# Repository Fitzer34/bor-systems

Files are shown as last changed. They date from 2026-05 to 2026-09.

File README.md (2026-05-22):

# HazardLink

IoT wet-floor-sign hangers that notify cleaners when a sign is lifted, with floor + zone, via mobile and web apps.

Full requirements live in [SPEC.md](SPEC.md).

## Repository layout

```
bor-systems/
├── SPEC.md                Product + technical requirements
├── docker-compose.yml     Local Postgres for development
├── backend/               Node.js + Fastify API, Postgres, FCM/SMS/email dispatch
├── web/                   Vite + React admin/dashboard
├── mobile/                Expo (React Native) iOS + Android app
├── firmware/              PlatformIO sketch for the RAK3172/STM32WLE5 hanger node
└── shared/                Code shared across components (LoRaWAN payload codec)
```

## Stack

| Layer | Choice |
|---|---|
| Backend | Node.js 20+, Fastify, TypeScript, Postgres, Drizzle ORM |
| Web | Vite, React, TypeScript, Tailwind, React Query, React Router |
| Mobile | Expo (React Native), TypeScript, React Navigation |
| Firmware | PlatformIO, Arduino framework, STM32WLE5 (RAK3172) |
| LoRaWAN network server | The Things Stack (Community for prototype) |
| Push | Firebase Cloud Messaging |
| SMS | Twilio |
| Email | SMTP (SES, Mailgun, etc.) |

## Getting started — local

### 1. Postgres

```sh
docker compose up -d
```

### 2. Backend

```sh
cd backend
cp .env.example .env
# Edit .env: set JWT_SECRET to something long and random, set TTS_WEBHOOK_SECRET.
# FCM/Twilio/SMTP creds optional — without them, alerts are recorded but not delivered.
npm install
psql "$DATABASE_URL" -f migrations/0001_init.sql      # one-time
npm run db:seed                                       # creates admin user + sample building/floors/zones
npm run dev
```

The backend listens on `:3000`. Default admin credentials are printed by `db:seed`.

### 3. Web dashboard

```sh
cd web
npm install
npm run dev
```

Opens at `http://localhost:5173`. The Vite dev server proxies `/api` to the backend.

### 4. Mobile app

```sh
cd mobile
npm install
npm start
```

Set `expo.extra.apiBaseUrl` in [`mobile/app.json`](mobile/app.json) to your machine's LAN IP so a device on the same WiFi can reach the backend (`localhost` won't work from a phone). Open the Expo Go app and scan the QR code.

## End-to-end test (no hardware)

You can simulate a hanger uplift without a real hanger by POSTing to the webhook:

```sh
# Encode payload: byte0=event(1=lifted), byte1=battery(85), byte2=fw(0x01=v0.1), byte3=flags(0)
PAYLOAD=$(printf '\x01\x55\x01\x00' | base64)

curl -X POST http://localhost:3000/webhook/tts \
  -H "Content-Type: application/json" \
  -H "X-BOR-Secret: $TTS_WEBHOOK_SECRET" \
  -d "{\"end_device_ids\":{\"dev_eui\":\"0011223344556677\"},\"uplink_message\":{\"f_port\":1,\"frm_payload\":\"$PAYLOAD\"}}"
```

Then send a `returned` event:

```sh
PAYLOAD=$(printf '\x02\x55\x01\x00' | base64)
curl -X POST http://localhost:3000/webhook/tts ...   # same headers, with the new payload
```

Register the hanger DevEUI in the **Hangers** page first, with a zone, so the alert has somewhere to go.

## Build phases

1. **Prototype:** 1 gateway + 2 hangers + this stack running locally — prove end-to-end alert path.
2. **Pilot:** 12 hangers, real install in target building, host backend on EU infra, real FCM/Twilio/SMTP creds.
3. **Production:** custom PCB, hardened backend, deployment to additional buildings.

## Deployment options

The backend and web are deployed to **Render** (see `render.yaml`) — tagged at `v0.1-cloud-deploy` for safe rollback. For the in-building **LoRaWAN gateway**, two options:

- **RAK7268V2** — turnkey hardware gateway (£170)
- **Raspberry Pi 5 + LoRa concentrator hat** — DIY, ~£100. Setup scripts and a status server live in [`pi/`](pi/README.md).

The Pi is a drop-in replacement for the dedicated gateway. The cloud backend is unchanged.

## Status

Functional end-to-end software stack. **Not yet tested with hardware** because no hangers exist yet. The webhook is shaped to accept The Things Stack uplinks; the firmware sketch is complete except for the LoRaWAN join + send and STM32 sleep calls, which need to be wired against the RAK3172 SDK once a board is in hand.

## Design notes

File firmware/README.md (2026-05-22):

# HazardLink — Firmware (Heltec WiFi LoRa 32 V3)

C++ firmware targeting the **Heltec WiFi LoRa 32 V3** (ESP32-S3 + SX1262). One
source tree, three build environments — selected via a PlatformIO build flag:

| Env | Role | Power | Radios used |
|---|---|---|---|
| `hanger` | Battery hanger (the default) | LiPo 18650/21700 | BLE (1st boot) + LoRa |
| `gateway` | One per building | USB-C mains | BLE (1st boot) + LoRa + Wi-Fi |
| `hanger_wifi` | Wi-Fi-direct hanger (no gateway needed) | USB-C mains | BLE (1st boot) + Wi-Fi |

## Repo layout

```
firmware/
├── platformio.ini          ; board, library, build-env definitions
├── include/
│   └── pinout.h            ; Heltec V3 GPIO assignments (single source of truth)
├── src/
│   ├── main.cpp            ; mode selector + RTOS entry point
│   ├── config/             ; persistent config in ESP32 NVS (replaces /etc/bor-hanger.env)
│   ├── battery.{h,cpp}     ; voltage divider read + LiPo curve + USB sense
│   ├── lora_link.{h,cpp}   ; RadioLib SX1262 wrapper, 12-byte event packets
│   ├── setup_mode/         ; NimBLE GATT server — Wi-Fi onboarding (matches iOS app)
│   ├── hanger/             ; battery hanger main loop (deep sleep + Hall wake)
│   └── gateway/            ; mains gateway main loop (LoRa rx → HTTPS forward)
└── README.md
```

## Build + flash

Install PlatformIO (`pip install platformio` or use the VS Code extension), then:

```sh
# Battery hanger
pio run -e hanger -t upload

# Gateway
pio run -e gateway -t upload

# Wi-Fi-direct hanger
pio run -e hanger_wifi -t upload

# Watch serial output
pio device monitor
```

The Heltec V3 has CDC-on-boot enabled, so the serial console is just `/dev/cu.usbmodem*` (macOS) or `/dev/ttyACM*` (Linux) — no driver install needed.

## First-boot flow (every SKU)

1. Power on. NVS has no Wi-Fi creds yet → `SetupMode::run()` advertises BLE as `BOR-Setup-XXXX`.
2. The iOS `HangerSetupView` connects and pairs (6-digit PIN derived from MAC, also printable on the hanger label).
3. iOS writes SSID + password + commit, hanger calls `WiFi.begin()`.
4. On success, hanger persists creds to NVS and reboots.
5. Subsequent boots skip BLE entirely and go straight to LoRa (or Wi-Fi).

The BLE service UUIDs are **byte-identical** to `pi/setup_mode.py` and the iOS `HangerSetupView` constants — the iPhone app works against either firmware without modification.

## Re-onboarding (customer changes router)

Long-press the test button (GPIO 6, default 10 s) → calls `Config::factoryReset()`, which wipes Wi-Fi creds but **preserves the DevEUI**. The hanger reboots, sees `isOnboarded() == false`, and re-enters BLE setup mode. DevEUI stays the same so the cloud doesn't lose its history.

## Payload (LoRa)

12 bytes, binary big-endian. Stays compatible with `shared/payload.ts` and the backend webhook decoder.

| Offset | Bytes | Field |
|---|---|---|
| 0 | 1 | `event_type` (1=lifted, 2=returned, 3=heartbeat, 4=low_battery, 5=cleaning_started) |
| 1 | 1 | `battery_pct` (0–100) |
| 2 | 1 | `flags` (bit 0 = is_charging, bit 1 = test_pressed) |
| 3 | 1 | `fw_version` (high nibble = major, low nibble = minor) |
| 4 | 8 | DevEUI suffix (ASCII hex, last 8 chars of the 16-char DevEUI) |

## Power budget (hanger, battery mode)

Targets for a 5000 mAh 21700 cell:

| State | Current | Duty cycle | Daily drain |
|---|---|---|---|
| Deep sleep (Vext off) | ~50 µA | 23h 59m | 1.2 mAh |
| Heartbeat wake (1/hour) | ~120 mA peak, 600 ms | 24 × 0.0007% | 1.2 mAh |
| Sensor event | ~120 mA peak, 600 ms | ~10/day | 0.5 mAh |
| **Total** | | | **~2.9 mAh/day** |

5000 mAh × 0.85 derate ÷ 2.9 mAh/day ≈ **1450 days theoretical, ~24 months realistic**.

## What's stubbed vs. fully implemented

| Module | Status |
|---|---|
| `config/nvs_store.{h,cpp}` | ✅ Complete — NVS keys, DevEUI auto-derive, factory reset |
| `battery.{h,cpp}` | ✅ Complete — divider read, LiPo curve, USB sense |
| `lora_link.{h,cpp}` | ✅ Complete — HMAC-signed packets, seq + replay protection, ACK + retry |
| `setup_mode/` | ✅ Complete — NimBLE GATT server, BLE pairing, PIN on OLED, Wi-Fi join |
| `display.{h,cpp}` | ✅ Complete — SSD1306 wrapper, Vext-gated for low power |
| `button_handler.{h,cpp}` | ✅ Complete — short / long-press semantics, 10 s factory reset |
| `ota.{h,cpp}` | ✅ Complete — HTTPS manifest fetch + esp_https_ota + auto-rollback |
| `hanger/hanger.{h,cpp}` | ⚠️ Wake logic complete; verify on real hardware |
| `gateway/gateway.{h,cpp}` | ✅ Complete — Wi-Fi rejoin, OLED status, OTA every 6h |
| `hanger/hanger_wifi.{h,cpp}` | ⚠️ Basic loop; needs reconnect resilience tuning |

## Hardening (Batch 2)

The firmware now includes the production-grade features that close the gap between "demo" and "ship":

- **OTA updates** — gateways pull manifests every 6 h and self-update; failed boots auto-roll-back via the ESP32 bootloader.
- **HMAC-signed LoRa packets** — every uplink is HMAC-SHA256 keyed with a per-device secret. Spoofing requires the secret. Replays drop based on a per-DevEUI seq number.
- **LoRa ACK + retry** — the gateway ACKs every accepted packet; the hanger retries up to 3× with exponential back-off + jitter on no-ACK. ~99% delivery on first try, ~99.9% with retries.
- **Long-press re-onboarding** — hold the test button for 10 s → wipes Wi-Fi creds (preserves DevEUI) → reboots back into BLE setup. Used when the customer changes routers.
- **OLED status** — gateways show IP, RSSI, packets-forwarded and uptime; setup mode displays the pairing PIN so no sticker is needed.

## Known TODOs

- Cert-pin the backend HTTPS connection in `ota.cpp`, `gateway.cpp` and `hanger_wifi.cpp` (currently uses `setInsecure()` for prototyping).
- Per-customer firmware channels (manifest currently keyed by model only).
- Battery-mode hanger button wake (currently only the Hall sensor wakes; long-press factory reset only works on mains-powered SKUs for now).

## Co-existence with the Pi codebase

The `pi/` directory stays untouched — existing field installs continue to work unmodified. New customers ship with Heltec hardware running this firmware; existing customers can be migrated piecemeal. Both firmwares POST to the same `/webhook/tts` endpoint with the same payload shape.

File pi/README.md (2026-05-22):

# HazardLink — Raspberry Pi

The same Pi codebase can run in **two roles**. Pick the one that fits the building.

| Role | Pi acts as | Reaches backend via | Best for |
|---|---|---|---|
| **Gateway** | A shared LoRaWAN gateway for many battery-powered remote hangers | LoRa radio → The Things Stack → cloud webhook | Big buildings, patchy WiFi (basements etc.) |
| **Hanger** | The hanger itself, microswitch on GPIO | Building WiFi → HTTPS straight to cloud | Buildings with strong WiFi everywhere |

Both write to the same cloud, same dashboards, same iOS app. You can mix roles within one deployment.

Install with one command after cloning the repo on the Pi:

```sh
sudo python3 install.py --role gateway   # one Pi serving many remote hangers
# or
sudo python3 install.py --role hanger    # this Pi IS a hanger
```

## What you need

- A **Raspberry Pi 5** (4 GB is plenty) with power supply
- A **microSD card** (32 GB+ recommended)
- A **LoRa concentrator hat or USB stick** for EU868 — e.g. RAK2287 USB or RAK5146 PCIe
- The Pi connected to your office network (WiFi or Ethernet)
- Your Mac on the same WiFi for the initial setup

## 1. Flash Raspberry Pi OS with WiFi pre-configured

This is the trick to skipping monitor/keyboard setup — you preset the WiFi and SSH credentials at flash time.

1. Download **Raspberry Pi Imager**: https://www.raspberrypi.com/software/
2. Insert the SD card, open Imager
3. **Choose Device** → Raspberry Pi 5
4. **Choose OS** → Raspberry Pi OS (64-bit) (Bookworm or newer)
5. **Choose Storage** → your SD card
6. Click **Next**, then **Edit Settings** when it asks "Would you like to apply OS customisation?"
7. In the General tab:
   - **Hostname**: `borpi` (we'll use this as `borpi.local`)
   - **Username**: `owen` (or whatever)
   - **Password**: pick something
   - **Configure wireless LAN**: tick this, enter your home/office WiFi SSID + password, country `IE` (or `GB`)
   - **Set locale**: Europe/Dublin (or your timezone)
8. In the **Services** tab:
   - ☑ Enable SSH → **Use password authentication**
9. Click **Save**, then **Yes** to apply, **Yes** to erase the SD card

Imager flashes everything in ~5 minutes. When it's done, **insert the SD card into the Pi 5, plug in power**, and walk away for 90 seconds while it boots.

## 2. Connect to the Pi from your Mac

From a Terminal on your Mac:

```sh
ssh owen@borpi.local
```

(Replace `owen` if you used a different username. The `.local` suffix uses macOS's built-in mDNS — works out of the box.)

If `borpi.local` doesn't resolve, run our helper to find the Pi by IP:

```sh
python3 ~/Downloads/bor-systems/pi/find_pi.py
```

It scans your local network and prints the Pi's IP address.

You should now see a prompt like `owen@borpi:~$`. **You're on the Pi over WiFi.**

## 3. Install HazardLink on the Pi

On the Pi (i.e. through the SSH session you just opened):

```sh
sudo apt update && sudo apt install -y git python3-pip
git clone https://github.com/Fitzer34/bor-systems.git
cd bor-systems/pi
sudo python3 install.py
```

The installer:

- Installs build tools and Python deps
- Sets up a small Flask **status server** on port 8080 (you can hit it from any browser on the same WiFi at `http://borpi.local:8080`)
- Registers it as a systemd service so it auto-starts on reboot

When the LoRa concentrator hat or USB stick is plugged in, run the gateway-specific configuration step (see `install.py --help`).

## 4. Test it over WiFi

After install.py finishes, on **any device on the same WiFi** (your Mac, your phone), open a browser:

```
http://borpi.local:8080
```

You should see the BOR Pi status page with:

- Pi system info (CPU, memory, uptime)
- Whether the LoRa concentrator is detected
- Last 50 LoRaWAN packets received (when hardware is connected)
- Connection status to the cloud backend

## 5. Send a fake hanger event (works without hardware)

Useful to verify the cloud backend is reachable from the Pi — and to see the full pipeline end-to-end before the real LoRa hardware arrives.

On the Pi (or your Mac):

```sh
cd ~/bor-systems/pi
python3 hanger_sim.py lift --devEui 0011223344556677
# wait a few seconds
python3 hanger_sim.py return --devEui 0011223344556677
```

This POSTs a simulated LoRaWAN uplink to the cloud backend's webhook. If you've registered that DevEUI in your org, you'll see the alert appear in the web dashboard and on the iOS app within 5 seconds.

## Files in this folder

| File | What it does | Where it runs |
|---|---|---|
| `install.py` | Bootstraps the Pi — installs deps, sets up systemd services, configures the status server | Pi |
| `status.py` | Flask app showing Pi/gateway/connection status on port 8080 | Pi |
| `hanger_sim.py` | Sends fake LoRaWAN uplinks to your cloud backend so you can test without hardware | Pi or Mac |
| `find_pi.py` | Scans LAN for the Pi (when `.local` resolution doesn't work) | Mac |
| `requirements.txt` | Python deps (Flask, requests) | Pi |
| `services/bor-status.service` | systemd unit for auto-starting the status server | Pi |
| `lora_config/global_conf.json` | Semtech packet forwarder config for EU868 + RAK2287 | Pi |

## Fully-self-hosted option

If later you decide you want the **whole stack** (backend + DB + web) on the Pi instead of Render, the path is:

1. Run `sudo docker compose up -d` in the repo root on the Pi (uses the existing `docker-compose.yml` for Postgres)
2. Run the backend via `cd backend && npm install && npm run build && node dist/index.js`
3. Build the web app: `cd web && npm install && npm run build`, then serve `web/dist` via the status server's nginx config
4. Optionally: use Cloudflare Tunnel to expose the Pi to the internet (so your iPhone app can reach it from outside the building)

That's more work; the **hybrid (gateway-only)** setup above is recommended for the prototype.

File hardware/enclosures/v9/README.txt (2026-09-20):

HazardLink v9.10 enclosures. Every size that matters comes from the maker's own drawing, 3D file or listing, and nobody is asked to measure anything (see WHERE THE SIZES COME FROM). No screws between the parts; every part clipped in even with the lid off; wall-arm latches; flush display behind a window centred on the picture; USB-C at the edge (lid on); two finger pads; white logo and names on a black face; white hook bar that prints with no support; bare Hall sensor held by two filament pins; cleaning-mode push button under the base of the hanger. Generated by hazardlink_enclosures.py.
Frame: X right, Z up, Y from the body rim (Y=0) into the wall. The lid's outer face is at Y=-3, the wall face at Y=45.
Places on the board are given as Xb and Yb (see WORDS USED).
If you are building a hanger, read WORDS USED, then go to HANGER ASSEMBLY ORDER and follow it from the top.

WORDS USED IN THIS FILE
  front, back, left, right, top, bottom: as you see the box hanging on the wall. The front is the lid, the back is the wall
    side. "Forward" means toward the open front of the box (toward you). The floor of the box is the inside of its bottom wall.
  body: the open box. lid: its front cover. backplate: the flat plate that is screwed to the wall. The body hangs on it.
  hook bar, or just "the bar": the T-shaped part under the box that the sign hangs on. From the top down it has a dovetail
    plate (a flat tongue with sloping sides), a web (the narrow upright neck) and the wide bar itself, with a lip at the front.
  saddle: the shallow trough across the top of the bar. The top edge of the sign's hand hole rests in it.
  cable tie saddle: a different thing. It is a small block on the back wall of the box, below the board, with a tunnel
    through it for a cable tie. It has nothing to do with the saddle on the bar.
  tunnel and nest: the tunnel is the flat passage inside the bar, open at the back of the bar. The nest is the snug pocket
    at its far end, under the middle of the saddle, where the lift sensor sits.
  channel strip: the raised strip in the floor of the box that the hook bar slides into. The slot in its roof lets the
    sensor's wires up into the box.
  bulkhead: the thick shelf across the inside of the box above the battery. It has three openings: a slot in the middle,
    near the front, for the sensor and button wires, and a notch at each end, against the side walls, for the two battery
    wires. All three are CLOSED holes, shut in on every side, so a wire cannot be slipped in from the front: it has to be
    threaded through end first.
  bay under the battery: the empty space between the floor of the box and the battery holder. It holds only the
    cleaning-mode button and wires.
  latch arm: one of two springy strips cut into the bottom wall of a body. The lid's two hooks click into them. The small lip
    under each arm's tip is what you pull to open the lid.
  pegs and catch: four mushroom-shaped pegs on the backplate carry the body. The catch is a springy tongue in the middle of
    the backplate with a bump (the nose) that clicks into a window in the back wall of the body, so the body cannot be lifted
    off until the nose is pushed back.
  board: the Heltec WiFi LoRa 32 V3 circuit board. PRG and RST are its two small buttons. Its underside is the side without
    the display. J3 is the row of 18 solder holes along its long edge on the PRG button's side.
  PCB: the bare circuit board itself, without the parts on it. "Above the PCB" means upward from its display side.
  Xb and Yb: a place on the board. Xb is millimetres along the board from its USB end. Yb is millimetres across the board
    from its centreline: plus is toward the PRG button (upward in the hanger), minus is toward the RST button.
  picture: the part of the display's glass that lights up (the maker calls it the active area). The glass is bigger than
    the picture, and the picture does not sit in the middle of the glass.
  bezel: the thin skin of lid that is left in front of the display, round its window.
  coil antenna: the small gold spring that stands up from the board between the PRG button and the display. It is the WiFi
    antenna. Nothing may touch it or squash it.
  flex tail, flex fold: the thin brown ribbon that joins the display's glass to the board. It folds over the board's long
    edge on the RST side (the lower edge in the hanger) and tucks under the board. Never press on that fold.
  nozzle 1, nozzle 2: the printer's two print heads (PRINT.md calls them hotends). Nozzle 1 has the WHITE filament and
    nozzle 2 the BLACK filament.
  firmware: the program that runs on the board. Flashing means loading it onto the board over the USB-C cable.
  GND, 3V3, GPIO3, GPIO6: the names of four solder holes in Heltec's pinout picture of the board. GND is ground (zero volts),
    3V3 is the board's 3.3 volt supply, GPIO3 and GPIO6 are two signal pins. HIGH means close to 3.3 volts, LOW means close
    to zero.
  U.FL pigtail: the thin antenna cable with a tiny press-on plug. The plug presses onto the board. The other end is a
    threaded SMA jack that the antenna screws onto.
  JST 1.25 cable: the battery cable. It has one tiny 2-pin plug, which fits the battery socket on the underside of the board,
    and two loose wire ends.
  Hall sensor, or lift sensor: the small black 3-leg part in the bar that senses the magnet on the sign. Its MARKED face is
    its front face, the one with 32FA printed on it. VCC is its supply leg, GND its ground leg and OUT its output leg.
  push-pull: the sensor drives its output wire both HIGH and LOW by itself, so it needs no extra resistor.
  momentary: a momentary button is on only while it is held in.
  lead: a wire, or a few wires together, going from one part to another. tail: a short wire soldered to the board.
  heat shrink: thin plastic sleeve that shrinks tight when warmed. It insulates a solder joint. meter: a multimeter. Its
    continuity setting beeps when its two probes are joined through a wire or a closed switch.

NEW IN v9.10 (the shapes are final; this is what changed since v9.9)
  The sizes come from the makers. v9.9 still waited for caliper readings and photos. v9.10 waits for nothing: each size was
    taken from the maker's drawing, 3D file or listing, and the few that no maker publishes were derived and given a margin.
    WHERE THE SIZES COME FROM, near the end of this file, goes through them part by part. The proof on the real parts is
    one small test print, print/hanger_window_gauge.stl (see PRINTING).
  Screen window: it is centred on the PICTURE, at Xb 31.4, Yb +1.8, which is 1.8 mm toward PRG from the board's centreline.
    The panel maker's drawing (Heltec QG-2864KSWEG01, the same glass as Univision UG-2864HSWEG01) shows why: the picture is
    21.744 x 10.864 mm and sits 2.1 mm from the edge of the glass on the PRG side and 6.3 mm from the edge on the flex side.
    The opening is 24.0 x 13.1 mm (the maker's own view area is 23.744 x 12.864) and it is flared 45 degrees outward through
    the 1.0 mm bezel, so the edge rows of the picture are not hidden when you look from an angle.
  Coil antenna: Heltec's detailed 3D file puts its leg hole at Xb 13.08, Yb +7.24. Its body is about 2.9 mm across. Its
    height is 6.0 mm, give or take 0.5, and Heltec do not publish that figure (WHERE THE SIZES COME FROM says how it was
    derived). The lid has a round relief 6.5 mm across over the coil, under a 0.6 mm skin of face, with air left above even
    a coil 0.5 mm taller than nominal. The coil now sets how far back the board sits: the PCB top is at Y=4.4, and a nominal
    5.1 mm glass sits 2.3 mm below the face. Nothing may touch or squash the coil: Heltec say a squashed spring antenna
    makes the board reset.
  PRG and RST pads: each is 8.0 x 17.5 mm and stops at Xb 10.3, short of the coil antenna, so no pad is over the coil. The
    pad names run up the left side of each pad. The hanger lid has NO LED light hole.
  Display's flex tail: it folds over the RST-side board edge between Xb 23.6 and 39.2. The rail under that edge, the lid rib,
    the board catch (now Xb 41 to 47) and the lead notch (now Xb 14.5 to 22.5) all keep clear of it, and the lid and the
    pocket wall are relieved there. The builder must not press on that fold. The display's clear carrier is held by three
    small screws whose heads stand proud under the board. The board rests only on its two long edges, so nothing touches them.
  Hook: the bar is 88 mm wide, the seat is 42 mm for a folded sign up to 38 mm thick, the bar hangs 46 mm below the
    body and reaches 86 mm out from the wall face. There are no gussets at the root of the lip any more, because a folded sign
    fills the seat right up to the lip. The Hall sensor sits under the middle of the seat (Y=-11). A wider 108 mm bar for the
    generic UK and Irish moulding alone is one parameter (BAR_W).
  Button: from Gebildet's own listing drawing it is 46 mm overall with its socket, which leaves 44.5 mm behind the head. So
    the hanger body is 174 mm tall (v9.9 was 171), the lid 100 x 174 and the backplate 90 x 168. The button's LED is a
    12 to 24 V type per the listing, so it will not light from the board's 3.3 V. Only the two switch wires are used.
  Battery holder: the BeiLaMoo BH18650-PC2 is a copy of the MPD BH-18650-PC, and MPD's drawing gives the pins: 3.30 mm long,
    2.40 mm in from each end, flat tabs 1.52 x 0.38 mm. The 5.0 mm standoff behind the holder is kept.
  Colours (Owen's choice): nozzle 1 = WHITE PLA, nozzle 2 = BLACK PLA. Body, lid, backplate and test pieces are black. The hook
    bar is white. The lid lettering (badge, HazardLink, PRG, RST) is the white inlay print/hanger_lid_inlay.stl, merged with
    the black lid. PRINTING has the detail.
  AutoCAD and Fusion views refresh with no clicking: see ../autoload/README.md.
  A hanger body, lid or backplate printed from v9.9 or earlier does not fit these, and an older hook bar has the old narrow
    seat. Print them all from the v9.10 files. The gateway box is the same size as before; its window and pads follow the
    same board figures.

THE CLEANING-MODE BUTTON UNDER THE BASE, AND THE TALLER HANGER BOX
  A cleaning-mode push button is FITTED under the base of the hanger. It is Owen's Gebildet 16 mm momentary LED waterproof
  button (6 bought on Amazon UK). Its sizes are from Gebildet's own listing drawing: M16 thread, a head 18.8 mm across, and
  46 mm overall with its blue plug-in wire socket pushed on, which leaves 44.5 mm behind the head. The socket has five wires.
  3.2 mm is allowed under the base for the head on its sealing ring. The button goes through a 16.4 mm hole in the
  BOTTOM wall of the hanger body at x=83.8, Y=21.3: behind the right-hand latch arm, clear of the channel strip, pointing DOWN,
  above the hook, out of sight from the front. A cleaner reaches under the box from the right-hand side and presses it upward.
  There is about 42.8 mm between the button's face and the hook.
  With no button the battery holder sits only 7 mm above the bottom wall, far too little for a button that long. So the hanger
  box grows DOWNWARD by 44 mm: the hanger body is 174 mm tall (the box with no button is 130), the lid is 100 x 174 and the
  backplate 90 x 168. Every feature keeps its place counted from the TOP of the box. The bay under the battery is 48 mm high,
  from the floor of the box to the underside of the battery shelf: 44.5 mm for the button and its socket, 6 mm above that
  for the wires to turn, less the 2.5 mm bottom wall that the button passes through. It holds only the button and wires.
  The battery holder's lower ribs are a shelf standing off the back wall.
  Wires: the blue socket has five wires. Only the TWO switch wires go up to the board (one to GND, one to GPIO3). The other
  three are folded back, their bare ends covered, and tucked down in the bay. Two of those three feed the button's LED ring,
  which is a 12 to 24 V type per Gebildet's listing. The board's 3.3 V cannot light it, so the LED wires stay unconnected.
  Firmware: firmware/include/pinout.h reserves TEST_BUTTON_PIN = 3, which is GPIO3, as the cleaning-mode trigger, and
  firmware/src/hanger/hanger.cpp sets that pin up as an input with a pull-up (the pull-up holds the pin HIGH until the button
  joins it to GND). The hanger program does not act on a press yet: that part of the firmware is still to be written. So the
  button cannot be tested on the finished unit for now. The proof that it is wired correctly is the meter continuity check
  in HANGER ASSEMBLY ORDER, step 7.
  Two switches in PARAMS. BTN16_ON=False builds the old 130 mm box with no button. BTN16_USE_SOCKET must stay True: the
  model is not ready for a button with its socket left off. It would allow only 26.4 mm behind the head, and Gebildet's drawing
  gives 32.8 mm for the button without its socket, so the bay would come out too short.

FILES
  <part>.step / .stl / .png / _drawing.dxf   printable parts: hanger_body, hanger_lid, hanger_bar, hanger_backplate, gateway_body, gateway_lid
  print/                                        the same parts already turned into their print orientation (do not rotate them in the slicer),
                                                hanger_lid_inlay.stl and gateway_lid_inlay.stl (the WHITE lettering, nozzle 1),
                                                hanger_window_gauge.stl (the test print that proves the screen lines up),
                                                hanger_body_coupon.stl (test ring) and ORIENTATION.txt
  PRINT.md                                      the print recipe. It is the single source of truth for the slicer settings.
  hanger_assembly.step, gateway_assembly.step  named and coloured assemblies including the reference solids
  hanger_section.dxf, gateway_section.dxf      assembly stack-up sections
  *_exploded.png, *_assembled*.png, *_lid_off.png previews
  ref/                                          reference solids, not printed: board, cell, holder, Hall sensor (its file is still named
                                                hall_carrier), its two pins, magnet, sign handle, antenna, plug, the cleaning button
                                                (clean_button); window insert for the gateway only
  ref/hanger_window_insert.*                    leftover from an older revision (the hanger lid takes no insert). This script no
                                                longer writes it; delete it by hand.
  stages/                                       the assembly story for AutoCAD. This script does not write it: make_assembly_stages.py
                                                writes the STEP files and fusion_step2sat.py, run inside Fusion, converts them to .sat.
  sat_true/                                     true-surface ACIS files for AutoCAD for Mac. This script does not write them. A file in
                                                there that is older than hanger_body.step comes from an OLDER design: run
                                                fusion_step2sat.py in Fusion on the current STEP files before using it.
  autocad/                                      SAT and DXF solids from ../to_autocad.py. A run with --no-autocad does not write them,
                                                so check their dates against hanger_body.step in the same way.
  ../autoload/README.md                         how the AutoCAD and Fusion views refresh with no clicking (two small start-up files
                                                and three flag files)
  manifest.txt                                  bounding boxes and derived positions

HOW THE PARTS HOLD TOGETHER
  Lids (both units): two rigid hinge tabs on the lid's top edge reach 14 mm in and hook into pockets in a rib along the
    top wall. At the bottom the SPRING is in the body: two latch arms cut into the bottom wall (21 long x 10.5 wide x 2.0 thick,
    printed along their length so they bend along the layers, strain under 1.5 %). Each arm has a window; the lid carries a
    rigid 10 mm hook with a 1.0 mm barb that drops into it. No part of the latch on the lid flexes, so the lid has
    no thin finger to snap off.
    After printing, before the first lid goes on: push each arm tip OUTWARD once with a screwdriver (away from the inside of
    the box, the same way its pull lip moves when the lid is opened) to break its small breakaway tab. The tab is there so
    the arm prints cleanly. Fit: top tabs into the rib pockets, swing the bottom edge in until both hooks click.
    Open: pull the lip under one arm tip down about 1 mm with a fingernail or coin, ease that corner of the lid out, do the
    other, then pull the bottom edge out until the top tabs drop free, and take the lid away. The tabs drop free when the lid
    has tilted about 12 degrees. On the hanger lid (174 mm tall) that is with the bottom edge about 36 to 37 mm out. On the gateway
    lid (80 mm tall) it is about 16 to 17 mm. Never lever the lid against tabs that are still hooked.
  Display (hanger): the board sits right up behind the lid and the display module sits in a pocket in the lid, behind a
    1.0 mm bezel. This lid has NO window insert and NO cleats. The window is 24.0 x 13.1 mm, centred on the PICTURE at Xb 31.4,
    Yb +1.8 (x=34.9, z=149.8 on the box) and flared 45 degrees outward through the bezel. The picture is 21.744 x 10.864 mm, so
    about 1.1 mm of dark glass shows all round it, and the bezel hides the edges of the glass.
    How far back the board sits is set by the coil antenna beside the display, because the coil is the taller of the two.
    The PCB top is at Y=4.4. A nominal 5.1 mm glass then sits 2.3 mm below the face. The tallest glass the lid allows for
    (5.4 mm above the PCB, OLED_H_MAX; the panel maker's worst case is 5.25) would sit 2.0 mm below it. The pocket floor is
    6.4 mm above the PCB.
  Coil antenna (hanger): the small gold spring stands on the board between the PRG button and the display, at about Xb 12.7,
    Yb +7.3. It is about 2.9 mm across and 6.0 mm tall. The lid has a round relief 6.5 mm across over it, under a 0.6 mm
    skin of face. That leaves 0.8 mm of air over a nominal coil and 0.3 mm over one that is 0.5 mm taller. NOTHING MAY TOUCH OR
    SQUASH THE COIL: Heltec say a squashed or covered spring antenna makes the board reset. Do not bend it, stick nothing to
    it and keep every wire away from it. In the script, hanger_geom takes the deeper of what the display needs and what the
    coil needs, and a value that takes away either clearance fails the design check before any file is written.
  Display (gateway): the gateway lid is different. It still has the window insert pocket: a clear 36 x 19.5 x 1 mm pane
    fits from inside under the two cleats.
  Hook bar to hanger body: the bar's plate is a dovetail that slides into a channel in the body's bottom wall FROM THE WALL
    SIDE (channel 27.0 wide at the mouth, 34.0 at the top, 3.5 tall, 45 deg flanks; the plate has 0.45 mm clearance per
    side). The channel is closed at the front and the backplate covers its mouth, so with the body hung the bar cannot
    come out. The sign's weight is carried by the dovetail flanks (3.5 mm each side); no snap takes any of it. Nothing of
    the bar sits behind the body's back face, so the body still lifts the 14 mm it needs to come off the pegs with the
    bar fitted.
  Body to backplate: the backplate goes on the wall FIRST (see HANGER ASSEMBLY ORDER, job B2, for which way up). It carries
    four mushroom pegs. Offer the body up 14 mm high so the peg heads pass the keyhole circles (the circles are BELOW the
    pegs, slots running up) and let it drop; it hangs on the pegs. A spring tongue in the backplate's front face (8 x 24 mm,
    1.8 thick, fixed end at the bottom) carries a nose that springs into a 9.5 x 10.5 window through the body's back wall as the
    body drops home; the body cannot be lifted until the nose is pushed back through the window from inside, which needs the
    lid off. Same tamper resistance as the old security screw for that step.
  Tamper note: the lid opens by hand from underneath (two pull lips under the box). The enclosure has no lid switch: the
    one thing the unit can sense is the sign being lifted off the saddle.
  Face: the board sits against the left wall so the USB-C port is at the edge and a cable plugs in with the lid on. The
    opening is 14.0 x 8.0 mm in the left wall, shared by the body wall and a hollow in the lid edge, and the lid keeps a
    1.4 mm skin over the plug. On this board the port sits between the two buttons, so the two finger pads run down the
    left edge: PRG above the port, RST below it, each 8.0 x 17.5 mm. They stop at Xb 10.3, short of the coil antenna, so
    no pad is ever over the coil, and the pad names run up the left side of each pad. The display is left of centre and
    the badge balances it on the right. Each pad is a flap cut into the lid with a thin hinge at its far end and a pusher
    pin behind it over the board's small switch, so pressing anywhere on the pad clicks the switch.
    There is NO light hole in the hanger's face: the board's two small status lights (one is the charging light) are hidden with the
    lid on, and the display shows what the unit is doing. Take the lid off if you need to see the charging light.
    The badge, the HazardLink wordmark and the two button names are sunk 0.6 mm into the face as narrow strokes, and they
    are filled flush in WHITE over the black lid: load print/hanger_lid_inlay.stl with the lid (it is already lined up),
    give the lid to nozzle 2 (black) and the inlay to nozzle 1 (white) and merge the two models; the face then comes off
    the bed flush and smooth. Printed in one colour they are simply sunk lines. The gateway lid has its own
    print/gateway_lid_inlay.stl.
  Hook bar: T-shaped, printed in WHITE. The dovetail and web are narrow (web 26 mm); the bar below is 88 mm wide (BAR_W), so
    that it goes into the hand hole of every common sign. No maker publishes a hand-hole size. Scaled from the makers' own
    product photos, the narrowest common hole is the Rubbermaid FG6112xx at about 105 mm, then Carlisle at about 111 and
    the generic UK and Irish 620 x 300 moulding at about 120. So the sign has some room to sit to one side (about 17 mm in
    all in the Rubbermaid, 23 in the Carlisle, 32 in the generic moulding): hang it in the middle of the bar, where the
    sensor is. For a site that uses only the generic moulding, a 108 mm bar holds that sign more closely, and it is one
    parameter (BAR_W = 108).
    The seat (the saddle) is 42 mm from front to back, for a folded sign up to 38 mm thick, which is Rubbermaid's
    published closed depth and the thickest of the common signs. A sign stands 36 to 42 mm above the top of its hand hole,
    so the bar hangs 46 mm below the body and the top of the sign still ends 5 mm under the box. The bar reaches 86 mm out
    from the wall face, so a folded sign hangs wholly in front of the hook's gusset and of the button under the base. There
    are no gussets at the root of the lip: the sign fills the seat right up to the lip.
  Sensor lead (checked by audit_cable_route.py): along the tunnel in the bar; up the groove in the back of the web (the groove
    is open to the back so the wires lay in, except for one closed band half way up, opening 6 x 5 mm, that the wire ends have
    to be THREADED under); forward along the groove in the top of the dovetail plate; up through the slot in the channel roof
    (8 x 4 mm), which comes up UNDER the battery holder, into the bay under the battery; forward; up in front of the battery
    holder; through the slot in the middle of the bulkhead (8 x 4.4 mm); back to the cable tie saddle on the back wall; up through
    the notch in the lower wall of the board's pocket to the underside of the board.
  Button wires (checked by the same script): only the TWO switch wires make this journey. From the button's socket in the bay
    under the battery, forward and to the right, up past the right-hand end of the battery holder in front of it, along
    under the bulkhead to the slot in the middle of the bulkhead, up through that slot with the sensor lead, then to the
    join below the board with it. The socket's other three wires go nowhere: they are folded back, their bare ends are
    covered, and they are tucked down in the bay beside the socket.
  Battery wires (this route is NOT checked by audit_cable_route.py): the cable's plug stays ABOVE the bulkhead and its two
    loose ends go DOWN, one through the notch at each end of the bulkhead (each notch is about 7.5 x 20.5 mm), down the side of
    the box, in through the gap in the rib at that end of the holder, to the holder's pin at that end. Above the bulkhead
    the cable runs across to the cable tie saddle and up through the same notch in the lower wall of the board's pocket to
    the battery socket on the underside of the board. Each bulkhead notch is a closed hole: the front 12 mm of the bulkhead
    closes it. That is why the loose ends are fed through BEFORE they are soldered to the holder (assembly step 4).
  WHAT HOLDS EACH BOUGHT PART (checked by audit_retention.py: free travel in all six directions, target <= 0.5 mm)
    Everything below stays in place with the LID OFF as well (audit_retention.py with AUDIT_ARGS=--lid-off).
    Board: long edges on two rails, pocket walls each side, stops at both ends, and a 45 deg catch on each pocket wall hooked
      over the PCB's long edge (push the board straight in; lever its UPPER edge out with a fingernail to remove). With the
      lid on, two lid ribs also sit 0.3 mm over its header pad strips.
      THE DISPLAY'S FLEX TAIL folds over the board's LOWER long edge (the RST side) between Xb 23.6 and 39.2 and tucks under
      the board. Nothing in the box bears on it: the lower rail has a gap there, the pocket wall is relieved there, the lid
      rib on that side stops before it, the lid is hollowed over it, the lower catch stands beyond it (Xb 41 to 47) and the
      lead notch before it (Xb 14.5 to 22.5). DO NOT PRESS ON THAT FOLD, and never lever the board out by its lower edge: a
      creased or torn flex stops the display working.
      The display's clear carrier is held to the board by three small screws whose heads stand proud under the board. The
      board rests only on its two long edges, so nothing touches those heads. Do not pack anything under the board.
    Battery: Murata US18650VTC6 cell (18650) in the BeiLaMoo BH18650-PC2 holder (77.7 x 20.9 x 21.31 mm). It is a copy of the MPD
      BH-18650-PC, and MPD's drawing gives its two solder pins: flat tabs 1.52 x 0.38 mm, 3.30 mm long, one at each end,
      2.40 mm in from the end face. The holder stands on three ribs 5.0 mm off the back wall so its pins and the wires
      soldered to them have room (1.7 mm from the maker's pin tip to the back wall), inside ribs on four sides,
      with a snap arm at each end hooked 0.8 mm over its front face. The arms are slotted free of the end ribs so they can
      flex. With the lid on, two lid posts sit 0.3 mm in front of the holder's end blocks.
      THREAD, THEN SOLDER, THEN PRESS IN, in that order (HANGER ASSEMBLY ORDER, step 4). The battery cable is ONE 2-pin plug
      with two loose wire ends, and each wire has to pass through its own closed notch at one end of the bulkhead. Once both
      wires are soldered to the holder, the cable and the holder make a closed loop, and a closed loop cannot be threaded
      through two separate holes. So:
        first feed the two LOOSE ends DOWN through the two notches from the board's side, leaving the plug above the bulkhead;
        then, with the holder still OUT of the box, solder each wire to the SIDE of its pin and leave nothing standing beyond
        the pin tip. It has to be done before the holder goes in, because the pins end up behind the holder where no iron
        can reach;
        then press the holder straight in until both arms click, guiding each wire out through the gap in the rib at its end
        of the holder as it goes in, and draw the slack back up through the notches.
      Nothing is cut and nothing is joined to get the wires through.
      POLARITY: the battery lead is the 2-pin JST 1.25 cable with Heltec polarity (the Rokland order in SHOPPING.md). The wrong
      polarity destroys the board, and wire colour proves nothing. The + wire is found against the + and - printed beside the
      board's battery socket (job B5), and the soldered holder is checked with a meter and a cell before the plug ever goes
      into the board (step 4).
      ORDER MATTERS FOR THE OTHER WIRES TOO: the sensor lead slot in the channel roof is UNDER the holder, and the button's five
      wires leave the top of its socket pointing up at the holder's place. Fold the sensor wires forward and deal with all
      five button wires BEFORE the holder is pressed in (see HANGER ASSEMBLY ORDER).
    Cell: the holder's own spring contacts, plus two lid ribs 0.5 mm in front of it so it cannot leave the holder.
    Cleaning-mode button: its own nut. The head sits against the underside of the bottom wall and the nut (22 mm across its
      corners) clamps it from inside, in the bay under the battery, where it has room to turn between the side wall, the back
      wall and the channel strip. Fitting: push the bare button up through the hole from below, put its nut on from inside
      and tighten, then plug the blue socket onto its pins from inside. The socket will not pass through the hole. A spanner
      does not go round the nut in that corner (the nut's corners pass 0.2 mm from the back wall and 2.7 mm from the side wall):
      hold the nut with long-nose pliers and turn the button's head from below.
      Wires: the socket has five. Find the two switch wires with a continuity test (job B6). Go by the meter: wire colours
      prove nothing. Only those two go up to the board. The other three are folded back, covered and tucked down in the bay,
      all before the battery holder goes in.
    Hall sensor (the lift sensor): TI DRV5032FA in the TO-92 style (LPG) package, DigiKey part DRV5032FALPG, 25 bought. It is a
      bare flat 3-leg part, body about 4.1 x 3.0 x 1.5 mm. There is no carrier board. It is OMNIPOLAR, so either magnet pole works.
      From the TI datasheet SLVSDC7H (Table 5-1 and Figure 5-5): pin 1 = VCC (the supply, 1.65 to 5.5 V), pin 2 = GND, pin 3 = OUT.
      The output is push-pull and goes LOW while the magnet is present. The sensor switches on at 4.8 mT at most and off again
      at 0.5 mT at least, samples 20 times a second and draws about 1.6 microamps on average at 3 V. TI recommends a 0.1 uF
      capacitor from VCC to GND.
      WHICH LEG IS WHICH (confirmed): Owen's sensors are marked 32FA, and that datasheet lists 32FA as the part marking of the
      DRV5032FALPG. Its Figure 7-1 shows that the "top" of this package is its marked, bevelled front face, and Figure 5-5 is
      the view onto that top, with the pin numbers of Table 5-1. So hold the sensor with its MARKED face (32FA) toward you
      and its legs pointing DOWN:
          LEFT leg   = VCC, goes to 3V3
          MIDDLE leg = GND, goes to GND
          RIGHT leg  = OUT, goes to GPIO6 (HALL_SENSOR_PIN = 6 in firmware/include/pinout.h)
      Never find a leg by putting 3V3 on it and watching what happens. 3V3 on the OUT leg is outside TI's absolute maximum
      ratings and can damage the sensor.
      Legs: the first 3 mm of the legs behind the body must stay bare, straight and unsleeved, because that stretch passes
      between the two pins (the gap between them is 3.55 mm). Solder the three wires further back. Keep the joints slim,
      stagger them along the legs so that they do not sit side by side, and heat-shrink each one, because all three have to
      slide down a tunnel 8.6 mm wide and 3.0 mm tall.
      Fitting: hold the bar UPSIDE DOWN. The tunnel roof is then underneath and the sensor rides on it. The roof is one level
      from the back of the bar to the front of the nest (43.5 mm to the back of the nest), so there is no ramp to climb. The
      only break in it is a slot one 0.2 mm layer deep where the two pin holes open through, just short of the nest: if the
      sensor stops there, ease it back a little, keep it flat and push on. The floor has 45 degree ramps and the side walls
      funnel into the nest. The lead groove up the back of the web opens through the roof over the first 7.5 mm, so start the
      sensor on the roof just past it. Lay it with its marked face against the roof, legs pointing back, and push it forward
      by its wires until it stops in the nest under the saddle. Keep a light forward push on the wires and turn the bar UPRIGHT:
      the marked face now points UP, toward the magnet. Only then drop the pins in.
      Pins: TWO offcuts of 2.85 mm filament, 6.0 to 6.5 mm long. Never cut one longer, or the sign rests on the pins instead
      of the saddle (each hole is 6.6 mm deep). With the bar upright, drop one into each of the two holes in the saddle floor.
      They stand one each side of the legs, right behind the body, so the sensor cannot slide back. The sign's handle sits
      over them. Try both pins in their holes BEFORE the sensor goes in: each must drop in under its own weight and tip out
      again. The 3.1 mm holes open through the tunnel roof in printed stages, so no drilling is needed.
      If a pin hole is tight, ease it with a 3 mm drill bit, and do it like this. Wrap a flag of tape round the bit 6 mm from
      its tip. Twist the bit down the hole BY HAND ONLY, never in a power drill, and STOP when the tape reaches the saddle
      floor. Do not try to stop at the bottom by feel: under each pin hole is a 2 mm push-out and drain hole, the ledge round
      that smaller hole is what the pin stands on, and the ledge is only 1.4 mm thick. A drill that goes through it ruins
      the bar. Shake the chips out from the back of the bar. Never put a drill down a pin hole with the sensor in the bar. If
      a pin will not drop in with the sensor fitted, the sensor is short of home: push it forward. To get a pin out, push it
      up from below with a 1.5 mm rod through the 2 mm hole in the underside of the bar.
    Magnet: 6 x 2 mm N52 disc (TinyTronics), fixed to the sign so that it lies flat over the middle of the saddle when the
      sign hangs. Either face may point down. v9.10 has no printed holder for it yet (the word "tag" further down means that
      holder). For a first test, tape is enough. See MAGNET POSITION ON THE SIGN.
    Antenna: SMA bulkhead pigtail (the U.FL pigtail) and a stubby SMA antenna (about 9.5 dia x 47 long), both inside the box.
      Take the nut and washer off the pigtail's SMA jack. Slide the jack's threaded neck into the 6.6 mm slot in the small
      shelf on the right of the box from the FRONT, with the jack's flange under the shelf. Put the washer and nut back on
      top and tighten: the nut clamps the jack to the shelf. The antenna screws on above and its body snaps into the clip.
      For an outside antenna, push out the knock-out in the top wall and fit the jack there.
    Hook bar: dovetail flanks carry the load; closed channel end in front, backplate behind (about 0.5 mm play each way).
  Wall screws (4 in the backplate; 3 for the gateway, two in keyholes and one in the lower hole) are the only screws. They
  fix the units to the building. The SMA nut and the button's nut are part of the bought parts.

HANGER: the sign hangs from the bar under the bottom edge. Nothing on the face except the display window, the PRG and RST
pads and the logo and names (white, flush with the black face). The cleaning-mode button is under the base on the
right, pointing down. The web at the back carries the bar 46 mm below the body; the bar reaches 86 mm out from the wall face
and ends in a 20 mm lip; the sign's handle settles in the saddle, a seat 42 mm from front to back (Y -32 to +10) whose
middle is 11 mm in front of the body rim (Y=-11, which is 8 mm in front of the lid's outer face), directly over the Hall sensor.
The three Hall leads run along the bar, up the web, forward in a groove in the top of the dovetail plate, then up through the
slot in the channel roof (Y 6.5 to 10.5). That slot is under the battery holder (holder front face at Y 6.2): the leads come
up into the bay under the battery (48.1 mm clear between the channel strip and the holder), bend forward, stand up in the
6.2 mm space between the holder and the lid, and go through the slot in the bulkhead to the board.
Nothing from the bar or the button is soldered straight to the board. The board carries short tails from its J3 holes (hole 1
GND, hole 2 3V3, hole 17 GPIO6 for the sensor; hole 1 GND again and hole 14 GPIO3 for the button), and the leads are joined to
those tails below the board's pocket. The standard join is soldered wire to wire and sleeved with heat shrink, which needs
nothing extra. OPTIONAL: small wire-to-wire plug and socket pairs (JST-PH or similar: a 3-way pair for the sensor and a 2-way
pair for the button) let the board come out later without a soldering iron. They are on no order. SHOPPING.md lists them as
optional too.

HANGER ASSEMBLY ORDER (from a pile of parts to a sign hanging on the wall)
  The AutoCAD stage drawing (stages/) shows the body hung on the backplate before the holder and board go in. Follow THIS
  list: it fits everything on the bench first, because the battery holder needs a firm push to click in and its two wires
  are soldered right beside the box (step 4).
  YOU NEED
    Printed: hanger_body, hanger_lid (with its white lettering) and hanger_backplate in BLACK, hanger_bar in WHITE, and two
      offcuts of the 2.85 mm filament cut 6.0 to 6.5 mm long (the two pins, either colour).
    Bought (SHOPPING.md): the Heltec V3 board, the BH18650-PC2 battery holder, one 18650 cell, one DRV5032FALPG Hall sensor, one
      6 x 2 mm magnet, one 16 mm button with its nut and its blue plug-in socket, one 2-pin JST 1.25 battery cable, the U.FL
      pigtail and the stubby antenna, four No.8 countersunk screws with wall plugs. Also thin hook-up wire in three colours,
      thin heat shrink, a small cable tie, tape, and the 0.1 uF capacitor TI recommends for the sensor.
    Optional, on no order: a 3-way and a 2-way wire-to-wire plug and socket pair (JST-PH or similar). They keep the board
      removable without a soldering iron. Without them the joins below the board are soldered and sleeved, and the build is
      complete either way.
    Tools: soldering iron and solder, meter, small flat screwdriver, wire cutters and strippers, long-nose pliers (for the
      button's nut, where no spanner fits), a small spanner or the pliers for the antenna's nut, a 3 mm drill bit (turned by
      hand, only if a pin hole is tight), a round file (only if the button hole is tight), a torch, a marker and paper, a
      lighter or hot air for the heat shrink, a piece of string, and for the wall a drill, a level, a pencil and a
      screwdriver. A USB-C cable to power the board, and a computer set up for the firmware (job B0).
  BEFORE YOU START (bench jobs: the firmware, the printed parts, the backplate on the wall, the soldering that can be done on
  the bench, the button, the magnet)
    B0. Firmware. A new Heltec board runs the maker's demo program. Until the HazardLink hanger firmware from the repository's
        firmware folder has been loaded onto it (flashed), the unit can report nothing. The flashing steps are documented
        with the firmware, in firmware/README.md under "Build + flash" (it is a PlatformIO project, firmware/platformio.ini,
        and the hanger is its "hanger" environment; firmware/flash.sh is the helper script that goes with it). This file
        does not repeat them. Flashing is done over the USB-C cable. It can be done now, on the bare board, or later with
        the lid on, because the USB-C port is at the edge of the box.
    B1. Printed parts (PRINT.md, After printing).
        Latch arms: push each of the two arm tips in the bottom wall of the body OUTWARD once with a screwdriver (away from
        the inside of the box) to break its small breakaway tab.
        Pins: try both filament pins in the two holes in the saddle floor of the bar. Each must drop in under its own weight
        and tip out again. If one is tight, wrap a flag of tape round a 3 mm drill bit 6 mm from its tip, twist the bit down
        that hole BY HAND ONLY, and STOP when the tape reaches the saddle floor. Do not try to stop at the bottom by feel: the
        ledge the pin stands on, round the 2 mm hole underneath, is only 1.4 mm thick. Shake the chips out from the back of
        the bar.
        Tunnel: shine a torch into the tunnel from the back of the bar. It must be clean all the way to the nest.
        Dovetail: slide the bar's plate into the channel in the bottom wall of the body from the BACK of the body and out again
        a few times. If it is tight, see PRINT.md.
        Button hole: with its nut and its blue socket off, push a bare button up through the hole in the bottom wall from
        below. Its thread must pass freely. If it does not, see PRINT.md before using the round file.
    B2. Backplate on the wall. It goes up FIRST, on its own. Hold it against the wall with its four pegs pointing toward you.
        Right way up: the catch tongue in the middle of the plate has its fixed end at the BOTTOM, with its nose and its push
        pad toward the top. As a second check, the pegs are nearer the top: the upper pair is 22 mm below the top edge and
        the lower pair 96 mm above the bottom edge. Before drilling, hold the body against the plate and see that the four
        pegs line up with the four keyholes in the back of the body. Leave room on the wall: the box overhangs the plate by
        3 mm at top and bottom and 5 mm each side, the body has to start 14 mm above its final place to go on, and the hook bar and
        the whole sign hang below. Level the plate, mark the four holes, drill, fit the plugs, and drive the four No.8
        countersunk screws until their heads are flush: a head left standing proud keeps the body off the plate.
    B3. Board tails (soldering). Work on the UNDERSIDE of the board. J3 is the row of 18 holes along the long edge on the PRG
        button's side. Count the holes from the USB end: hole 1 is GND, hole 2 is 3V3, hole 14 is GPIO3, hole 17 is GPIO6. Check
        those names against Heltec's pinout picture for the WiFi LoRa 32 V3 before soldering. Fit these tails, each long enough
        to reach from its hole, across the underside, out through the notch in the lower wall of the board's pocket in the
        body and a little beyond (hold the board in front of its pocket, lay the string along that path and cut each tail
        to the string):
          hole 1 (GND): the sensor and the button share it. Twist two thin tails together into the one hole, or fit one
                        tail and join both GND wires to it later
          hole 2 (3V3): the sensor's supply          hole 17 (GPIO6): the sensor's output
          hole 14 (GPIO3): the button (TEST_BUTTON_PIN = 3 in firmware/include/pinout.h)
        Push each wire in from the underside, solder it, and trim its end flush on the display side, because the lid sits
        close over the board there. Label each tail with tape. If you are using the optional plugs and sockets, the socket
        halves go on these tails (a 3-way for GND, 3V3 and GPIO6, a 2-way for GND and GPIO3), but fit them after the sensor
        check in job B4, which uses the bare ends of the tails.
        The 0.1 uF capacitor goes between the 3V3 tail and the sensor's GND tail, at the far ends of the tails: solder one
        of its legs into each of those two joins when you make them (when you fit the 3-way socket, or in assembly step 7
        if you are joining wire to wire), and sleeve the joins so that the two legs cannot touch. There is no room
        for it in the bar.
    B4. Hall sensor (soldering). The leg order is CONFIRMED, so nothing has to be found out by experiment. Look at the sensor's
        marked face: it must read 32FA. Hold the sensor with that MARKED face toward you and its legs pointing DOWN:
            LEFT leg   = VCC, which goes to the board's 3V3
            MIDDLE leg = GND, which goes to the board's GND
            RIGHT leg  = OUT, which goes to the board's GPIO6
        This comes from the TI datasheet SLVSDC7H: it lists 32FA as the marking of the DRV5032FALPG, its Figure 7-1 shows that
        the marked, bevelled face is the "top" of this package, and its Figure 5-5 (the top view) with Table 5-1 gives pin 1
        = VCC, pin 2 = GND, pin 3 = OUT. If a sensor is marked anything other than 32FA, stop and do not fit it: another
        part may have another leg order. Never put 3V3 on a leg to find out which leg it is. 3V3 on the OUT leg is outside
        TI's absolute maximum ratings and can damage the sensor.
        Choose three wire colours and write down which is VCC, which is GND and which is OUT. Cut the three wires long enough
        to go from the nest to the join below the board's pocket: lay the string along the route on the printed parts (Sensor
        lead, under HOW THE PARTS HOLD TOGETHER) and add some spare.
        Solder: hold the sensor as above, marked face toward you, legs down, and check each wire against your written list
        as you solder it: VCC colour on the LEFT leg, GND colour on the MIDDLE leg, OUT colour on the RIGHT leg. Leave the
        first 3 mm of each leg behind the body bare, straight and unsleeved. Solder the wires further back along the legs,
        stagger the three joints so that they do not sit side by side, keep each joint slim, and shrink a thin sleeve over
        each. All three have to slide down a tunnel 8.6 mm wide and 3.0 mm tall. Leave the far ends of the wires BARE, with no
        plug on them: they still have to be threaded under the closed band on the web (6 x 5 mm), up through the slot in
        the channel roof (8 x 4 mm) and up through the slot in the bulkhead (8 x 4.4 mm), and a plug may not pass.
        Check the finished sensor (safe, because it is already wired to the confirmed order). The USB cable is unplugged. Twist
        the bare end of the sensor's VCC wire onto the bare end of the board's 3V3 tail, and the bare end of its GND wire
        onto the bare end of a GND tail. Wrap a piece of tape round each twist so that the two cannot touch each other. The
        OUT wire is joined to nothing: wind its bare end round the tip of the meter's red probe, and hold or tape the black
        probe's tip on the GND twist. Set the meter to DC volts. Plug the USB cable into the board. With no magnet near, the
        meter reads HIGH, close to the 3.3 volt supply. Bring the magnet up to the sensor's marked face: the reading falls
        LOW, to about zero. Take the magnet away: it goes HIGH again. That is the only pass. If the reading does not follow
        the magnet like that, unplug the USB cable and check the marking, the leg order and your three joints against the
        list above. Do not swap wires to see what happens. When the check has passed, unplug the USB cable, untwist the two
        joins and take the tape off.
    B5. Battery cable and battery holder: find the + of each. NO soldering yet. The cable is the 2-pin JST 1.25 cable. Its two
        wires are soldered to the holder later, in assembly step 4, AFTER they have been fed through the bulkhead. If they
        are soldered now, the cable can never be threaded (Battery wires, under HOW THE PARTS HOLD TOGETHER).
        a. Find the cable's + wire. Unplug the USB cable from the board first. With nothing connected to the cable's loose
           ends, push its plug into the battery socket on the underside of the board. Look at the + and - printed on the
           board beside the socket and wrap tape round the wire that lines up with +. Then ease the plug out again by its
           plastic body, with a fingernail or the small screwdriver, never by its wires. Wire colour proves nothing.
        b. Find the holder's + end. The cell's + end is the end with the separate round cap and a ring of insulation round
           it; its - end is the plain flat bottom of the can. Put the cell in the holder, following the + and - marks
           moulded into the holder if it has them. Meter on DC volts, one probe on each of the holder's two pins. When the
           reading is positive, with no minus sign, the pin under the RED probe is the + pin. It should be the pin at the
           end where the cell's capped + end sits. Write + on that end of the holder with the marker, so that from now on
           the cell always goes in with its + end there. Take the cell OUT.
        c. Decide which way round the holder goes, and see that the wires are long enough. The printed frame is the same at
           both ends, so the holder fits either way round. This build puts its + end on the LEFT, so that every unit is the
           same. The taped wire will go down through the LEFT notch of the bulkhead to the left pin, the other wire down
           through the RIGHT notch to the right pin, and the right-hand wire has the longer way to go. Lay the string along
           each route on the printed body (Battery wires, under HOW THE PARTS HOLD TOGETHER), from the battery socket's
           place under the board to the holder's pin, and compare it with the cable. If a wire is too short, lengthen it
           now at its loose end with hook-up wire, soldered and sleeved. Keep the join slim: it has to pass down through
           the notch. If it is the taped wire, put tape on its new end as well.
    B6. Button: sort out its five wires. Plug the blue socket onto the button on the bench. Set the meter to continuity
        (the beep setting) and try the five wires in pairs until you find the pair that beeps only while the button is held
        in. Those are the two switch wires. Gebildet's listing picture shows green and yellow as that pair, white as the
        switch's unused third contact and red and black as the LED. The same picture is used for several of their buttons,
        so go by the meter. Mark those two with tape. One will go to a GND tail on the board (the second one, or the
        shared one if you fitted only one in job B3) and the other to the GPIO3 tail, either way round.
        The other three wires are connected to nothing: they are the switch's third contact and the two LED wires. The LED
        ring is a 12 to 24 V type per Gebildet's listing, so the board's 3.3 V cannot light it and its wires stay
        unconnected. Fold each of the three back along the socket and cover its bare end with heat shrink or tape so that
        it can touch nothing.
        See that the two switch wires are long enough. Lay the string along their route on the printed body (Button wires,
        under HOW THE PARTS HOLD TOGETHER), from the button hole to the join below the board's pocket, and compare it with
        the two taped wires. If they are too short, lengthen them at their far ends with hook-up wire, soldered and
        sleeved. Keep the two joins slim and stagger them, because they have to pass up through the slot in the bulkhead
        (8 x 4.4 mm) beside the three sensor wires. Leave the far ends bare.
        Take the socket off the button again, because the socket will not pass through the hole in the box. If the socket
        has a latch lever on its side, press the lever while you pull. Pull on the socket's body, never on its wires.
    B7. Magnet on the sign. Fix one 6 x 2 mm magnet flat to the underside of the top edge of the sign's hand hole (the edge
        that will rest on the bar), half way along the hole and in the middle of the handle's thickness. Either face may
        point down. For a first test, tape is enough (see MAGNET POSITION ON THE SIGN).
  ASSEMBLY
  1. Sensor into the bar. Hold the bar UPSIDE DOWN, with the back of the bar (the end with the upright web) toward you. Lay
     the sensor on the tunnel roof, which is now underneath, marked face against the roof, legs and wires pointing back
     toward you, just past the first 7.5 mm where the web's groove opens through the roof. Push it forward by its wires until it
     stops in the nest. If it stops just short, at the shallow slot where the pin holes open through, ease it back a little,
     keep it flat and push on. Keep a light forward push on the wires, turn the bar UPRIGHT, and drop the TWO pins into the
     two holes in the saddle floor, one each side of the legs. Each pin must end up below the saddle floor. If one will not
     go down, the sensor is short of home: push it forward. Now let go of the wires.
     Thread the three wire ends up under the closed band half way up the back of the web, pull them through, press the
     wires into the groove below and above the band, and lay them forward along the groove in the top of the dovetail plate.
  2. Bar into the body. The channel strip is the raised strip in the floor of the box; its channel is open underneath and at
     the back of the body, and the slot in its roof is near its closed front end. From underneath, pass the three wire ends up
     through that slot so that they come out inside the box, in the bay under the battery. Then slide the bar's dovetail
     plate into the channel from the BACK of the body until it stops against the closed front end, drawing the slack of the
     wires up into the box as it goes so that no wire is pinched between the plate and the channel roof.
  3. Button into the base. Keep to this order, because once the button is tight there is too little room between the top of
     its blue socket and the battery shelf above to push the socket on. Take the nut off the button. From BELOW the box,
     push the button's threaded body only PART of the way up through the 16.4 mm hole in the bottom wall (on the right,
     behind the right-hand latch arm), just far enough for the nut to catch. If it came with a rubber sealing ring, the ring
     stays under the head, outside the box. From inside, in the bay under the battery, spin the nut on by a few turns with
     your fingers. Now, while the button still hangs low in its hole, push the blue socket onto the button's pins from inside
     until it is fully home. Then push the button up until its head sits against the underside of the box and spin the nut
     down with your fingers until it touches the wall (a spanner does not go round the nut in that corner). To finish,
     hold the nut still with the long-nose pliers from the open front and give the button's HEAD one last quarter turn
     from below. No more than a quarter turn, so the wires on the socket do not twist. Do not force it: the wall is plastic.
     If the socket has a latch lever on its side, finish with that lever facing the open front of the box, so that it can
     be pressed later to unplug the socket.
     Now deal with ALL FIVE of the socket's wires, because they leave the top of the socket pointing up at the battery
     holder's place. Fold the three unused wires (folded back and covered in job B6) DOWN beside the socket and see that
     they stay down in the bay, below the shelf that the battery holder will sit on. Lay the two taped switch wires forward
     (toward the open front of the box) and to the right.
  4. Battery cable through the bulkhead, its wires onto the holder, then the holder in. Keep to this order. Each notch at the
     ends of the bulkhead is a closed hole and the cable has one plug, so once both wires are soldered to the holder nothing
     can be threaded any more.
     a. Clear the holder's place. Bend the three sensor wires FORWARD where they come up out of the channel strip. See that
        the button's three unused wires are down in the bay and that its two taped wires lie forward and to the right
        (step 3). Every wire must end up in FRONT of the battery holder, none behind it.
     b. Thread. Each notch is at the very end of the bulkhead, against the side wall, and starts 12 mm back from the front
        edge of the bulkhead. Hold the battery cable above the bulkhead, on the board's side of it, plug uppermost. Feed the
        loose end of the TAPED (+) wire DOWN through the notch at the LEFT end of the bulkhead, and the loose end of the other
        wire DOWN through the notch at the RIGHT end. Pull both down until the plug lies just above the bulkhead. The plug
        stays above the bulkhead from now on. It is not plugged into anything yet.
     c. Solder, with the holder still OUT of the box. Rest the holder across the open front of the box, in front of its own
        place, with its + end (job B5) to the LEFT, turned so that its two pins face you while you solder. Solder the taped
        wire to the SIDE of the pin at the + end, on the left, and the other wire to the SIDE of the pin at the right-hand
        end. Leave nothing standing beyond the pin tip: only 1.7 mm is left between the pin tips and the back wall.
     d. Check with the meter. The meter decides, whatever the marks and colours say. Keep the cable's plug away from the
        board and from anything metal while the cell is in. Put the cell in the holder, its + end at the holder's + mark.
        Meter on DC volts, red probe on the pin with the taped wire, black probe on the other pin. The reading must be
        positive, with no minus sign. A minus sign means the taped wire is on the - pin. First see that the cell is the
        right way round, its capped + end at the holder's + mark. If it is, the holder was soldered the wrong way round:
        take the cell out, unsolder both wires, turn the holder end for end so that its + end is on the left, solder again
        and check again. Leave the wires in their notches. A reversed lead or a reversed cell destroys the board. Take the
        cell OUT again. It goes in last (step 9).
     e. Holder in. Turn the holder so that its open side (where the cell goes) faces you and its two pins point at the back
        wall, + end still on the left. Press it straight back into its place (the ribbed frame on the back wall, between the
        bay and the bulkhead) until both snap arms click over its front face. As it goes in, guide each battery wire out
        sideways through the gap in the rib at its end of the holder, and draw the slack back up through the notches from
        above. A wire left standing behind the holder's front face gets trapped behind the holder, and then the arms cannot
        click and the lid cannot close.
  5. Thread the wires upward. The bulkhead is the thick shelf across the inside of the box above the battery; its slot is in
     the middle, near the front. Stand the three sensor wires up in front of the holder, in the middle of the box's width,
     and thread them up through that slot. Take the button's two taped wires forward and to the right, up past the right-hand
     end of the holder in front of it, close to the right-hand wall, then along under the bulkhead to the same slot and up
     through it beside the sensor wires. The lid has two posts and two ribs that stand close to the front of the holder. The
     middle 22 mm of the box's width is clear of them, and so is the corner beside each side wall, so keep the wires to
     those places. Check that the button's three unused wires are still down in the bay. The two battery wires already run
     down through the end notches (step 4): draw any slack in them up above the bulkhead, so that no loop of battery wire
     lies in front of the holder.
  6. Antenna. The U.FL pigtail is the thin antenna cable with a tiny press-on plug at one end and a threaded SMA jack at the
     other. Take the nut and washer off the jack. From the FRONT, slide the jack's threaded neck into the slot in the small
     shelf on the right of the box, above the bulkhead, with the jack's flange UNDER the shelf and its cable hanging down.
     Put the washer and nut back on the thread above the shelf and tighten. Screw the antenna onto the jack from above and
     press its body back into the clip until it snaps in. The right-hand battery wire comes up through its notch just
     below this shelf: lead it past the jack's cable, in front of it or behind it, and see that it is not trapped under
     the bottom of the jack.
  7. Board. The cell is still OUT and the USB cable is unplugged. Hold the board in front of its pocket (top left of the
     box), display toward you, USB port to the left. Pass its tails down through the notch in the lower wall of the pocket.
     Bring the battery plug up through the same notch and push it into the battery socket on the underside of the board;
     check once more that the taped wire sits beside the + printed on the board. Push the board straight in until both
     catches hook over its long edges. Push with two fingers on the bare long edges of the board, near the USB end and near
     the far end. NEVER push on the display, on the coil antenna (the small gold spring beside the display) or on the brown
     flex tail that folds over the middle of the board's lower long edge, below the display. See that no wire lies against
     the coil antenna.
     Check the button before its wires are joined. Set the meter to continuity and put its probes on the bare ends of the
     button's two taped switch wires, where they come up through the bulkhead. It must beep only while the cleaning button
     (on the underside of the box's bottom wall) is pressed in, and stop when the button is let go. If it does not, the
     wrong pair was marked or the socket is not fully home on the button: go back to job B6. For now this is the proof
     that the button is wired correctly, because the firmware support for the button is still to be written.
     Join the wires below the pocket. Sensor: VCC wire to the 3V3 tail, GND wire to a GND tail, OUT wire to the GPIO6 tail,
     using the colours you wrote down in job B4 (the confirmed leg order, marked face toward you and legs down, is LEFT =
     VCC, MIDDLE = GND, RIGHT = OUT: TI datasheet SLVSDC7H, Figures 7-1 and 5-5 with Table 5-1). The 0.1 uF capacitor's two
     legs go in the 3V3 join and that GND join (job B3). Button: one taped wire to the GPIO3 tail, the other to a GND tail
     (the second one, or the shared one if you fitted only one in job B3). The standard way: slide a piece of heat shrink
     onto each wire first, solder wire to wire, then slide the sleeve over the joint and shrink it; leave enough spare to
     pull the ends out of the front of the box while you solder. Shrink every sleeve with the joint pulled well out in
     front of the box and the heat pointed away from the box, and keep the soldering iron off the printed parts. Printed
     plastic goes soft long before heat shrink tightens, and a warped rim or latch arm means printing a new body. A
     piece of card held between the joint and the box is enough protection. With the optional plugs and sockets, fit the
     plug halves to the threaded wires now instead. Gather the bundle and tie it to the cable tie saddle on the back wall below the
     pocket. Keep the bundle and the joins away from the small window in the middle of the back wall: the catch is released
     through it.
     Press the pigtail's small round plug (the U.FL plug) straight down onto its socket on the top of the board, at the end
     away from the USB port, until it clicks.
  8. Body onto the backplate, lid still off. Offer the body up to the backplate 14 mm higher than its final place, so that the
     four peg heads enter the round parts of the four keyholes in the back of the body. Press it flat to the plate and let it
     slide down 14 mm until the catch clicks. Try to lift it: it must stay down.
  9. Cell in, its + end at the holder's + mark. It is the last part to go in. The board starts up. With the hanger firmware
     loaded (job B0) its display lights for about a minute after every fresh start. With the maker's demo still on the
     board the display shows the demo instead, and the unit reports nothing until it has been flashed.
  10. Lid. Top tabs into the pockets under the top wall, then swing the bottom edge in until both hooks click. See that no
     wire is caught under the lid's edge and that the PRG and RST pads still click.
  11. Hang the sign on the bar through its hand hole, so that the top edge of the hole rests in the saddle with the magnet over
     the middle. The bar is narrower than the hand hole, so set the sign in the middle of the bar.
     Then check the lift sensor on the display. This needs the hanger firmware (job B0). Press the RST pad: the
     unit restarts and the display lights for about a minute (on a board's very first start it shows its registration
     number on a "Register hanger" screen for a few seconds first). The third line of the status screen ends in "Sign ON"
     while the sign hangs on the bar. Lift the sign off: within a second or two it reads "Sign LIFTED". Hang it back:
     "Sign ON" again. (These words come from showHangerStatus in firmware/src/hanger/hanger.cpp.)
     The cleaning button cannot be tested on the unit yet, because the firmware support for it is still to be written. The
     continuity check in step 7 is the proof that it is wired correctly.

HANGER SERVICE SEQUENCE (unit stays on the wall)
  0. Lift the sign off the bar. The unit senses this as a sign lift.
  1. Pull the lip under one latch arm down 1 mm, ease that corner of the lid out, then the other; pull the bottom edge out until
     the top tabs drop free (about 36 to 37 mm at the bottom edge) and take the lid away.
  2. The 18650 cell sits in its holder facing you: push it against the spring end and lift it out. Fit the new cell the same
     way round, its + end at the holder's + mark. A reversed cell destroys the board.
  3. To swap the board: take the cell out first. Pull the U.FL plug off the top of the board, lever the UPPER long edge of the
     board (the PRG side) out from under its catch with a fingernail, keeping off the coil antenna and never touching the
     flex tail on the lower edge, lift the antenna end, and ease the JST 1.25 battery plug out of the exposed
     underside by its plastic body, with a fingernail or the small screwdriver, never by its wires. Undo the joins between
     the board's tails and the sensor and button wires below the pocket (cut them if they were soldered, unplug them if the
     optional plugs were fitted). Lift the board out, drawing its tails up through the notch. No screws hold the board: it
     rests on the rails under the two catches. The new board needs the same tails (job B3) and the hanger firmware (job B0).
  4. To swap the cleaning button: hold the head still from below and undo the nut with the long-nose pliers, then spin it up
     the thread with your fingers as far as it will go and let the button drop down in its hole. Now there is room above the
     socket: reach into the bay under the battery and pull the blue socket off the button (press its latch lever if it has
     one, and pull on the socket's body, never on its wires). Take the nut right off and let the button drop out. Fit the
     new one as in assembly step 3. The socket and its wires stay in the box, so nothing has to be threaded again. The
     body stays on the wall.
  5. To swap the Hall sensor: take the cell out. Put a flat screwdriver on the catch's push pad (visible through the window in
     the back wall, above the nose), push it back about 3 mm, lift the body 6 mm, withdraw the tool, lift the remaining 8 mm and
     pull the body forward off the pegs. Undo the join between the sensor's three wires and the board's tails below the
     pocket; the board can stay in. If a plug was fitted and will not pass a slot, cut it off: it goes onto the new sensor's
     wires after they have been threaded. Draw the three wires back down through the bulkhead slot into the bay under the
     battery. Slide the bar slowly out of the back of the body, feeding the wires down into the slot in the channel roof
     from inside the box as it goes. Turn the bar over and tip the two pins out; if one sticks, push it out from below with
     a 1.5 mm rod through the 2 mm hole in the bar's underside. Slide the sensor out of the back of the bar, drawing its
     wires out from under the band. Prepare the new sensor as in job B4 and fit it as in assembly steps 1 and 2. The battery
     holder can stay in: the bay under it is open at the front, so reach in and bend the wires forward so that they rise in
     FRONT of the holder, then thread them up through the bulkhead slot and join them to the tails.
  6. Refit in reverse: bar in from the back, body offered up 14 mm high onto the pegs and dropped until the catch clicks. The
     cell is the last part to go in. Then the lid: top tabs in first, then the latches. If the unit needs a restart
     afterwards, press the RST pad.
  Off the wall in one line: lid off, push the catch pad, lift 14 mm, pull forward.

GATEWAY OFF THE WALL: lid off, remove the No.8 pan head at (60, 16) from inside, lift 10 mm, pull forward.

WHAT OPENS WITH WHAT
  sign off the bar: hands.   lid: fingernail or coin on the two lips underneath.   body off the backplate: lid off + flat screwdriver.
  bar out of the body: body off the wall.   gateway lid: the two lips underneath.   gateway off the wall: lid off + screwdriver.
  cleaning button out: lid off, its socket taken off from inside, its nut held from inside while the button is unscrewed from
  below, then the button drops out below.

GATEWAY SERVICE SEQUENCE
  1. Pull each arm lip under the box down 1 mm in turn, ease the lid's bottom edge out, and tilt the lid until the top tabs
     drop free (about 16 to 17 mm at the bottom edge of this shorter lid).
  2. Unplug the USB-C plug (cable stays tied to the saddle), pull the U.FL plug off the board, lever the UPPER long edge of the
     board (the PRG side) out from under its catch and lift the board off its rails. Keep off the coil antenna, and never
     lever or press on the lower edge, where the display's flex tail folds over it.

MAGNET POSITION ON THE SIGN (the figures a magnet holder on the sign has to be made to)
  Magnet: 6 x 2 mm N52 disc. On the bar centreline (x=50), centred on the saddle (Y=-11: 11 mm in front of the body rim,
  8 mm in front of the lid's outer face), flat face parallel to the saddle floor, facing down. EITHER pole: the DRV5032FA is
  omnipolar. The figures assume a holder (the "tag") that keeps 1.0 mm running clearance over the saddle floor and has a
  1.2 mm wall under the magnet (both are design choices). Air gap from the magnet's face to the top of the Hall sensor =
  4.15 mm. A magnet taped straight under the handle sits closer than that, which only makes the signal stronger.
  Before fixing the magnet for good, hold it over the saddle with the unit powered and the hanger firmware loaded, press the
  RST pad so that the display lights, and check that the third line of the status screen ends in "Sign ON" with the magnet
  there and "Sign LIFTED" with it taken away (assembly step 11). Last step of the build: hang the sign by its hand hole with
  the handle resting in the saddle, and check again.

PRINTING
  The recipe lives in PRINT.md, which is the single source of truth for the slicer settings. Summary: PLA, 0.4 nozzle, 0.2 mm
  layers (the first layer 0.2 mm as well), 4 walls (1.6 mm), 1.6 mm top and bottom, 60 to 100 % infill, 215 C, fan 100 %.
  PET-G is the alternative (+10 C, fan 30 %).
  Use the STLs in print/: they are already turned the right way up. print/ORIENTATION.txt lists each one's footprint and height.
  COLOURS (Owen's choice). NOZZLE 1 has the WHITE PLA and NOZZLE 2 has the BLACK PLA.
    BLACK, nozzle 2: hanger_body, hanger_lid, hanger_backplate, gateway_body, gateway_lid, and the two test pieces
      (hanger_window_gauge and hanger_body_coupon).
    WHITE, nozzle 1: hanger_bar (the hook under the box that the wet floor sign hangs on), and the lettering on both lids.
    Lettering: the badge, the HazardLink name and the PRG and RST names are a separate model, print/hanger_lid_inlay.stl
      (print/gateway_lid_inlay.stl for the gateway lid). Load it together with print/hanger_lid.stl: the two are already lined
      up, so do not move either. Give the lid to nozzle 2 (black) and the inlay to nozzle 1 (white), select both and merge
      them (Merge models). The marks are 0.6 mm deep, three layers, so the white stays solid white over the black and the face
      comes off the bed flush and smooth.
    Every other model gets its nozzle the same way in the slicer: the bar to nozzle 1, everything else to nozzle 2. The two
      filament pins that hold the sensor may be offcuts of either colour. They are out of sight under the sign's handle.
  PRINT ORDER. Nothing waits for a measurement. The sizes come from the makers' documents (WHERE THE SIZES COME FROM), and the
    first small print proves them on the real board.
    1. print/hanger_window_gauge.stl. It is small, and it is the proof on the real parts. Its three checks are further down.
    2. print/hanger_body_coupon.stl and one hanger_lid with its white inlay. Together they prove the latches, the hinge tabs,
       the lip and the USB opening, and the lid shows the white lettering.
    3. hanger_bar in white, then hanger_backplate and hanger_body. The gateway parts can go at any time.
  hanger_body: BLACK (nozzle 2). Back face down, open front up. It is 175 mm long on the bed. The dovetail channel runs along
    the print direction so its flanks print clean; its closed front end is a 27 to 34 mm bridge (turn the bridge settings on, see
    PRINT.md). The latch arms in the bottom wall each carry a small breakaway tab at the tip so they print cleanly; the hinge
    ribs grow from the bed and their nose pockets are 13 mm bridges; peg pocket roofs bridge 11.5 mm. The holder's shelf and
    snap arms and the board pocket walls with their catches stand straight up from the back wall. The button hole is a round
    hole through the bottom wall, which stands upright on the bed, so the top of the hole prints as an unsupported arch only
    as deep as the wall is thick (2.5 mm). If it sags, ease the hole with a round file until the button's thread passes.
    No support.
  hanger_lid: BLACK (nozzle 2) with the WHITE inlay (nozzle 1), outer face down. Only the lip, the rigid hooks and tabs, ribs,
    posts and the two pusher pins stand up from it. The hook's catch face is a 1 mm overhang; print the lid with the part
    fan on. The two finger pads print flat on the bed with 0.8 mm slots round them: keep brim out of the slots.
    No window insert: the display glass itself sits behind the bezel. The 0.6 mm skin over the coil antenna's relief
    is three layers on the bed. No support.
  hanger_bar: WHITE (nozzle 1). UPRIGHT on the bar's bottom face (lip pointing up), with NO SUPPORT AT ALL. All bending loads
    are then in-plane, the dovetail flanks and the spreaders are 45 deg, and a 45 deg gusset off the web carries the front
    17.4 mm of the dovetail plate. Never let the slicer generate support on this part: support inside the sensor tunnel, the nest or the
    pin holes cannot be got out again.
  hanger_backplate: BLACK (nozzle 2). Back face down. The catch cavity is open to the back face on purpose: let the slicer
    drop support through it under the tongue (touching the buildplate only) and pull it out afterwards. Pegs print vertical
    with a 45 deg cone under the head.
  gateway_body: BLACK, back face down. gateway_lid: BLACK with its WHITE inlay, outer face down.
  print/hanger_body_coupon.stl is the front 14 mm ring of the hanger body: rim, both latch arms with their hook windows, the
    front of the hinge ribs, the USB opening. It exists to test the lid latches and the hinge fit, so print it WHOLE and
    leave its bottom edge alone: that edge carries the latch arms. The small scallop in its bottom wall on the bed side is
    the front edge of the button hole and is meant to be there. Print it with one lid before any full body.
  print/hanger_window_gauge.stl is THE PROOF ON THE REAL PARTS. It stands in for every reading that v9.9 used to ask for:
    nothing is measured, the piece either passes or fails. It is the part of the lid round the display window and the two
    button pads, with low fences on the inside that hold the board exactly where the body will hold it. Print it in black,
    outer face down like the lid, no support. Lay the board in it face down, USB end against the two short stops, and press
    it flat with a fingertip on the bare back of the board, away from the brown flex tail that wraps round the long edge on
    the RST side. Three checks:
    1. The board lies FLAT on the two ribs and does not rock. A board that rocks is resting on its display or on its coil
       antenna. That is a fail: do not print the lid, and do not press the board down. The depth is then changed in the
       design (OLED_H_MAX and COIL in PARAMS).
    2. Turn it over with the screen switched on. The WHOLE picture must show inside the window with a dark border all
       round, about the same left and right. A picture that is cut off, or that touches one edge of the window, is a fail:
       do not print the lid. Which edge it was is all the design needs to move the window (OLED_ACT_CX, OLED_ACT_CY).
    3. Press the PRG pad and the RST pad from the front. Each must click its switch.
  No heat-set inserts and no machine screws. Wall fixings: 4 No.8 countersunk screws with plugs for the backplate, 2 No.8 pan
  heads for the gateway keyholes plus 1 for its lower anti-lift hole.

WHERE THE SIZES COME FROM
  Owen's rule for v9.10: the sizes come from the makers' own documents, and nobody is asked to measure, photograph or caliper
  anything. Each part below names the document that gave its numbers. Where no maker publishes a number, it says so, says
  how the number was derived and says what margin was added. The proof on the real parts is a small test print,
  print/hanger_window_gauge.stl (its three checks are under PRINTING). It passes or it fails, and it takes no measuring.
  Board (Heltec WiFi LoRa 32 V3): Heltec's own 3D files (the detailed board STEP and the assembly STEP) and their mechanical
    drawing. The outline (51.7 x 25.4 mm), the USB-C socket, the PRG and RST switches, the header holes, the battery socket and
    the antenna socket all come from those files. Heltec's datasheet sketch shows a shorter board (50.2 mm). Both of their
    3D files say 51.69 mm, and the pocket is made to the 3D files.
  Display: the glass is Heltec's QG-2864KSWEG01 panel, the same geometry as Univision's UG-2864HSWEG01. That drawing gives
    the picture (active area) 21.744 x 10.864 mm, the view area 23.744 x 12.864 mm and the borders of the glass: 2.1 mm on the
    PRG side, 6.3 mm on the flex side. Heltec's assembly STEP gives where the glass sits on the board (Xb 18.03 to 44.73, Yb
    -9.96 to +9.30) and the clear carrier under it (33.0 x 18.6 mm, Xb 14.88 to 47.88). Put together, the middle of the
    picture is at Xb 31.4, Yb +1.8, and the window is centred there.
    Margin: the opening is 24.0 x 13.1 mm, which leaves 1.12 mm round the picture. The worst the makers' tolerances add
    up to is 0.84 mm, so no row of the picture is cut off. The opening is drawn a little over the view area because printed
    holes close up a little.
    Height: Heltec's drawing and STEP put the top of the display 5.0 mm above the PCB. The panel maker's figures give a
    glass top of 5.1 mm nominal and 5.25 mm at worst. The lid keeps all its material 5.6 mm clear of the PCB over the display
    (5.4 allowed plus 0.2).
  Display's flex tail: Heltec's STEP and photos show it folding over the RST-side board edge between Xb 23.6 and 39.2.
    Margin: 1 mm is added at each end (Xb 22.6 to 40.2), and no rail, rib, catch or notch stands inside that stretch.
  Coil antenna, where it stands: Heltec's detailed STEP puts its leg hole at Xb 13.08, Yb +7.24, and that figure is exact.
    Its body, about 2.9 mm across, was scaled from Heltec's own photo of the board.
  Coil antenna, how tall it is: NO MAKER PUBLISHES THIS. Heltec give no coil height anywhere. It was derived as Heltec's
    5.0 mm display top plus about 1 mm, because a case maker (muzi.works) reports that the coil on the V3.2 board stands
    about 1 mm above the display. That gives 6.0 mm, and an earlier look at Owen's own board agreed.
    Margin: 0.5 mm is allowed on the height, then 0.3 mm of air is left over that worst case (0.8 mm over a nominal coil)
    under a 0.6 mm skin of face, and the clear circle round the 2.9 mm coil is 6.5 mm across. The coil is taller than the
    display, so the coil sets how far back the board sits.
  Sign and hook, the hand hole: NO MAKER PUBLISHES THIS. No sign maker gives the size of the hand hole. The widths were scaled
    from the makers' own product photos against their published overall sizes, which is good to about 6 to 8 mm: Rubbermaid
    FG6112xx about 105 mm (it could be as little as 92), Carlisle about 111, the generic UK and Irish 620 x 300 moulding
    about 120.
    Margin: the bar is 88 mm, 4 mm under even that low figure of 92. A bar that is too wide cannot be used at all, while a
    narrow one only lets the sign sit a little to one side.
    The height the sign stands above the top of its hand hole (36 to 42 mm) was scaled from the same photos. The bar hangs
    46 mm below the body, so the top of a sign that stands 42 mm still ends 5 mm under the box.
  Sign and hook, the thickness: this IS a maker's figure. Rubbermaid publish a closed (packaging) depth of 1.50 in, which is
    38 mm, the thickest of the common signs (the others are 30 to 33 mm). The seat is 42 mm, 4 mm more.
  Cleaning button (Gebildet 16 mm): Gebildet's own listing drawing. M16 x 1 thread for a 16 mm hole (printed 16.4), head
    18.8 mm across, 46 mm overall with the blue socket pushed on. Less the head (1.5 to 1.6 mm in the drawings of this button
    family) that is 44.5 mm behind the head, which is what the box allows, with 6 mm more above it for the wires to turn.
    The APIELE AP16B datasheet, for the same button family, agrees.
    Margin: an earlier reading of Owen's own button gave 42.5 to 43.0 mm, so 44.5 already carries 1.5 to 2 mm. The LED ring is
    a 12 to 24 V type per the listing. No maker publishes the cross-section of the blue socket (about 15.5 mm, or about 19
    with its latch, scaled from photos): the bay is open in front of it, and assembly step 3 turns the latch to the front.
  Battery holder: the BeiLaMoo BH18650-PC2 is a copy of the MPD BH-18650-PC. BeiLaMoo's listing gives the body, 77.7 x 20.9 x
    21.31 mm, the same as MPD's drawing. MPD's drawing gives the pins: flat tabs 1.52 x 0.38 mm, 3.30 mm long, 2.40 mm in from
    each end.
    Margin: MPD's tolerance is 0.5 mm either way, so the printed frame keeps 0.5 mm clear on each side. BeiLaMoo publish no pin
    drawing of their own and an earlier reading of Owen's holder gave about 4.3 mm, so 4.8 mm is allowed for the pins, and
    the 5.0 mm standoff was kept because it clears that.
  Cell: Murata's US18650VTC6 datasheet, maximum size 18.5 x 65.2 mm.
  Hall sensor: TI's datasheet SLVSDC7H for the DRV5032FA gives the leg order, the leg pitch and the electrical figures. The
    leg order is confirmed from the 32FA marking on Owen's sensors (Figures 7-1 and 5-5, Table 5-1): marked face toward
    you, legs down, LEFT = VCC, MIDDLE = GND, RIGHT = OUT. The body size (4.1 x 3.0 x 1.5 mm) was taken from the delivered part
    earlier, and the nest has clearance all round it.
  USB-C opening: the USB-IF standard allows a plug body up to 12.35 x 6.5 mm. The opening is 14.0 x 8.0 mm.
  Magnet: 6 x 2 mm N52 disc, from the packing slip.
  Antenna: no maker's drawing of it is on file. Its size (about 9.5 dia x 47 long) was read off the delivered part earlier.
    The clip is a snap fit round its body, and the slot in the shelf takes the SMA jack's threaded neck.
  Everything else (walls, clearances, the latches, the hinge tabs, the catch) is a design choice, marked "assumed" in PARAMS
    in the script. Those are not sizes of bought parts. The design rule checks prove them every time the files are
    generated, and the test coupon and the window gauge prove them in plastic.

STILL TO BE WRITTEN (in the firmware, outside these files)
  Acting on a press of the cleaning button. pinout.h reserves TEST_BUTTON_PIN = 3 and hanger.cpp sets the pin up as an input,
  but the hanger program does nothing with a press yet. The enclosure is ready for it.

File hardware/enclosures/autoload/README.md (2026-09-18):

# Showing the assembly in AutoCAD without any clicking

Two small start-up files do the work. Copies are kept here; the live ones sit in the Autodesk folders below.

1. `step2sat_auto.py` and `step2sat_auto.manifest` live in
   `~/Library/Application Support/Autodesk/Autodesk Fusion 360/API/AddIns/step2sat_auto/`.
   While Fusion is running it looks every few seconds for a file called `CONVERT_ME` in `v9/stages/` and turns every `.step` there into a true
   ACIS `.sat` in `v9/stages/sat_true/`, writes `DONE.txt` and removes the flag. A file called `SHOW_ME` (one STEP path per line, in `v9/` or `v9/stages/`) makes it open those models in new local documents, view set, nothing uploaded or saved. With no flag it does nothing.
2. `acaddoc.lsp` lives in
   `~/Library/Application Support/Autodesk/AutoCAD 2027/R26.0/roaming/@en@/Support/`.
   When AutoCAD opens any drawing and finds `LOAD_ME` in `v9/stages/`, it runs `v9/stages/assemble.scr`.
   Remove the flag afterwards, or every drawing you open will load the stages.

The whole refresh, from the `v9` folder:

```bash
~/.hazardlink/cadenv/bin/python make_assembly_stages.py
touch stages/CONVERT_ME && open -a "Autodesk Fusion"      # wait for stages/DONE.txt
echo "$PWD/hanger_assembly.step" > SHOW_ME                # optional: Fusion opens the full assembly
touch stages/LOAD_ME && open -a "AutoCAD 2027" stages/viewer.dxf
rm stages/LOAD_ME                                         # once the stages are on screen
```

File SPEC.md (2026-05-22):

# HazardLink — Wet Floor Sign Hanger Notification System

**Status:** Draft requirements (v0.1)
**Last updated:** 2026-05-06

## 1. Problem and goal

Cleaning staff in large buildings frequently leave wet floor signs on the floor after a spill is cleaned, where the signs themselves become the next trip hazard. HazardLink is an IoT product that holds wet floor signs in dedicated wall-mounted hangers; when a sign is lifted, the system notifies cleaners (with floor and zone) via mobile and web apps, and only closes the alert when the sign is physically returned.

## 2. Scope

**In scope (v1):**
- Battery-powered, wall-mounted hangers, one per zone.
- Detection of sign lifted / sign returned.
- Push notifications to Android and iOS, plus a web dashboard.
- Floor-plan and named-zone display in the app.
- Acknowledgement, escalation, manual closure (damaged/missing), reporting.
- Admin / Supervisor / Cleaner roles.
- 24/7 operation with per-user on/off-duty toggle.
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

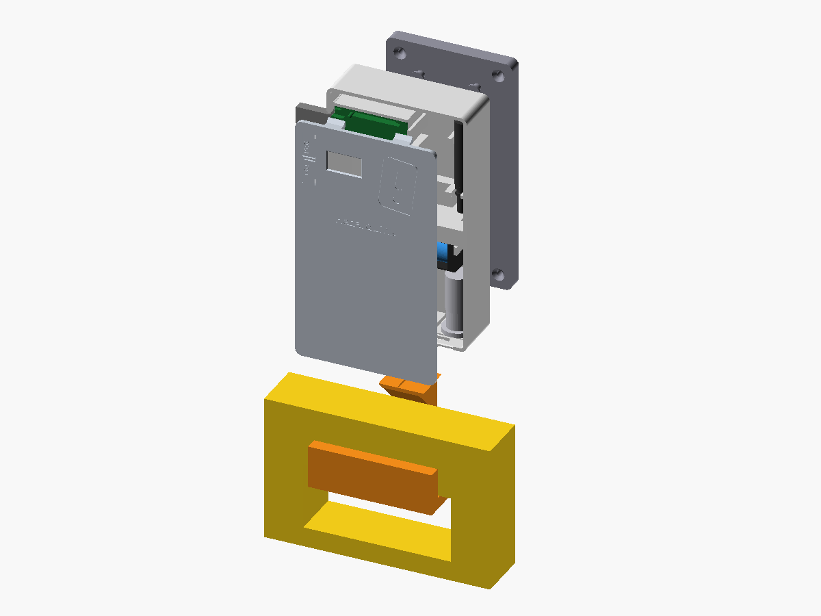
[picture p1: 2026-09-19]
hardware/enclosures/v9/hanger_exploded.png

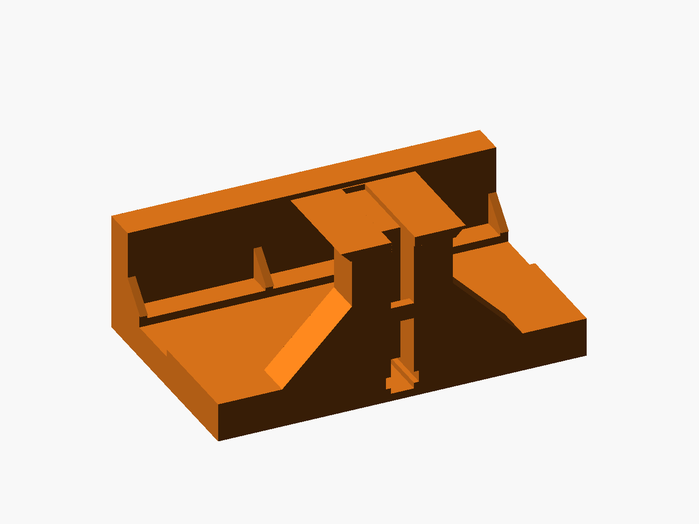
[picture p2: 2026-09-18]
hardware/enclosures/v9/closeups/finished_bar.png

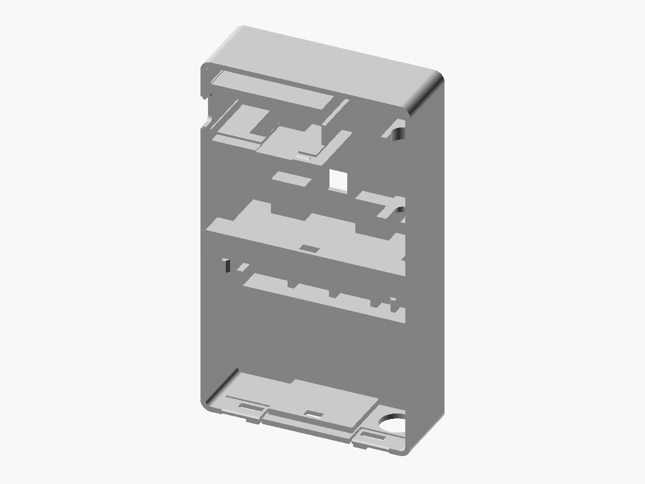
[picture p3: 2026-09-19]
hardware/enclosures/v9/hanger_body.png

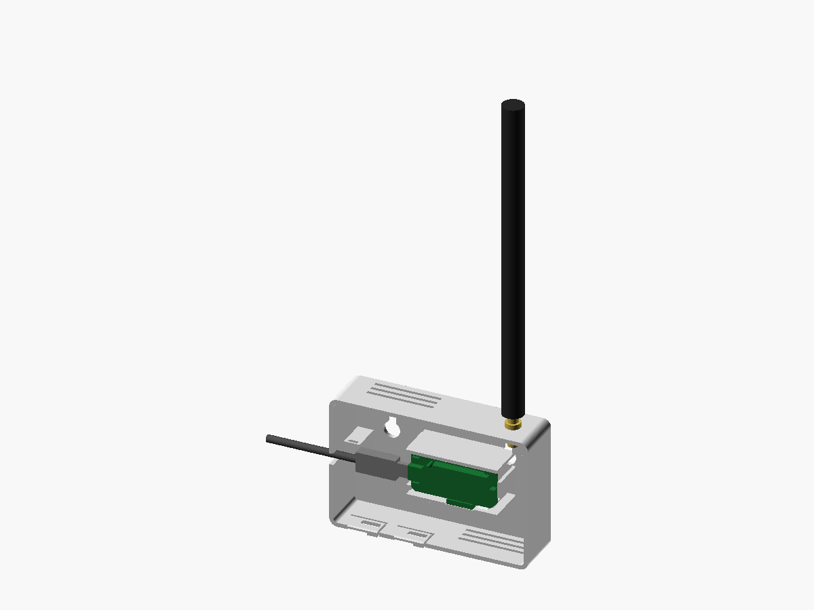
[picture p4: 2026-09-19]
hardware/enclosures/v9/gateway_lid_off.png

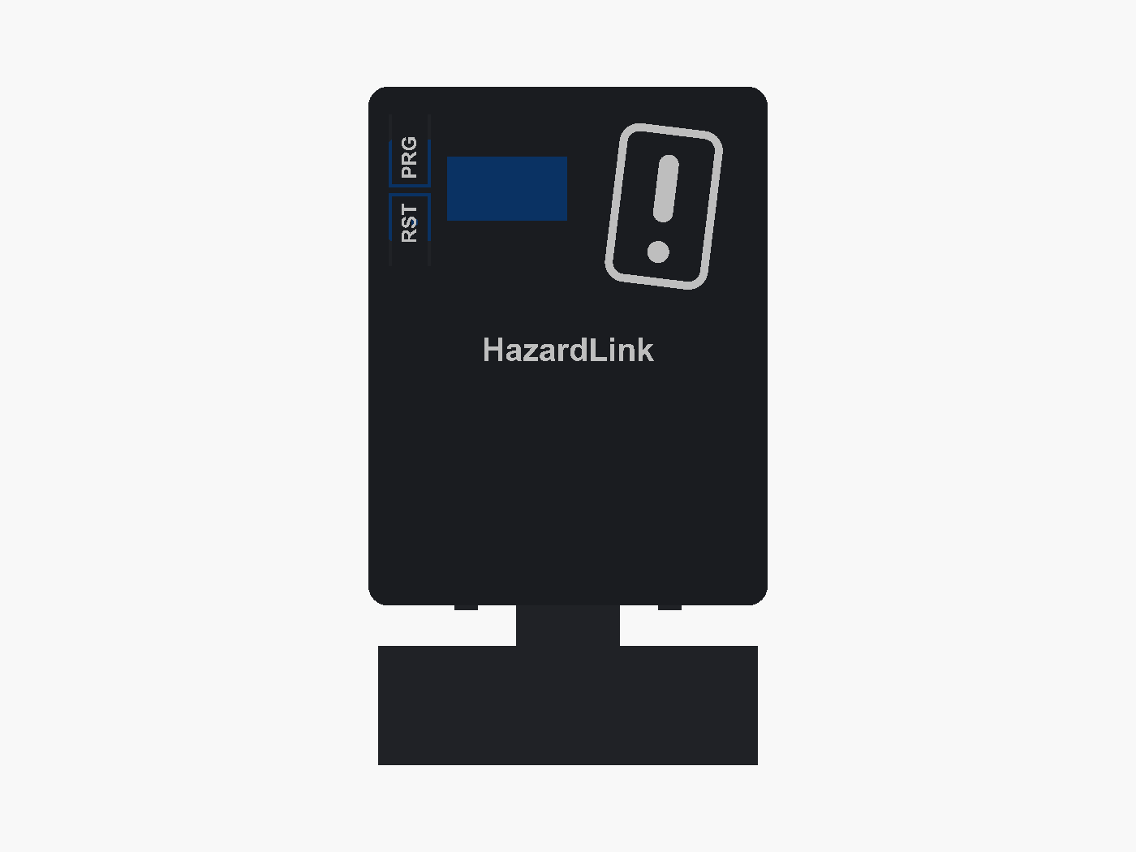
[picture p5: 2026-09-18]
hardware/enclosures/v9/closeups/finished_face_on.png

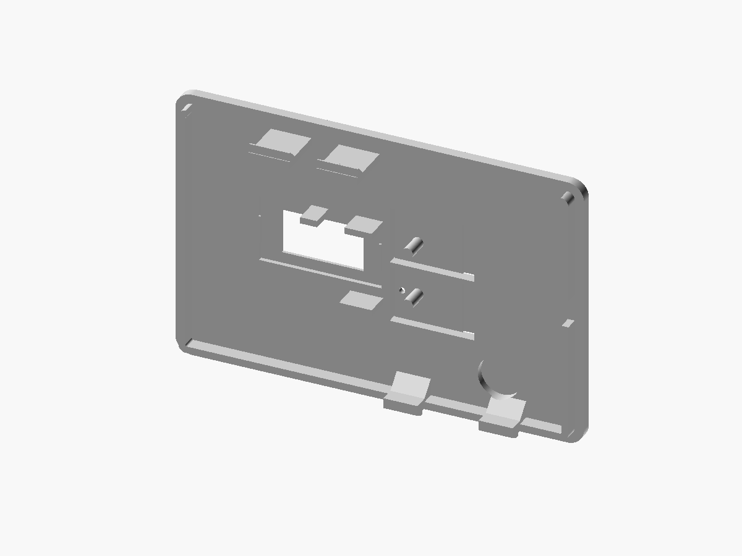
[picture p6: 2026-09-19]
hardware/enclosures/v9/gateway_lid_inside.png

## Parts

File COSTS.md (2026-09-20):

# HazardLink: full project cost breakdown

Updated 2026-09-19 (the Phase 1 parts were checked against what was actually bought, and the enclosure notes match design v9.10; every price in this file is still the estimate from 2026-05-21)

All figures EUR unless marked otherwise. Quantity-pricing estimates assume
EU/Ireland sourcing for assembly + Chinese sourcing for raw components.

---

## Phase 1: Prototype (May estimate, ~€350)

What you spend before you have anything sellable. One full set of hardware
end-to-end so you can demo + validate firmware.

The Item, Source and Cost columns are the May estimate, and the total is the sum of that Cost column. The last column
says what was bought in the end. Prices actually paid are on the order confirmations and are not copied here, so treat
~€350 as the plan and read the real spend off the confirmations. `SHOPPING.md` has the full list of what was bought.

| Item in the May estimate | Source | Cost | What was actually bought |
|---|---|---|---|
| Heltec WiFi LoRa 32 V3 × 3 (2 hangers + 1 gateway) | TinyTronics | €90 | 6 boards delivered |
| Samsung INR21700-50E 5000mAh × 2 | TinyTronics | €24 | Superseded. The hanger takes an 18650: 4 x Murata US18650VTC6 delivered |
| 21700 battery holders × 2 | TinyTronics | €4 | Superseded. 4 x BeiLaMoo BH18650-PC2 holders (18650, solder pins) delivered |
| JST 1.25mm cable pack (Heltec polarity) | Rokland | €7 | Not recorded as bought yet. One cable per hanger joins the battery holder to the board |
| DRV5032FA Hall sensor (×5) | Mouser IE | €5 | 25 x TI DRV5032FALPG from DigiKey. Same DRV5032FA sensor, in the bare flat 3-leg package the hook bar is cut for (the SOT-23 version does not fit) |
| Neodymium magnets 6×3mm (×10) | TinyTronics | €3 | 14 x XMP 6 x 2 mm N52 delivered |
| 868MHz 5dBi SMA antenna + IPEX→SMA pigtail | Amazon UK | €17 | |
| Qorvo DWM3001CDK dev kits × 2 (UWB) | Mouser IE | €160 | Not part of the v1 hanger build, which finds a sign over BLE with the Heltec board's own radio. The kits were bought separately on a DigiKey order, see `docs/UWB_PLAN.md` for where that work stands |
| CR2032 cells + holders (×5) | TinyTronics | €10 | `SHOPPING.md` later swapped these for LiPo cells. 4 x PKCELL LiPo 350 mAh were delivered |
| Plastic enclosure prototypes (3D-printed PETG) | DIY | €10 | Test parts are printed in PLA: black (Polymaker PolyLite) for the box, white for the hook bar and the lettering on the lids. PET-G is for units that go on a wall |
| Shipping to Ireland | | ~€20 | |
| **Total prototype (May estimate)** | | **~€350** | |

Bought since, outside the May estimate: 6 x Gebildet 16 mm momentary push buttons (LED, waterproof) from Amazon UK. Since
enclosure v9.9 this is the cleaning-mode button. One is fitted under the base of each hanger, through a 16.4 mm hole in the
bottom wall of the hanger body, pointing down above the hook bar and out of sight from the front. Two are used for the two
prototype hangers and four are spare. Price on the order confirmation. The firmware reserves GPIO3 for this button
(`TEST_BUTTON_PIN = 3` in `firmware/include/pinout.h`) but does not act on a press yet, so that firmware work is still to
be done and is not costed here.

The button is long. Gebildet's own listing drawing gives 46 mm overall with its plug-in wire socket on, which is 44.5 mm
behind the head. So the hanger box grew downward by 44 mm to make room for it under the battery: in v9.10 the hanger body
is 174 mm tall (it was 130 before the button was added). The taller body, lid and backplate use more filament than the
€10 printing line above allowed for, and the design now prints in two colours. That line has not been re-estimated. The
button's LED is a 12 to 24 V type per the listing, so it will not light from the board's 3.3 V and only the two switch
wires are used. No LED driver or extra supply is costed.

The enclosure sizes come from the makers' own drawings, 3D models and listings. `hardware/enclosures/v9/PRINT.md` lists
them under "Where the sizes come from". Nothing has to be measured.

Still to buy, with no price recorded: thin hook-up wire for the sensor lead and the board's tails, one 0.1 uF capacitor
per Hall sensor (TI's datasheet recommends it), thin heat shrink, one small cable tie per hanger, a clear 36 x 19.5 x 1 mm
pane for the gateway lid, and the wall screws and plugs. The white 2.85 mm PLA is already on the printer and its price is
not recorded here either. It is Owen's colour choice: the hook bar and the lettering on the lids print in white from
nozzle 1, and everything else prints in black from nozzle 2. One more thing is optional: small wire-to-wire plug and socket pairs (a 3-way pair for the sensor lead and a 2-way pair
for the two button wires, per hanger), which only keep the board removable, with soldered and sleeved joins as the
fallback. `SHOPPING.md` lists all of them under "Things the build needs that are not on any order below". None of these
is in the ~€350.

---

## Phase 2: Pilot (5 sites, ~€3,500)

5 friendly customer installs. No money changing hands yet. This phase validates
the product in real environments.

### Per-unit BOM at qty 100

| Item | Per hanger | Per sign tag | Per gateway |
|---|---|---|---|
| Board | €18 | €12 | €25 |
| Battery + holder | €8 | €1 | none |
| Sensor + magnet | €1 | €0.50 | none |
| Antenna | €2 | none | €15 |
| Power supply | none | none | €5 |
| Enclosure (3D printed) | €4 | €2 | €4 |
| Switches/LEDs/etc | €2 | none | none |
| **Per unit** | **€35** | **€15** | **€49** |

The per-hanger column was estimated in May, before the cleaning-mode button was added and before the hanger box grew to
174 mm tall. The button's price is on the Amazon order confirmation and has not been worked into the €35.

### Pilot total (5 sites × 10 hangers + 10 tags + 1 gateway each)

| | Per site | × 5 |
|---|---|---|
| Hangers | €350 | €1,750 |
| Sign tags | €150 | €750 |
| Gateway | €49 | €245 |
| Charging dock (Anker + cradle) | €60 | €300 |
| Install travel + spares | €100 | €500 |
| **Total pilot** | **€709** | **~€3,545** |

---

## Phase 3: Production NRE (~€27,500 one-time)

Engineering investment before mass production. Pays for itself across
first batch of ~500 units.

| Item | Cost |
|---|---|
| Custom hanger PCB design (contract engineer) | €4,000 |
| Custom UWB tag PCB design | €4,000 |
| Hanger enclosure injection mould tooling | €8,000 |
| Sign tag enclosure injection mould tooling | €3,000 |
| Industrial design (CAD both enclosures) | €2,000 |
| Factory QC rig (jig + flashing station) | €1,500 |
| FCC + CE certifications (RF compliance) | €5,000 |
| **Total NRE** | **~€27,500** |

---

## Phase 4: Production batch (500 hangers, ~€25,000)

First mass-produced batch. Real per-unit economics.

### Per-unit BOM at qty 1000

| Item | Per hanger | Per sign tag |
|---|---|---|
| Custom PCB | €12 | €8 |
| Battery | €6 | €0.30 |
| Sensor + magnet | €0.80 | €0.40 |
| Antenna | €1.50 | none |
| Enclosure (injection moulded ABS) | €3.50 | €1.20 |
| Misc components | €1.20 | none |
| Assembly + test | €4 | €1 |
| **Per unit** | **€29** | **€11** |

### First production batch

| Item | Qty | Cost |
|---|---|---|
| Hangers @ €29 | 500 | €14,500 |
| Sign tags @ €11 | 500 | €5,500 |
| Gateways @ €25 (at scale) | 50 | €1,250 |
| Labels + packaging | 500 | €750 |
| Logistics + warehousing | | €3,000 |
| **Total first batch** | | **~€25,000** |

---

## Recurring software + cloud (~€50/mo)

| Service | Cost |
|---|---|
| Render web service (Starter, always-on) | €7/mo |
| Render Postgres (Basic 256MB) | €7/mo |
| Domain (.ie / .com) | €1/mo |
| Sentry error monitoring (Team) | €26/mo |
| Apple Developer Program (€99/yr) | €8/mo |
| Firebase FCM | €0 |
| APNs | €0 |
| GitHub (private repos free) | €0 |
| **Subtotal** | **~€50/mo** |

Google Play Developer: $25 one-off.

At 10k+ hangers, add ~€50/mo for Postgres Pro + read replicas.

---

## Legal + business one-offs (~€4-8k)

| Item | Cost | Timing |
|---|---|---|
| Terms of Service + Privacy Policy | €500-1,500 | Before first customer |
| Public liability insurance | €500-1,500/yr | Before first customer |
| Product liability insurance | €1,000-3,000/yr | Before production |
| Patent provisional (UK+IE via FRKelly) | €2,000-5,000 | BEFORE public demos |
| Patent full filing (year 2) | €8,000-15,000 | 12 months after provisional |
| Trademark "HazardLink" (UK+IE) | €500-1,000 | Before launch |
| Company incorporation | €50-300 | Before invoicing |
| Accountant | €600-1,500/yr | Year 1+ |
| **Pre-launch legal** | **~€4-8k** | |

---

## Launch + marketing (~€2-5k)

| Item | Cost |
|---|---|
| Marketing website (template + hosting) | €500-1,500 |
| App Store + Play Store assets | €500-1,000 |
| Logo + brand identity | €200-500 |
| Hanger labels (printed stickers) | €100-200 |
| Demo video for sales (or DIY) | €500-1,500 |
| **Subtotal** | **~€2-5k** |

---

## Grand total to ship at scale

| Phase | Investment |
|---|---|
| Prototype | ~€350 |
| Legal + patent (pre-demo) | €4,000-8,000 |
| Pilot phase (5 sites) | ~€3,500 |
| Marketing + launch | €2,000-5,000 |
| Production NRE | ~€27,500 |
| First production batch (500 units) | ~€25,000 |
| **TOTAL** | **~€63,000-70,000** |

Plus recurring ~€50/mo for cloud + Apple/Google fees.

---

## Unit economics for sales pricing

What you charge customers:

| Site size | BOM (your cost) | Install price | Recurring SaaS | Hardware margin |
|---|---|---|---|---|
| Small (10 hangers, 10 tags, 1 gw) | €510 | €1,500 | €30/mo | 66% |
| Medium (50 hangers, 50 tags, 2 gw) | €2,400 | €6,500 | €100/mo | 63% |
| Large (200 hangers, 200 tags, 5 gw) | €8,750 | €25,000 | €350/mo | 65% |

**Break-even**: ~15-20 medium customers OR 5-8 large ones recovers the
€63k investment. Realistic in year 1-2 with even modest sales effort.

---

## Cheapest viable path

If cash is tight, you can ship without UWB precision finding and skip
the €4k custom UWB PCB + €3k UWB enclosure tooling = **~€56k total**.
UWB becomes a premium v2 feature once base product is proven.

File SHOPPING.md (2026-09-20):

# HazardLink prototype shopping list

Updated 2026-09-19

The bought parts for 2 hangers + 1 gateway, followed by a short list of small things the build still needs that are on no order.

The order tables further down are the May plan with its estimated prices, about €198 in total once the UWB kits and their LiPo cells were taken out. Several parts changed between that plan and what was bought, so read "What has been bought" first. The prices actually paid are on the order confirmations and are not copied here.

> **Update:** UWB tags (Qorvo DWM3001CDK) are not part of the v1 hanger
> build, which does "Find Sign" over BLE proximity with the Heltec
> board's own radio. The DWM3001CDK kits were bought separately on a
> DigiKey order; see `docs/UWB_PLAN.md` for where that work stands.

---

## What has been bought

The enclosures in `hardware/enclosures/v9` (design v9.10) are sized for these parts. Nothing in that design is 21700. The sizes come from the makers' own drawings, 3D models and listings, and `hardware/enclosures/v9/PRINT.md` lists which document gave which number under "Where the sizes come from". Nothing on this list has to be measured or photographed.

| Part | Qty | Supplier | Notes |
|---|---|---|---|
| Heltec WiFi LoRa 32 V3, 868 MHz | 6 | TinyTronics, order 660112 | Delivered (packing slip photographed 2026-09-18). A new board runs the maker's demo. It has to be flashed with the HazardLink firmware from the repository's `firmware` folder before the unit can report anything, see "Firmware on a new board" below |
| Murata US18650VTC6 cell (18650) | 4 | TinyTronics, order 660112 | Delivered. One per hanger |
| BeiLaMoo BH18650-PC2 holder, sold as "1x 18650 Battery holder for PCB" | 4 | TinyTronics, order 660112 | Delivered. 77.7 x 20.9 x 21.3 mm, one solder pin at each end. It is a copy of the MPD BH-18650-PC, and MPD's drawing gives the pins: 3.30 mm long, 2.40 mm in from each end. One per hanger. Its pins end up behind it, so the battery wires are soldered on BEFORE it is pressed into the box. Thread the two wires down through the bulkhead first, see Order #3 |
| XMP neodymium disc magnet, 6 x 2 mm, N52 | 14 | TinyTronics, order 660112 | Delivered. One goes in each sign, over the Hall sensor (the small magnetic sensor in the hook bar that tells the unit the sign has been lifted) |
| PKCELL LiPo 350 mAh, LP552035 | 4 | TinyTronics, order 660112 | Delivered. Nothing in the v9 hanger or gateway enclosure is sized for this cell |
| TI DRV5032FALPG Hall sensor | 25 | DigiKey | Bought. This is the DRV5032FA in the bare flat 3-leg package (TO-92 style, body about 4.1 x 3.0 x 1.5 mm), which is the part the v9 hook bar is cut for. It is soldered straight to its three wires with no carrier board. It is omnipolar, so either pole of the magnet works. Owen's sensors are marked 32FA. Which leg is which is confirmed, see Order #2 |
| Gebildet 16 mm momentary push button with LED, waterproof | 6 | Amazon UK | Bought, and now used. Since enclosure v9.9 this is the cleaning-mode button, one per hanger, so two are used here and four are spare. See "The cleaning-mode button" just below |

### The cleaning-mode button

The button goes UNDER the base of the hanger, through a 16.4 mm hole in the bottom wall of the hanger body, on the right-hand side behind the right latch arm. It points down, above the hook, where the public cannot see it from the front. A cleaner reaches under the box from the right-hand side and presses it upward. There is about 42.8 mm between the button's face and the hook for a finger.

What the part is, from Gebildet's own listing drawing: an M16 x 1 thread for a 16 mm hole, a head 18.8 mm across, and 46 mm overall with the blue plug-in wire socket pushed on. Five wires leave the end of the socket. The enclosure allows 44.5 mm behind the head, which is the 46 mm less the 1.6 mm head, and 3.2 mm under the base for the head on its sealing ring. It comes with its own nut.

To make room for that length under the battery, the hanger box grew downward by 44 mm: the bay under the battery is 44 mm and the hanger body is 174 mm tall in v9.10 (it was 130 before the button was added). The gateway keeps its size.

Fitting, in short: push the bare button up through the hole from below, put its nut on from inside and tighten it, then plug the blue socket onto the button's pins from inside. The socket will not pass through the hole, so it always goes on last. The full steps and the wire route are in the v9 README.

The five wires. Only TWO of them are used: the two switch wires. Find them on the bench with a meter set to continuity (the beep setting), by trying the wires in pairs until one pair beeps only while the button is held in. Gebildet's listing picture shows green as the common wire and yellow as the normally open one, with white as the normally closed one and red and black for the LED. That picture is a stock one shared between listings, so go by the meter. Those two go up to the board, one to GND and one to GPIO3, either way round. The other three are folded back, their bare ends covered with heat shrink or tape, and tucked down in the bay under the battery, connected to nothing. Deal with all five BEFORE the battery holder is pressed in: they leave the top of the socket pointing up at the place where the holder goes. Check that the two switch wires reach the join below the board, and lengthen them with hook-up wire if they do not.

The button's LED is a 12 to 24 V type per Gebildet's listing, so it will not light from the board's 3.3 V. Its wires stay unconnected. Only the two switch wires are used.

Firmware status: `firmware/include/pinout.h` reserves `TEST_BUTTON_PIN = 3` (GPIO3) as the cleaning-mode trigger, and `firmware/src/hanger/hanger.cpp` sets that pin up as an input with a pull-up. The hanger's main loop does not act on a press yet, so the firmware support for the button is still to be written. Until it is, pressing the button changes nothing on the unit. The check for the wiring is a meter on continuity across the two switch wires where they come up through the bulkhead (the thick shelf across the inside of the box above the battery): it must beep only while the button under the box is pressed.

### Firmware on a new board

A Heltec board comes from the maker running the maker's own demo. Before a hanger or a gateway can report anything, its board has to be flashed with the HazardLink firmware from the repository's `firmware` folder, which is a PlatformIO project (`firmware/platformio.ini`) with a build for the hanger and one for the gateway. The flashing steps are in `firmware/README.md` under "Build + flash", and `firmware/flash.sh` is the helper script that goes with them. The commands are kept in those two files and are not copied here.

### Things the build needs that are not on any order below

Check each of these is in hand before starting, because none of them is on an order. The one marked Optional can be left out:

- Thin hook-up wire (thin, flexible, insulated wire) in three colours for the three sensor leads, which run from the hook bar up to the board. The same wire makes the short tails on the board, and it lengthens the cleaning-mode button's two switch wires if they turn out too short to reach the join below the board.
- One 0.1 uF capacitor per Hall sensor. TI's datasheet recommends one between the sensor's supply and its ground. It is a tiny electronic part that steadies the supply.
- One clear window pane, 36 x 19.5 x 1 mm (acrylic or PETG), for the gateway lid. The hanger lid takes no pane: its display sits behind a printed bezel.
- Wall fixings: 4 No.8 countersunk screws with wall plugs for each hanger backplate, and 2 No.8 pan head screws plus 1 more for the lower hole for the gateway.
- Thin heat shrink (plastic sleeve that shrinks tight when warmed) for the three solder joints on the sensor's legs, for every wire-to-wire join below the board, and for the bare ends of the button's three unused wires.
- One small cable tie per hanger, to tie the wire bundle to the saddle on the back wall of the box.
- Optional: small wire-to-wire plug and socket pairs (JST-PH or similar, a family of small connectors), a 3-way pair for the sensor lead and a 2-way pair for the two button wires, per hanger. They are on no order. All they do is keep the board removable without a soldering iron. Without them the joins below the board are soldered and sleeved with heat shrink, and the build works just the same (see the v9 README, HANGER).
- White 2.85 mm PLA. Owen's colour choice is a black box with the hook bar, the logo and the button names in white. The white spool is on the printer's nozzle 1 and the black PLA is on nozzle 2. The whole hook bar prints in white, and the lettering is a white inlay merged with the black lid (see Colours in `hardware/enclosures/v9/PRINT.md`). The white spool is on no order in this file.

Two more things each hanger needs, with nothing to buy:

- The sensor's two retaining pins are offcuts of the 2.85 mm printer filament, cut 6.0 to 6.5 mm long, never longer.
- An SMA bulkhead pigtail and a stubby SMA antenna (about 9.5 mm diameter and 47 mm long) go inside each hanger. The pigtail is the thin antenna cable with a tiny press-on plug (called U.FL or IPEX) at one end for the board and a threaded SMA jack at the other for the antenna. In the name of this part, "bulkhead" only means the jack is made to be clamped through a slot or hole with its own nut and washer. It has nothing to do with the bulkhead shelf inside the hanger box. Owen has these in hand and the enclosure is already sized for them, so nothing more is needed from him there. The supplier and quantity are not recorded here, so check there is one set per hanger.

---

## Order #1: TinyTronics (Netherlands), delivered as order 660112

Best value for batteries + boards. Ships to Ireland in 3-5 days.

This table is the May plan. The last column says what came instead.

| Item in the May plan | Qty | Link | Estimated price | What was delivered |
|---|---|---|---|---|
| Heltec WiFi LoRa 32 V3 (868 MHz) | 3 | https://www.tinytronics.nl/en/development-boards/microcontroller-boards/with-lora/heltec-wifi-lora-32-esp32-s3-sx1262-with-0.96-inch-oled-display | €90 | 6 boards |
| Samsung INR21700-50E 5000mAh | 2 | do not order | €24 | Superseded. The v9 hanger takes an 18650: 4 x Murata US18650VTC6 were delivered |
| 21700 battery holder | 2 | do not order | €4 | Superseded. 4 x BeiLaMoo BH18650-PC2 holders (18650, solder pins) were delivered |
| Neodymium magnets 6 x 3 mm | 1 pack (10) | https://www.tinytronics.nl/en/mechanics-and-actuators/magnets | €3 | 14 x XMP 6 x 2 mm N52. The magnet datum in the v9 design is for the 6 x 2 mm disc |
| LiPo 500mAh with JST PH 2.0 (for UWB tags, rechargeable via USB-C on DWM3001CDK) | 3 | https://www.tinytronics.nl/en/power/batteries/lipo/lipo-battery-3.7v-500mah-jst-ph-connector | €21 | 4 x PKCELL LiPo 350 mAh LP552035 |
| Shipping to Ireland | | | €10 | |
| **Subtotal (May estimate)** | | | **€152** | |

## Order #2: DigiKey, bought

Hall sensors for the lift detection.

| Item | Qty | Link | Price |
|---|---|---|---|
| TI DRV5032FALPG Hall sensor (DRV5032FA, bare 3-leg TO-92 style package) | 25 | https://www.digikey.ie/en/products/result?keywords=DRV5032FALPG | on the order confirmation |

Order the part number ending in LPG. The DRV5032FADBZR that the May plan listed is the same sensor in the SOT-23 surface-mount package. It is far smaller than the nest in the v9 hook bar and would slip between the two retaining pins, so it cannot be used in these bars.

Which leg is which is confirmed. Owen's sensors are marked 32FA, and TI's datasheet SLVSDC7H lists 32FA as the part marking of the DRV5032FALPG. Figure 7-1 of that datasheet shows that the "top" of this package is its marked, bevelled front face. Figure 5-5 (the top view) together with Table 5-1 gives pin 1 = VCC (the supply, 1.65 to 5.5 V), pin 2 = GND and pin 3 = OUT (the output).

So hold the sensor with its MARKED face (32FA) toward you and its legs pointing DOWN:

- the LEFT leg is VCC, and goes to 3V3 on the board
- the MIDDLE leg is GND
- the RIGHT leg is OUT, and goes to GPIO6 on the board

Wire every sensor to that order. Do not try to find the legs by touching 3V3 to a bare sensor: 3V3 on the OUT leg is something TI's absolute maximum ratings do not allow. The safe check comes after the three wires are soldered on in the confirmed order. Power the sensor from the board and watch OUT with a meter while the magnet is brought near: OUT goes LOW with the magnet present and HIGH without it.

In May this slot was a Mouser Ireland order estimated at €175: 2 x Qorvo DWM3001CDK UWB dev kits (€160, not part of the v1 hanger build, see the update at the top), 1 pack of 5 x TI DRV5032FADBZR (€5) and €10 shipping.

## Order #3: Rokland (US), about €22

Battery leads: 2-pin JST 1.25 cables wired with Heltec polarity. One is used per hanger. Each cable is one small plug with two loose wire ends. The loose ends are soldered to the two pins of the battery holder, and the plug goes into the battery socket on the underside of the board. Don't substitute another make of cable, because the wrong polarity destroys the board.

The wires have to be threaded BEFORE they are soldered. Inside the hanger box the battery sits below the bulkhead (the thick shelf across the inside of the box) and the board sits above it. The bulkhead has a notch at each end for the battery wires, one wire through each. Each notch is a closed hole, because 12 mm of bulkhead closes its front, so a wire cannot be laid into it from the front. The two wires also share one plug, and that one plug cannot follow them down two notches at opposite ends of the box. So the order that works, with no cutting and no joins, is this:

1. Find the cable's + wire. With the USB cable unplugged and nothing touching the cable's loose ends, push its plug into the battery socket on the underside of the board. See which wire lines up with the + printed on the board beside the socket, mark that wire with tape, and pull the plug out again. Find the holder's + end from the + and - marks moulded into it.
2. BEFORE the holder goes in, feed the cable's two LOOSE ends DOWN through the bulkhead from the board side, one through each end notch, and leave the plug above the bulkhead. The taped wire goes down the notch at the end of the box where the holder's + end will sit.
3. With the holder still out of the box and resting in front of it, solder the taped wire to the SIDE of the pin at the holder's + end and the other wire to the SIDE of the other pin, with nothing standing beyond the pin tips. Then do the polarity check below.
4. Press the holder straight in until both of its arms click, drawing the slack in the two wires back up through the notches as it goes.

The polarity check: even with the right cable, check every lead with a meter before its plug ever goes into a board with a cell fitted. Do it at step 3, with the holder resting in front of the box. Put the cell in the holder, its + end at the holder's + mark. Set the meter to DC volts, and put the red probe on the pin that carries the taped wire and the black probe on the other pin. The reading must be positive, with no minus sign. A minus sign means the wires are the wrong way round: take the cell out, unsolder the two wires, swap them over (pull each one back up and feed it down the other notch) and check with the meter again. Take the cell out again before the holder is pressed in, because the cell is the last part to go into the box. Go by the meter and the printed markings, never by the colour of the wires. The v9 README has the full steps.

US shipping to Ireland: 1-2 weeks. This is the slowest order, so if it is still open, place it before anything else.

| Item | Qty | Link | Price |
|---|---|---|---|
| JST 1.25mm 2-pin cable (Heltec polarity, 5-pack) | 1 | https://store.rokland.com/products/battery-connector-cables-battery-wires-jst-1-25-5pcs-for-lilygo-and-heltec | €7 |
| Shipping | | | €15 |
| **Subtotal** | | | **€22** |

## Order #4: Amazon UK, about €30 plus the buttons

Gateway antenna upgrade. Free delivery to Ireland, 1-3 days.

| Item | Qty | Link | Price |
|---|---|---|---|
| 868MHz 5dBi SMA antenna | 1 | https://www.amazon.co.uk/s?k=868mhz+5dbi+antenna+sma | €12 |
| IPEX (U.FL) to SMA pigtail | 1 | https://www.amazon.co.uk/s?k=ipex+ufl+to+sma+pigtail+cable+15cm | €8 |
| USB-C 5V power supply (gateway) | 1 | https://www.amazon.co.uk/s?k=anker+usb-c+charger+20w | €10 |
| **Subtotal** | | | **€30** |

Bought separately on Amazon UK, outside the May estimate:

| Item | Qty | Link | Price |
|---|---|---|---|
| Gebildet 16 mm momentary push button with LED, waterproof (the cleaning-mode button, fitted under the hanger's base since enclosure v9.9) | 6 | https://www.amazon.co.uk/s?k=gebildet+16mm+momentary+push+button+led+waterproof | on the order confirmation |

---

## Timing strategy

Orders 1 and 2 are done: Order 1 (TinyTronics) has been delivered, and the Hall sensors (Order 2, DigiKey) and the push buttons have been bought.

If Order 3 (Rokland) is still open, place it first. It ships from the US and is the slowest, see the delivery time under Order #3. Order 4 (Amazon UK) is the quickest and can go last.

While waiting, gather the small things listed under "Things the build needs that are not on any order below".

---

## What you'll build

After all 4 orders arrive:

- 2 × prototype hangers (Heltec + 18650 cell in its holder + Hall sensor + magnet + cleaning-mode button under the base, which the firmware does not act on yet)
- 1 × gateway (Heltec + antenna + USB-C plug)
- Spare sensors, magnets and buttons for future hangers (25 sensors, 14 magnets and 6 buttons were bought)

The orders do not cover everything. The hook-up wire, the capacitors, the heat shrink, the cable ties, the gateway's window pane, the wall fixings and the white PLA are listed near the top under "Things the build needs that are not on any order below", along with the optional plug and socket pairs.

Enough to demo the full system end-to-end, once every board has been flashed (see "Firmware on a new board" near the top). UWB tag prototypes are not part of these
orders (see the update at the top). `docs/UWB_PLAN.md` lists DWM3001CDK dev kits on a separate
DigiKey order, so check that document for where the UWB work stands.

---

## Optional later (not needed for prototype)

- 3D-printed enclosures: JLCPCB (~€8/enclosure)
  https://jlcpcb.com/3d-printing-service
- Anker 6-port USB-C charger (for charging dock): ~€40 on Amazon
- Spare Heltec boards (€18 each from Heltec AliExpress at qty 10+)
- Tile/Chipolo-style off-shelf BLE tags (skip, going custom with DWM3001)

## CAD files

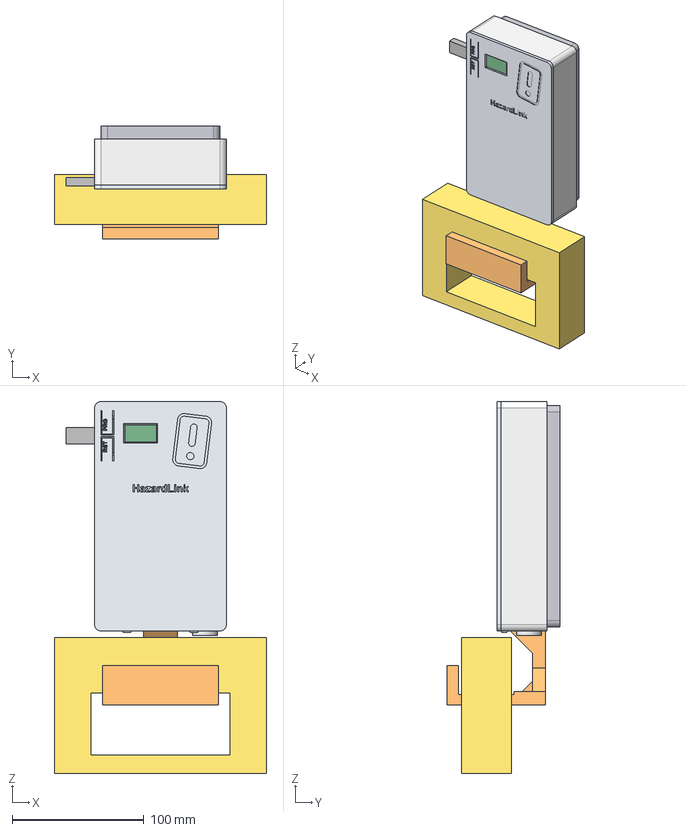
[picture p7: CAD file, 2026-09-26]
hardware/enclosures/v9/hanger_assembly.step
161.0 x 86.0 x 282.0 mm
hanger_body
hanger_lid
hanger_bar
hanger_backplate
ref_heltec
ref_holder
ref_cell
ref_clean_button
ref_hall_carrier
ref_hall_pin
ref_sign_handle
ref_magnet
ref_stub_antenna
ref_usb_plug

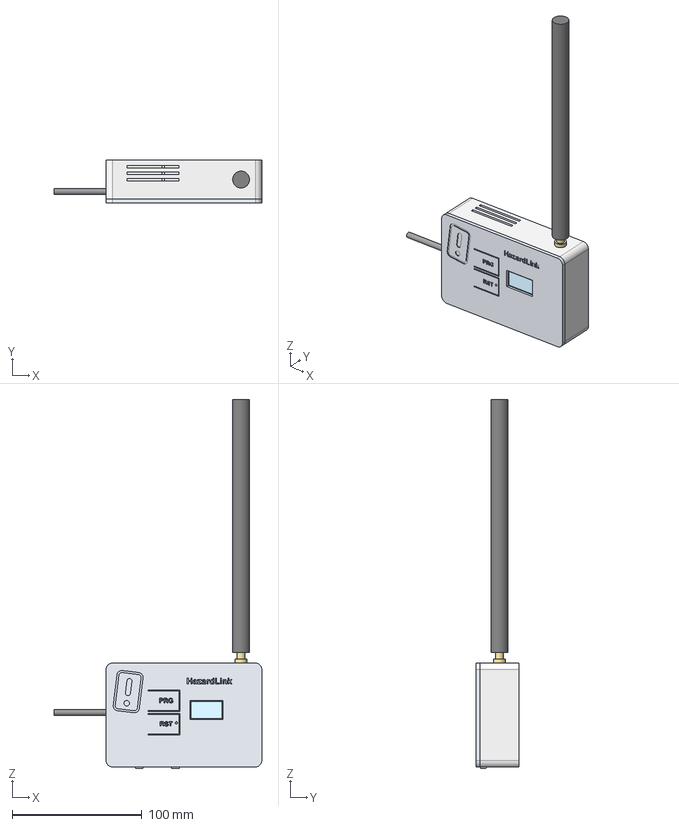
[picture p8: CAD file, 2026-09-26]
hardware/enclosures/v9/gateway_assembly.step
160.0 x 33.0 x 284.2 mm
gateway_body
gateway_lid
ref_heltec
ref_usb_plug
ref_usb_cable
ref_sma_jack
ref_whip_antenna
ref_window_insert

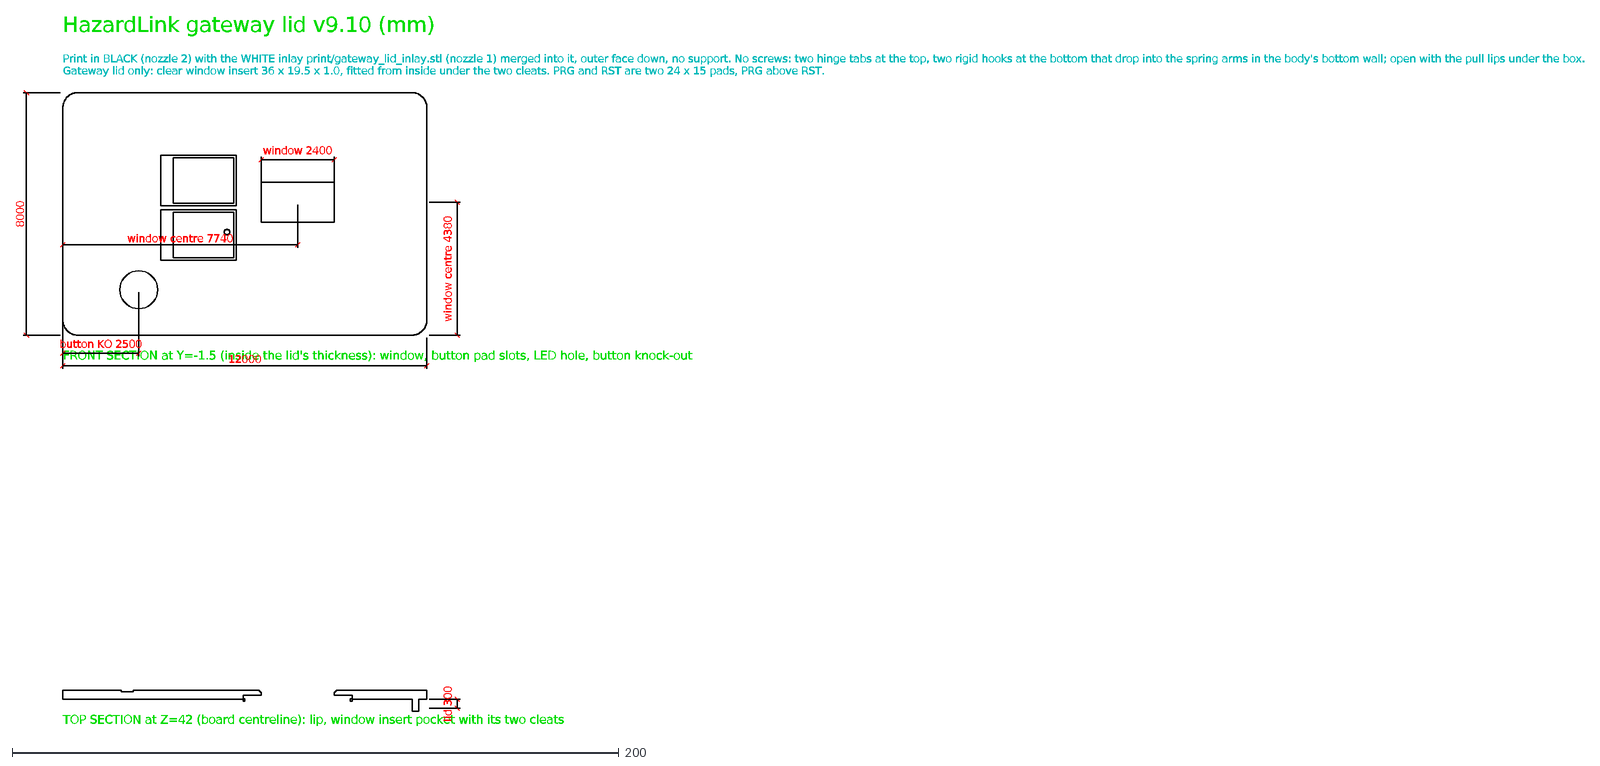
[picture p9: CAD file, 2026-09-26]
hardware/enclosures/v9/gateway_lid_drawing.dxf
HazardLink gateway lid v9.10 (mm)
FRONT SECTION at Y=-1.5 (inside the lid's thickness): window, button pad slots, LED hole, button knock-out
12000
8000
window 2400
window centre 7740
window centre 4380
button KO 2500
TOP SECTION at Z=42 (board centreline): lip, window insert pocket with its two cleats
lid 300
Print in BLACK (nozzle 2) with the WHITE inlay print/gateway_lid_inlay.stl (nozzle 1) merged into it, outer face down, no support. No screws: two hinge tabs at 
Gateway lid only: clear window insert 36 x 19.5 x 1.0, fitted from inside under the two cleats. PRG and RST are two 24 x 15 pads, PRG above RST.

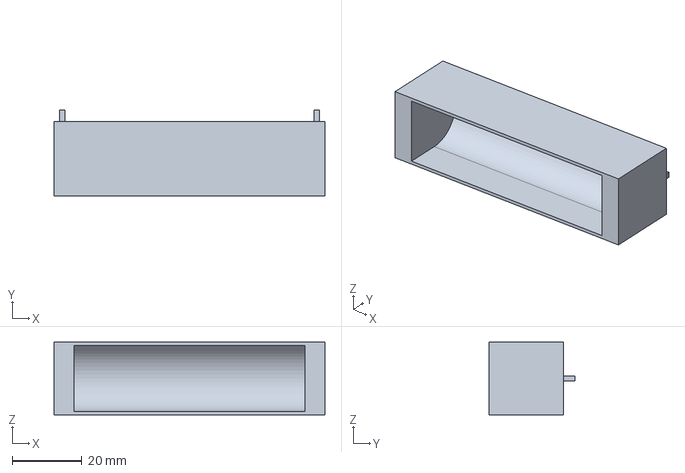
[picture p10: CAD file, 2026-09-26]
hardware/enclosures/v9/ref/hanger_holder.step
77.7 x 24.6 x 20.9 mm

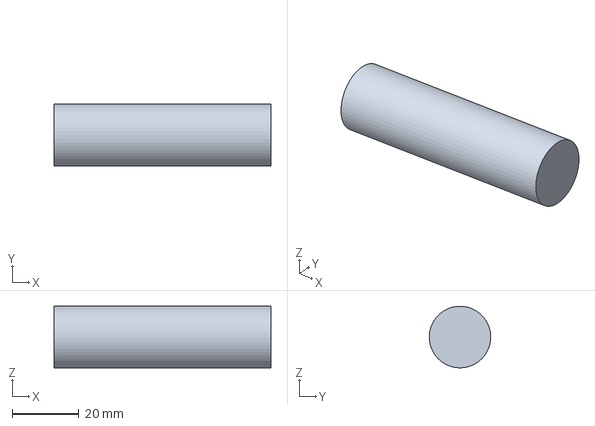
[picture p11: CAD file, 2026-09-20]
hardware/enclosures/v9/stages/S3_cell.step
65.2 x 18.5 x 18.5 mm

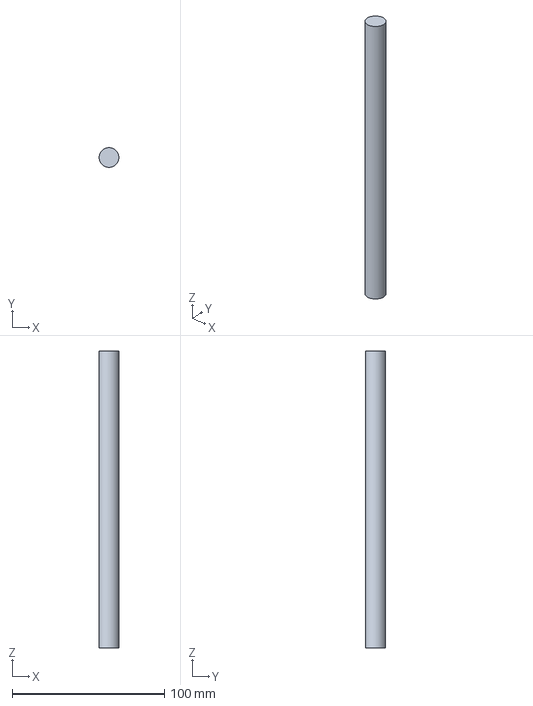
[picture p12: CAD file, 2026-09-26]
hardware/enclosures/v9/ref/gateway_whip_antenna.step
13.0 x 13.0 x 195.0 mm

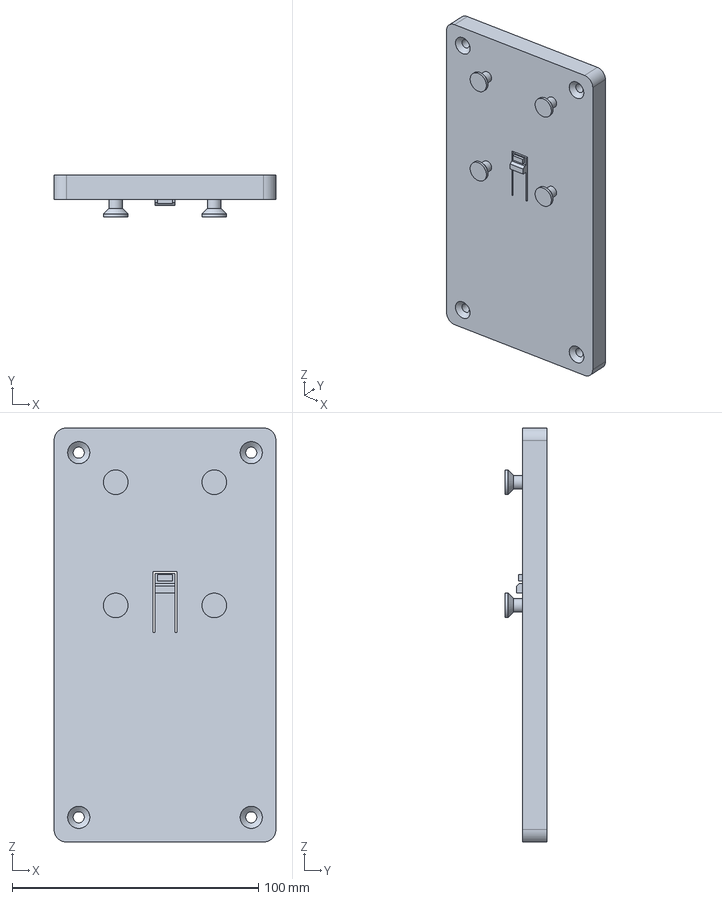
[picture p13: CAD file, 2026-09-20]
hardware/enclosures/v9/stages/S5_plate.step
90.0 x 17.0 x 168.0 mm

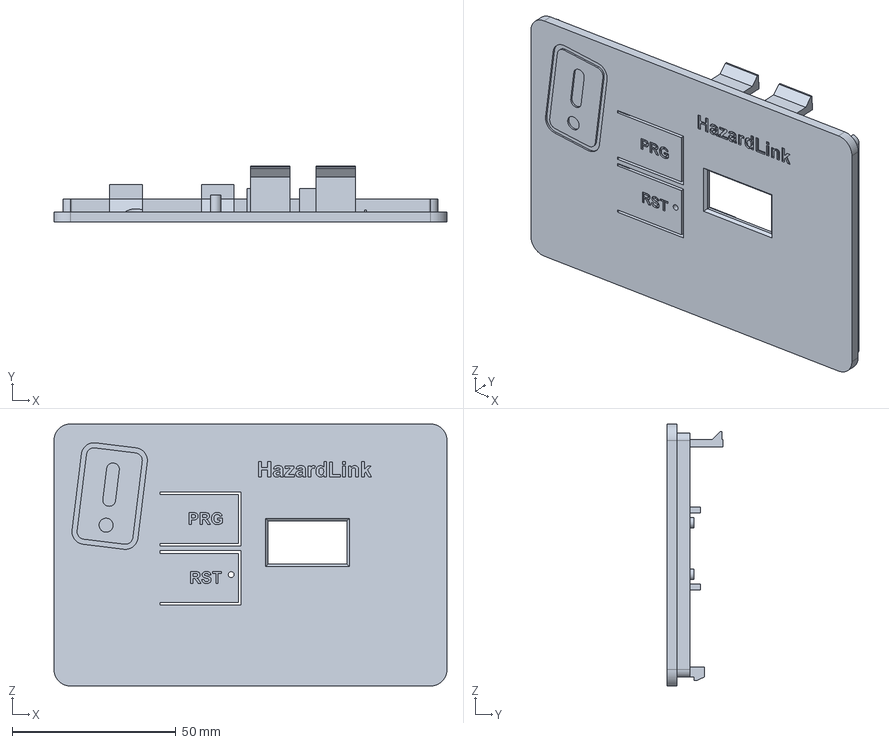
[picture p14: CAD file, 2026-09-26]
hardware/enclosures/v9/gateway_lid.step
120.0 x 17.0 x 80.0 mm

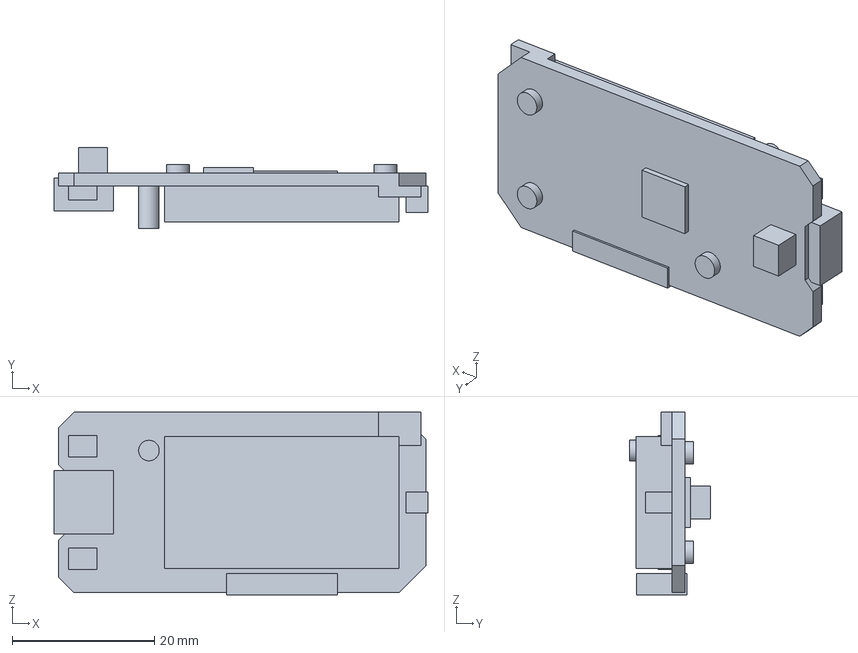
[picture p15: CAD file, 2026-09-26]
hardware/enclosures/v9/ref/hanger_heltec.step
52.6 x 11.4 x 25.7 mm

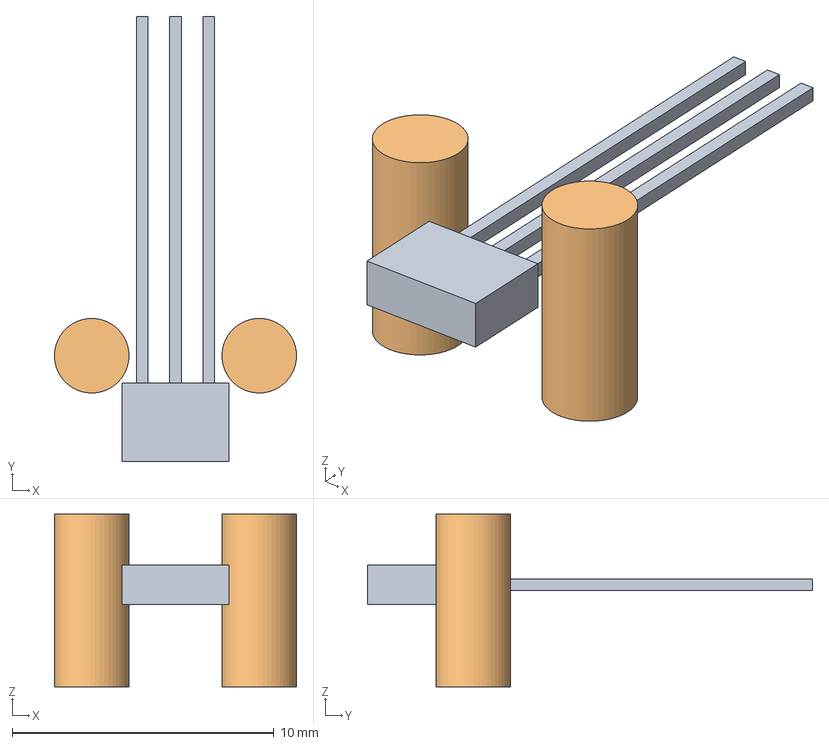
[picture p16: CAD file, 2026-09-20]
hardware/enclosures/v9/stages/S3_sensor.step
9.25 x 17.0 x 6.60 mm

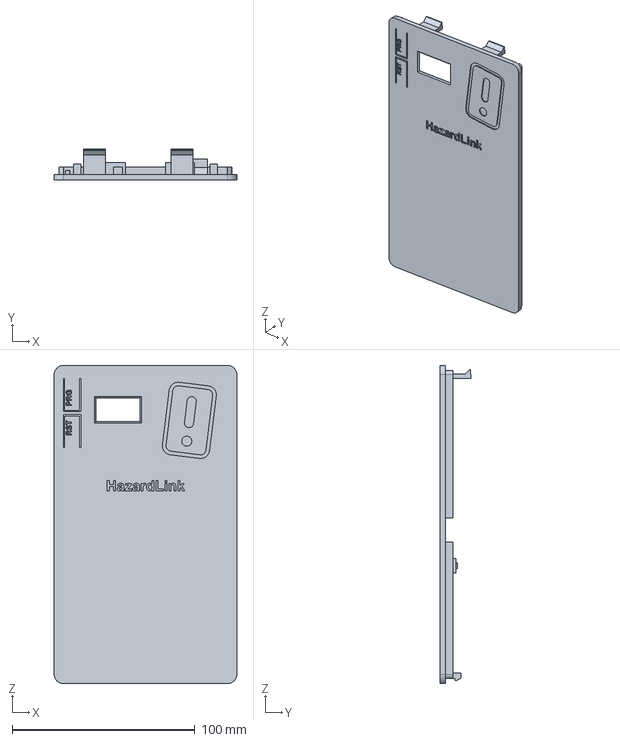
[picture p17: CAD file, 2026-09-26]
hardware/enclosures/v9/hanger_lid.step
100.0 x 17.0 x 174.0 mm

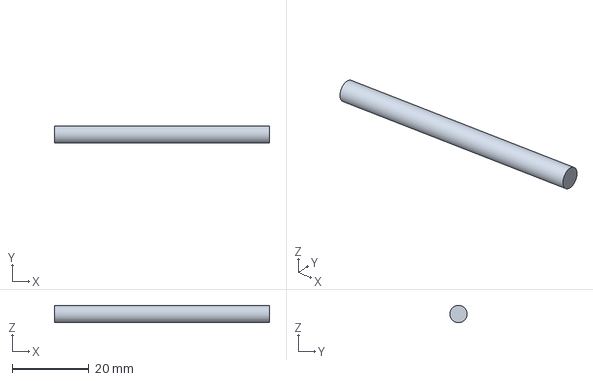
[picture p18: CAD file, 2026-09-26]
hardware/enclosures/v9/ref/gateway_usb_cable.step
55.9 x 4.50 x 4.50 mm

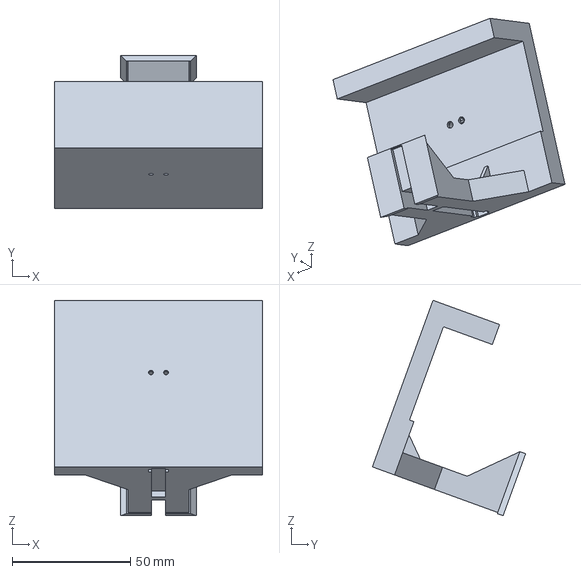
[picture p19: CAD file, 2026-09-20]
hardware/enclosures/v9/stages/S7_bar.step
88.0 x 64.9 x 91.1 mm

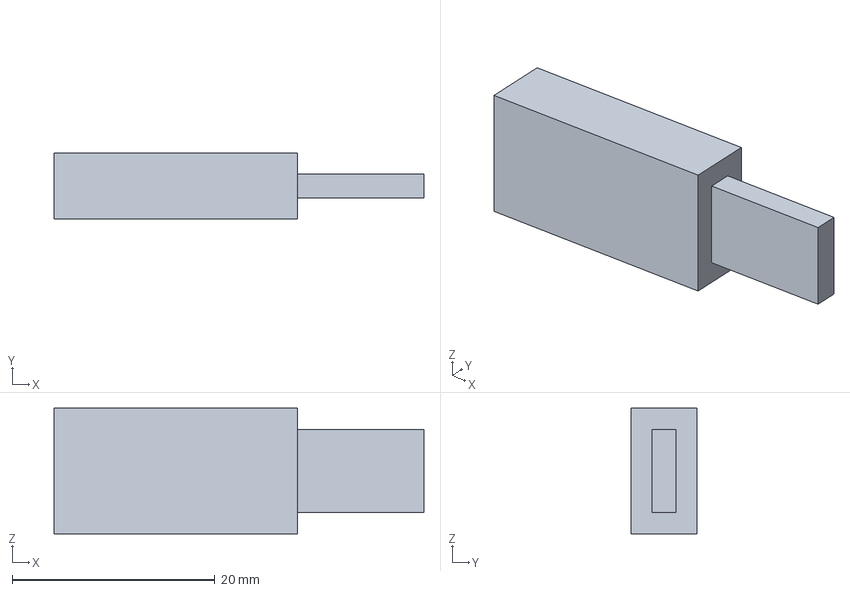
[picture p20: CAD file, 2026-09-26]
hardware/enclosures/v9/ref/gateway_usb_plug.step
36.5 x 6.50 x 12.4 mm

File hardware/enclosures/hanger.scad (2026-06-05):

// HazardLink — wall-mounted hanger enclosure (v7 — flush mount + grippy lid)
//
// CHANGES FROM v6:
//   1. Body sits FLUSH against backplate. Backplate is now thick enough
//      to contain the entire keyhole pocket — peg goes INTO the
//      backplate, not through it. Body's back face touches backplate's
//      front face with no gap.
//   2. Lid has a 3 mm raised lip around its perimeter that press-fits
//      into a matching recess in the body's front opening. Like a
//      Tupperware container. Plus 2 spring tabs at the bottom edge
//      that clip into pockets — these are the REAL retention, the lip
//      is just for water/dust sealing.
//   3. Bigger / more obvious snap tabs (3 mm protrusion, easy to print).

$fn = 64;
WALL = 2.5;
TOL  = 0.4;
PART = "exploded";   // "backplate" / "body" / "lid" / "assembled" / "exploded"

// ─── Shared alignment constants (world Z) ─────────────────────────────
PEG_TOP_Z   = 80;
PEG_BOT_Z   = 25;
PEG_SPACING = 50;

// ─── Component dimensions ────────────────────────────────────────────
HELTEC_W = 50.8; HELTEC_H = 25.4;
HELTEC_MOUNT_DX = 45.0; HELTEC_MOUNT_DY = 19.0;
HELTEC_USB_W = 9.0; HELTEC_USB_H = 3.5;
HELTEC_OLED_W = 25.0; HELTEC_OLED_H = 14.0;
HOLDER_L = 77.0; HOLDER_W = 22.0;
BUTTON_DIA = 16.5;
HALL_DIA = 5.5;

// ─── Enclosure dimensions ────────────────────────────────────────────
W = 100; H = 130; D = 35;

// Front hook
HOOK_ARM = 32; HOOK_LIP = 22; HOOK_W = 22; HOOK_T = 9; HOOK_BASE_BOOST = 6;

// Backplate — thicker than v6 so it can contain the entire peg pocket
BP_W = 90; BP_H = 110; BP_T = 9;          // 9 mm thick — peg pocket fits inside
BP_SCREW_DIA = 4.5;
BP_SCREW_INSET = 10;

// Peg geometry (peg sticks out the BACK of the body, into the backplate)
PEG_HEAD_DIA = 9;
PEG_HEAD_T   = 2.5;
PEG_STEM_DIA = 4.5;
PEG_STEM_LEN = 3;         // total peg length = HEAD_T + STEM_LEN = 5.5 mm
PEG_TOTAL    = PEG_HEAD_T + PEG_STEM_LEN;

// Matching pocket in backplate (deeper than peg total so body sits flush)
POCKET_DEPTH    = 6.5;     // pocket is 1 mm deeper than the peg
POCKET_BIG_DIA  = PEG_HEAD_DIA + 1.5;
POCKET_SLOT_W   = PEG_STEM_DIA + 1.2;
POCKET_SLOT_LEN = 14;

// Lid lip-fit
LID_LIP_W = 2;            // lip thickness (out from lid perimeter)
LID_LIP_H = 4;            // how deep the lip sits into the body
LID_RECESS_W = LID_LIP_W + TOL;  // matching body recess

// Lid bottom snap tabs (2 of them, bigger than v6)
SNAP_TAB_W = 18;
SNAP_TAB_T = 3;           // bigger protrusion = better grip
SNAP_TAB_H = 5;

// Security screw (M3)
SEC_SCREW_DIA = 3.2;

// ─── Main render ─────────────────────────────────────────────────────
EX = PART == "exploded" ? 40 : 0;

if (PART == "body" || PART == "assembled" || PART == "exploded") body();

if (PART == "lid" || PART == "assembled" || PART == "exploded")
    translate([0, D + 5 + EX, 0])
        lid();

if (PART == "backplate" || PART == "assembled" || PART == "exploded") {
    bp_x = (W - BP_W) / 2;
    bp_y = (PART == "backplate") ? -BP_W - 25 : -BP_T - EX;
    translate([bp_x, bp_y, 0])
        backplate();
}

// ─── Backplate ───────────────────────────────────────────────────────
// 4 corner wall-screw holes + 2 keyhole POCKETS milled into the front
// face. Pockets are deep enough to swallow the peg entirely so the
// body sits flush against the backplate's front.
module backplate() {
    difference() {
        rounded_box(BP_W, BP_T, BP_H, r = 5);

        // 4 wall-mount countersunk screw holes
        for (x = [BP_SCREW_INSET, BP_W - BP_SCREW_INSET])
            for (z = [BP_SCREW_INSET, BP_H - BP_SCREW_INSET])
                translate([x, -0.1, z]) {
                    rotate([-90, 0, 0])
                        cylinder(d = BP_SCREW_DIA, h = BP_T + 0.2);
                    translate([0, BP_T - 2, 0])
                        rotate([-90, 0, 0])
                        cylinder(d1 = BP_SCREW_DIA, d2 = BP_SCREW_DIA + 5, h = 2);
                }

        // 2 keyhole pockets (cut INTO front face, NOT through-cuts)
        // Front face of backplate is at local y=0 — pocket opens HERE
        for (x_off = [-PEG_SPACING/2, PEG_SPACING/2])
            for (z = [PEG_TOP_Z, PEG_BOT_Z])
                translate([BP_W/2 + x_off, -0.1, z])
                    keyhole_pocket();

        // Security-screw thread receiver (bottom centre)
        translate([BP_W/2, BP_T/2, -0.1])
            cylinder(d = 2.6, h = 8);
    }
}

// Keyhole pocket — big circle at top + narrow slot extending DOWN.
// Cut into the FRONT face of the backplate (so body can press in and slide).
module keyhole_pocket() {
    // Big circle at peg's Z position
    rotate([-90, 0, 0])
        cylinder(d = POCKET_BIG_DIA, h = POCKET_DEPTH + 0.1);
    // Narrow slot going DOWN
    translate([-POCKET_SLOT_W/2, 0, -POCKET_SLOT_LEN])
        cube([POCKET_SLOT_W, POCKET_DEPTH + 0.1, POCKET_SLOT_LEN + 0.1]);
}

// ─── Body ────────────────────────────────────────────────────────────
module body() {
    difference() {
        union() {
            rounded_box(W, D, H, r = 5);

            // 4 pegs on BACK face (positioned to align with backplate pockets)
            for (x_off = [-PEG_SPACING/2, PEG_SPACING/2])
                for (z = [PEG_TOP_Z, PEG_BOT_Z])
                    translate([W/2 + x_off, 0, z])
                        peg();
        }

        // Hollow inside
        translate([WALL, WALL, WALL])
            cube([W - 2*WALL, D - WALL + 1, H - 2*WALL]);

        // Cleaning button (bottom face, centre)
        translate([W/2, D/2, -0.1])
            cylinder(d = BUTTON_DIA, h = WALL + 0.2);

        // USB-C cutout (left side)
        translate([-1, D/2 - 4, H - 35])
            cube([WALL + 2, HELTEC_USB_W + 2, HELTEC_USB_H + 2]);

        // Security screw hole (bottom, offset from button)
        translate([W/2 + 20, D/2, -0.1])
            cylinder(d = SEC_SCREW_DIA, h = WALL + 0.2);

        // ---- Lid lip RECESS around front-face perimeter ----
        // Cut a 2 mm trench into the inside edge of the front opening
        // so the lid's lip slides into it (Tupperware-style fit).
        translate([WALL - LID_RECESS_W, D - LID_LIP_H - 0.1, WALL - LID_RECESS_W])
            difference() {
                cube([W - 2*(WALL - LID_RECESS_W), LID_LIP_H + 0.2, H - 2*(WALL - LID_RECESS_W)]);
                translate([LID_RECESS_W, -0.1, LID_RECESS_W])
                    cube([W - 2*WALL, LID_LIP_H + 0.4, H - 2*WALL]);
            }

        // ---- Snap tab POCKETS on the BOTTOM inside edge of the body ----
        // The lid's 2 bottom tabs click into these.
        for (x_off = [-22, 22])
            translate([W/2 + x_off - SNAP_TAB_W/2, D - WALL - SNAP_TAB_T - 0.5, 6])
                cube([SNAP_TAB_W, SNAP_TAB_T + 1, SNAP_TAB_H]);
    }

    // Internal mounts
    translate([WALL + 4, WALL, WALL + 8]) battery_holder_seat();
    pcb_origin_x = (W - HELTEC_W) / 2;
    pcb_origin_z = H - 30 - HELTEC_H;
    for (dx = [(HELTEC_W - HELTEC_MOUNT_DX)/2, (HELTEC_W + HELTEC_MOUNT_DX)/2])
        for (dz = [(HELTEC_H - HELTEC_MOUNT_DY)/2, (HELTEC_H + HELTEC_MOUNT_DY)/2])
            translate([pcb_origin_x + dx, WALL, pcb_origin_z + dz])
                rotate([-90, 0, 0])
                pcb_post();
    translate([W/2 - HALL_DIA/2 - 1, D - WALL - 8, 45]) hall_bracket();
}

// Mushroom-headed peg — sized to fit in the backplate's pocket.
// Sticks out the BACK face of the body in the -Y direction.
// Stem (length PEG_STEM_LEN) first, then mushroom head at the far end.
module peg() {
    // Stem: from body back face (y=0) extending to y=-PEG_STEM_LEN
    rotate([90, 0, 0])
        cylinder(d = PEG_STEM_DIA, h = PEG_STEM_LEN);
    // Head: from y=-PEG_STEM_LEN extending to y=-(PEG_STEM_LEN+PEG_HEAD_T)
    translate([0, -PEG_STEM_LEN, 0])
        rotate([90, 0, 0])
        cylinder(d = PEG_HEAD_DIA, h = PEG_HEAD_T);
}

// ─── Lid ─────────────────────────────────────────────────────────────
// Flat plate + 3 mm raised lip around the perimeter (presses into the
// body's recess for a snug fit) + 2 bottom snap tabs for retention.
module lid() {
    difference() {
        union() {
            // Flat plate
            rounded_box(W, WALL, H, r = 5);

            // Raised lip around perimeter (sticks INTO the body)
            translate([WALL - LID_LIP_W, WALL, WALL - LID_LIP_W])
                difference() {
                    cube([W - 2*(WALL - LID_LIP_W), LID_LIP_H, H - 2*(WALL - LID_LIP_W)]);
                    translate([LID_LIP_W, -0.1, LID_LIP_W])
                        cube([W - 2*WALL, LID_LIP_H + 0.2, H - 2*WALL]);
                }

            // 2 bottom snap tabs (the real retention)
            for (x_off = [-22, 22])
                translate([W/2 + x_off - SNAP_TAB_W/2, WALL, 6])
                    snap_tab();
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

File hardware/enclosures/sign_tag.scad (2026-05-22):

// HazardLink — sign tag enclosure (UWB precision finding)
//
// Embeds in the handle of a wet-floor sign. Holds a Qorvo DWM3001CDK
// dev board, a 500mAh LiPo cell, and a 6×3 mm neodymium magnet that
// triggers the hanger's Hall sensor.
//
// Designed for IP67 potting — drop the assembled tag into the
// enclosure, fill with two-part epoxy, snap the lid on.
//
// Print in PETG for prototype; production version should be
// injection-moulded ABS for ruggedness in a wet environment.

$fn = 64;
WALL = 2;
TOL  = 0.25;

// External dimensions — fits the dev kit; production PCB will shrink
// these substantially (target 50 × 25 × 12 mm).
W = 70;
H = 35;
D = 16;

PART = "both";  // "body", "lid", "both"

if (PART == "body" || PART == "both") body();
if (PART == "lid"  || PART == "both") translate([0, 0, D + 5]) lid();

module body() {
    difference() {
        rounded_box(W, H, D - WALL, r = 3);
        translate([WALL, WALL, WALL])
            rounded_box(W - 2*WALL, H - 2*WALL, D, r = 2);
        // USB-C cutout for charging
        translate([-1, H/2 - 4.5, D/2 - 1.5])
            cube([WALL + 2, 9, 3.5]);
        // LED light pipe (charging indicator visible through enclosure)
        translate([W - 8, H/2, D - WALL - 0.5])
            cylinder(d = 2, h = WALL + 1);
        // Magnet recess at the bottom (6×3 mm magnet press-fits in)
        translate([W/2 - 3, 4, -0.1])
            cylinder(d = 6.2, h = 3.2);
    }
    // Battery cradle
    translate([5, H - 14, WALL])
        cube([60, 8, 4]);
}

module lid() {
    rounded_box(W, H, WALL, r = 3);
    translate([WALL + TOL, WALL + TOL, -1])
        rounded_box(W - 2*(WALL + TOL), H - 2*(WALL + TOL), 1, r = 2);
}

module rounded_box(w, h, d, r) {
    hull() for (x = [r, w-r]) for (y = [r, h-r])
        translate([x, y, 0]) cylinder(r = r, h = d);
}

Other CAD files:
hardware/enclosures/ref/heltec-wifi-lora-32-v3/WiFi_LoRa32_V3_mechanical_converted.dxf
hardware/enclosures/ref/heltec-wifi-lora-32-v3/WiFi_LoRa32_V3_mechanical.dwg
hardware/enclosures/v8/B/gateway_assembled.scad
hardware/enclosures/v8/B/gateway_assembled_front.scad
hardware/enclosures/v8/A/gateway_assembly.step
hardware/enclosures/v8/A/gateway_body.step
hardware/enclosures/v8/A/gateway_body_drawing.dxf
hardware/enclosures/v8/A/gateway_lid.step
hardware/enclosures/v8/A/gateway_lid_drawing.dxf
hardware/enclosures/v8/A/gateway_section.dxf
hardware/enclosures/v8/A/hanger_assembly.step
hardware/enclosures/v8/A/hanger_backplate.step
hardware/enclosures/v8/A/hanger_backplate_drawing.dxf
hardware/enclosures/v8/A/hanger_body.step
hardware/enclosures/v8/A/hanger_body_drawing.dxf
hardware/enclosures/v8/A/hanger_hook.step
hardware/enclosures/v8/A/hanger_hook_drawing.dxf
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

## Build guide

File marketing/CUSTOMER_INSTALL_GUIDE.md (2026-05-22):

# HazardLink — Customer Install Guide

For new customer sites. Hand-printable as a PDF, also lives at
`hazardlink.ie/install`.

Estimated time: **30 minutes per building** (5 hangers, 1 gateway,
1 phone/tablet for the admin).

---

## What's in the box

For a small site (10 hangers, 1 gateway):

- 10× HazardLink sign-hangers (the wall-mounted units)
- 10× HazardLink sign tags (small modules pre-paired to your wet-floor signs)
- 1× HazardLink gateway (the puck that talks to your Wi-Fi)
- 1× 6-port USB-C charging dock (Anker)
- 1× pack of N42 magnets (spares, you won't need them on day 1)
- 1× printed quick-start card (this document)
- USB-C cables for charging

## Before you start

You'll need:
- [ ] Phone or tablet (iOS 16+ or Android 8+)
- [ ] Wi-Fi network name + password for the building
- [ ] A drill + screws for wall-mounting the hangers (M3 × 20mm work fine)
- [ ] 15 minutes to download the HazardLink app on at least one admin phone

---

## Step 1 — Install the app + create your account

1. Open the App Store (iPhone) or Play Store (Android)
2. Search **HazardLink**, install
3. Sign up with your work email — you become the **admin** for your
   organisation by default
4. Add the people who'll respond to alerts (cleaners, supervisors)
   under **More → Users**

## Step 2 — Mount the gateway

The gateway only needs to be installed once per building.

1. Find a central location with Wi-Fi signal + power outlet
   (ceiling cupboard, IT room, supply room work well)
2. Plug in the USB-C cable + power adapter
3. The OLED screen lights up — it shows `BOR-Setup-XXXX` and a
   6-digit pairing PIN
4. Open the HazardLink app → **Hangers** → tap the **+ Add hanger**
   button at the top
5. The app scans for the gateway via Bluetooth — tap it when it
   appears
6. Enter the 6-digit PIN from the OLED screen
7. Type your Wi-Fi network name + password
8. Tap **Send to hanger** — the gateway joins Wi-Fi within 30 seconds

When the OLED shows `Online — 0 hangers paired`, you're done.

## Step 3 — Mount the hangers

For each location where you currently put a wet-floor sign:

1. Decide where the hanger goes — usually the wall above a mop bucket,
   near a hand-wash sink, by a kitchen entrance, etc.
2. The hanger is **150 × 80 × 30 mm** with two screw holes 100mm apart
3. Drill the holes, insert wall plugs, screw the hanger to the wall
4. Press the hanger gently — the OLED on the gateway should tick up
   (`Online — 1 hanger paired`)

If a hanger doesn't pair within 60 seconds:
- Make sure the gateway is online (OLED shows green status)
- Make sure the hanger is within 200m of the gateway
- Try moving the hanger 1m at a time until paired

## Step 4 — Hang your existing signs

Your wet-floor signs already have a magnet embedded in the handle
(we did this when you ordered — the sign tags include a magnet).

1. Take each wet-floor sign and hang it on its corresponding hanger
2. You should hear/feel a soft click as the magnet engages the
   Hall sensor inside the hanger
3. On the app, navigate to **Hangers** — each hanger should show
   **Online ✅ Sign present**

Test it:
1. Lift one sign off the hanger
2. Within 5 seconds, your phone should buzz with a "Sign lifted" alert
3. Tap **I'm on it** to acknowledge
4. Put the sign back — the alert auto-closes within 5 seconds

If the test alert doesn't fire:
- Check the hanger is online in the **Hangers** screen
- Check **Settings → Notifications** is enabled for HazardLink
- Email **support@hazardlink.ie** with the hanger ID

## Step 5 — Train your team

Invite each cleaner / supervisor via **More → Users → +**.

What each role sees:

| Role | App permissions |
|---|---|
| **Admin** (you) | Everything: settings, billing, hangers, users, analytics |
| **Supervisor** | Send dispatches, see all alerts, view reports |
| **Cleaner** | Receive alerts, ack/complete dispatches, see their shifts |

Each new user receives an email with a temporary password. They set
their own password on first login.

## Step 6 — Set your SLA thresholds (optional)

The default is:
- 5 minutes to acknowledge an alert
- 15 minutes to resolve

If a cleaner doesn't respond in 5 minutes, the alert auto-escalates
to supervisors. You can change these in **More → Settings**.

For after-hours sites:
- Configure **More → Settings → Night mode** to route alerts to a
  specific person (e.g. your night security guard) outside business hours

## Step 7 — Charging (every 12-18 months)

Hangers run on a 21700 lithium cell — about 12-18 months per charge.
When the dashboard warns "low battery":

1. Pop the cover off the hanger (snap-fit, no tools)
2. Plug a USB-C cable in — the included Anker dock holds 6 at once
3. Leave for 6 hours
4. Reattach to the wall

You don't lose any data during the charge — the gateway buffers events.

## Troubleshooting

**Hanger offline**
- Check the gateway is online
- Cycle the hanger battery (pop cover, briefly remove cell, reinsert)
- If still offline after 5 min, email support

**Alerts arriving late or not at all**
- Phone Wi-Fi or cellular issue — check internet
- Push notifications disabled — check phone Settings
- App backgrounded with restrictive battery saver — disable
  battery optimisation for HazardLink in phone Settings

**Sign "lifted" but cleaner didn't move it**
- Magnetic field disrupted — could be a strong metal object placed
  nearby. Move it away and reset by putting the sign back.

**Can I find a missing sign?**
- Yes — tap **Find sign** on the alert
- If your phone has UWB (iPhone 11+, Pixel 6 Pro+, Galaxy S21 Ultra+)
  you get an arrow + cm-accurate distance
- Otherwise you see the zone pin on the floor plan

## Support

- 📧 **Email**: support@hazardlink.ie (within 24h, usually faster)
- 💬 **Live chat**: hazardlink.ie/support (business hours, 9-5 Irish time)
- 📞 **Phone (emergencies)**: +353 (0)0 000 0000
- 📄 **Status page**: hazardlink.ie/status

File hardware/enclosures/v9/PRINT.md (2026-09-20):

# Printing the v9 enclosures on the BCN3D Epsilon W50

This sheet matches design v9.10. It is the single source of truth for the print recipe, so if another document disagrees with it, follow this one.

Files: `print/*.stl` are already rotated into the print orientation (do not rotate them in Stratos). `print/ORIENTATION.txt` lists the footprint and height of each one.

## What changed in v9.10

Every size in the design now comes from the makers' own drawings, 3D models and listings. "Where the sizes come from", further down, says which document gave which number. Nothing in this sheet asks for a measurement or a photo. The proof on the real parts is one small test print, the window gauge, which is the first job under Order.

- **The hanger box is 174 mm tall.** Gebildet's own drawing of the cleaning-mode button gives 46 mm overall with its plug-in wire socket on, which is 44.5 mm behind the head. The bay under the battery is 44 mm, so the hanger body is 174 mm tall (it was 171 in v9.9, and 130 before the button was added). The hanger lid is 100 x 174 and the backplate is 90 x 168. Everything inside keeps its place measured from the TOP of the box, so the display, the pads and the logo have not moved down the face.
- **The screen window sits over the picture.** The panel maker's drawing shows that the lit picture is 2.1 mm from the edge of the glass on the PRG side and 6.3 mm from the edge on the side where the display's ribbon leaves. The window is centred on that picture: 31.4 mm from the board's USB end and 1.8 mm toward the PRG button from the board's centreline. It is 24.0 x 13.1 mm, and it flares outward at 45 degrees through the 1.0 mm bezel (the thin front skin round the window), so the edge rows of the picture stay in view when the screen is seen from an angle.
- **The coil antenna has its own relief in the lid.** The coil antenna is the small spring that stands on the board between the USB end and the screen. Heltec's detailed 3D model gives its place. Over it the lid has a round relief 6.5 mm across under a 0.6 mm face skin, with air left above even a worst-case coil. Nothing may touch or squash the coil: Heltec say a squashed spring antenna causes resets. The coil is the tallest thing on the board, so it now sets how far back the board sits. The top face of the board is 4.4 mm behind the rim of the body, and the glass of a nominal 5.1 mm display sits 2.3 mm below the face of the lid.
- **The pads stop short of the coil.** The PRG and RST pads are 8.0 x 17.5 mm each. Their names run up the left side of each pad. The hanger lid has no LED light hole.
- **The display's ribbon is left alone.** The display's flat ribbon (its flex tail) folds over the lower long edge of the board, the RST side, between 23.6 and 39.2 mm from the board's USB end. The ledge the board rests on, the rib inside the lid, the board catch and the notch for the wires all keep clear of that stretch, and the lid and the pocket wall are relieved there. Never press on that fold when handling the board. The display's clear carrier is held by three small screws whose heads stand proud under the board. The board rests on its two long edges only, so those heads touch nothing. Do not pack anything under the board.
- **The hook bar is narrower, lower and longer.** The bar is 88 mm wide (it was 95) and hangs 46 mm below the body (it was 30). It reaches 86 mm out from the wall face. The seat is the shallow dip in the top of the bar that the sign's handle rests in (the README and the drawing labels call it the saddle). It is 42 mm wide, for a folded sign up to 38 mm thick. The small braces at the root of the lip are gone, so a folded sign can fill the seat right up to the lip. The Hall lift sensor sits under the middle of the seat. As printed the bar is 59.1 mm tall (it was 43.1).
- **The battery holder is drawn from its maker's figures.** The BeiLaMoo BH18650-PC2 is a copy of the MPD BH-18650-PC, and MPD's drawing gives the pins. The holder still stands 5.0 mm off the back wall, so nothing changes in how it prints or fits.
- **Colours.** The box is black, and the hook bar and the lettering are white. See Colours.

Print every part from the v9.10 files. A hanger body, lid, backplate, hook bar or test piece from an earlier version will not go with these. The gateway keeps its outside size, but its lid window and its board pocket follow the same makers' figures, so print both gateway parts from these files as well.

Part sizes, from `manifest.txt` and `print/ORIENTATION.txt`:

| Part | Size of the part | Footprint on the bed | Height as printed |
|---|---|---|---|
| hanger_body | 100 wide x 35 deep x 174 tall | 100 x 175 mm | 35.0 mm |
| hanger_lid | 100 x 174 | 100 x 174 mm | 17.1 mm |
| hanger_backplate | 90 x 168 | 90 x 168 mm | 17.0 mm |
| hanger_bar | 88 wide | 88 x 76 mm | 59.1 mm |
| hanger_body_coupon | front 14 mm of the body | 100 x 175 mm | 14.0 mm |
| hanger_window_gauge | the lid round the screen window and pads, with fences for the board | 61 x 43 mm | 9.8 mm |
| gateway_body | 120 x 30 x 80 | 120 x 81 mm | 30.0 mm |
| gateway_lid | 120 x 80 | 120 x 80 mm | 17.0 mm |

Each body takes about 1 mm more of the bed than its own size (175 against 174 for the hanger, 81 against 80 for the gateway) because the two pull lips under its latch arms stand 1.2 mm proud of the bottom wall. A latch arm is one of the two springy strips cut into the bottom wall that the lid's hooks click into.

## Material

Two spools of 2.85 mm PLA are loaded:

- **Nozzle 1: white PLA.** It prints the hook bar and the lettering on the lids.
- **Nozzle 2: black PLA (Polymaker PolyLite).** It prints everything else.

Slice both as PLA: in Stratos pick Generic > PLA (or BCN3D Filaments > PLA) for each nozzle, nozzle 215 C, bed 60 C, fan 100 % after the first two layers. Polymaker's own range for PolyLite PLA is 190 to 230 C nozzle, 25 to 60 C bed. If the label on the white spool gives a different range, stay inside it.

PLA is fine for the first test parts. For units that go on a wall long term use PET-G, which takes heat and repeated flexing of the latches better. The colour rule stays the same: white on nozzle 1, black on nozzle 2.

## Settings (Stratos, 0.4 hotend): strength first

The first print (Fine 0.15, 3 walls, 40 % infill) came out thin and poorly bonded. Use this instead:

| Setting | Value | Why |
|---|---|---|
| Layer height | 0.2 mm (Standard), first layer 0.2 mm as well | layers bond far better at 0.2, and it is about a third faster. The design counts on it too: the 0.6 mm face marks, the 0.6 mm skin over the coil antenna, the 1.0 mm display bezel, the 1.4 mm lid skin over the USB plug and every level of the sensor cavity in the hook bar are whole numbers of 0.2 mm layers |
| Wall line count | 4 (1.6 mm) | thin features come out as solid wall lines with nothing sparse inside them: the 2.0 mm latch arms and battery holder snap arms, the 2.5 mm box walls, the 3.0 mm lid hooks |
| Top / bottom thickness | 1.6 mm each | the 3 mm lid becomes a solid plate instead of two skins over sponge |
| Infill | 100 % for lids, the window gauge and the bar; 60 % gyroid for bodies, coupon and backplate | the bar carries the sign and the lid is handled; both must be solid. The gauge is a piece of the lid, so it prints like the lid |
| Printing temperature | PLA: 215 C. PET-G: the Stratos PET-G profile's own default plus 10 C | layer bonding |
| Fan | PLA: 100 % after layer 2. PET-G: 30 % max | PLA needs the cooling, PET-G does not |
| Print speed | 35 mm/s, outer wall 25 mm/s | quality on the visible faces without starving the extruder |
| Enable bridge settings | on | a bridge is a span the printer lays across open air. The closed front of the bar channel in the body is a 27 to 34 mm bridge, and the roof of the sensor tunnel in the hook bar is an 8.6 mm bridge that has to come out flat |
| Adhesion | brim 5 mm, with Brim Only on Outside ticked | a brim is a thin flat skirt printed round the part so that big flat faces stay stuck to the bed. It peels off afterwards. Brim Only on Outside keeps the brim off the inside of every hole, so none is laid in the pad slots, the window or the button hole. Stratos is built on Cura, where this setting sits under Build Plate Adhesion. If it is not in the list, type "brim" into the settings search box to show it |
| Supports | off for every part except the backplate, see per part | |

Dry the filament first if a spool has been open more than a couple of weeks: PLA 50 C, PET-G 65 C, 4 to 6 hours. Damp filament prints weak and stringy no matter what the slicer says.

## Per part

| Part | Orientation (already applied) | Support |
|---|---|---|
| hanger_lid, gateway_lid | outer face on the bed, hooks and hinge tabs pointing up | none. The catch face of each hook is a 1 mm overhang (an overhang is a piece of the print that sticks out sideways over open air), so keep the part fan running. On the hanger lid the display pocket and the round relief over the coil antenna are open toward the top of the print, and the flare round the window is a 45 degree slope, so none of them needs support |
| hanger_body, gateway_body | back face on the bed, open front up | none (channel end and hinge pockets are bridges). On the hanger body the 16.4 mm button hole goes through the bottom wall, which stands upright during the print, so the hole prints lying on its side as a round arch. It needs no support |
| hanger_body_coupon | the same way up as the body: cut face on the bed, open front up | none |
| hanger_window_gauge | outer face down, like the lid | none |
| hanger_backplate | back face on the bed, pegs pointing up | yes, touching buildplate only. The catch tongue is the springy strip in the face of the backplate that locks the body on. The cavity behind it is open to the back face on purpose, so support from the bed reaches the underside of the tongue. Pull the support out afterwards. |
| hanger_bar | standing on the bar's bottom face, lip pointing up | none at all. Every sloping underside on the bar is cut at 45 degrees, which a printer can build over open air without support. That covers the two sloping sides of the sliding tongue on top of the bar, the two triangular braces beside the narrow upright neck, and the brace under the front of the tongue. Leave support switched off for this part: anything generated inside the sensor tunnel, the nest or the pin holes can never be cleaned out. |

If the bar ever shares a plate with the backplate, switch support on for the backplate model only. With the colours below they are separate jobs anyway, because the bar is white and the backplate is black.

IDEX (the printer's two separate hotends): Duplication mode prints two copies of a part in one job, one from each hotend. It needs the same filament on both hotends, so with white on nozzle 1 and black on nozzle 2, print singly. Do not use Mirror mode (the parts are not symmetric).

## Colours: which part goes on which nozzle

Owen's choice: the box is black, and the hook under it, the logo and the button names are white. Nozzle 1 has the WHITE PLA and nozzle 2 has the BLACK PLA. Stratos calls nozzle 1 the left extruder (its print mode is Single 1) and nozzle 2 the right extruder (Single 2). The print mode is picked with the IDEX button on the left side of the Stratos window, which shows once a model on the plate has been clicked.

| Part | Colour | Nozzle | Stratos print mode |
|---|---|---|---|
| hanger_body, hanger_backplate, gateway_body | black | 2 | Single 2 |
| hanger_body_coupon, hanger_window_gauge (the two test pieces) | black | 2 | Single 2 |
| hanger_bar | white, the whole part | 1 | Single 1 |
| hanger_lid with hanger_lid_inlay | black lid, white lettering | lid on 2, inlay on 1 | Dual |
| gateway_lid with gateway_lid_inlay | black lid, white lettering | lid on 2, inlay on 1 | Dual |

### A black part

1. Open the STL from `print/`.
2. Click the part, click the IDEX button and choose **Single 2**. Only nozzle 2 works in this mode, so the part and its brim are all black.
3. Slice. In the preview every line, the brim included, should be drawn in the colour of extruder 2. Then send it.

### The hook bar, wholly white

1. Open `print/hanger_bar.stl`.
2. Click the bar, click the IDEX button and choose **Single 1**. Only nozzle 1 works in this mode, so no line of the bar comes from the black nozzle, and its brim is white as well.
3. Support off, infill 100 %, as in the tables above. Slice, check the preview, send.

### A lid: black with white lettering

The badge, the HazardLink name and the PRG and RST names are sunk 0.6 mm into the face of the lid. `print/hanger_lid_inlay.stl` is the same set of marks as a solid of its own, 0.6 mm thick, which fills them flush in white. The lid prints face down, so the white is laid in the first three layers, side by side with the black face, and black then prints over the back of it. Three layers keep the white solid white against the black behind it.

1. Open `print/hanger_lid.stl` and `print/hanger_lid_inlay.stl` in the same Stratos window. Use the copies in `print/`: they are already turned the right way up and they share one origin, which is what lets Stratos line them up.
2. Click either model, click the IDEX button and choose **Dual**, so that both nozzles work.
3. Give each model its nozzle BEFORE merging, because after merging a click picks up the pair. Stratos loads every model on the left extruder, so the lid is the one to change. Click the LID on its own and assign it to extruder 2 (black), with the extruder buttons that show on the left when a model is selected, or by right-clicking the model. Click the INLAY on its own, the thin set of letters and badge lines, and see that it is on extruder 1 (white).
4. Select both models (Cmd+A), right-click on them and choose **Merge Models**. The lettering drops into the sunken marks in the face of the lid. If it lands anywhere else, one of the files did not come from `print/`: clear the plate and load them again.
5. From here on move the merged pair as one. Do not move, turn or scale the lid or the inlay by itself.
6. Make the brim black. Find the setting that chooses which nozzle prints the brim (Cura calls it Build Plate Adhesion Extruder; type "adhesion" into the settings search box) and set it to extruder 2. A white brim round a black lid leaves white flecks along the edge when it is peeled off.
7. Slice and look at the preview layer by layer. Layers 1 to 3, the first 0.6 mm, show the badge, HazardLink, PRG and RST in white with black all round them. From layer 4 up everything is black. Then send it.

The gateway lid is done the same way with `print/gateway_lid.stl` and `print/gateway_lid_inlay.stl`.

The white lettering only lands square in its black surround if the printer's two hotends are calibrated to each other. Owen's printer is calibrated. The first lid in Order step 2 shows it on a real part.

If the white spool ever runs out, a lid printed alone in black still works: the same marks simply print as 0.6 mm sunken lines.

## Order: what to print first

No part waits for a measurement. The order below puts the cheapest proof first, so that any problem shows up on a small, quick print.

1. **`print/hanger_window_gauge.stl` FIRST.** Black, Single 2, the lid's settings, no support. It is the piece of the lid round the screen window and the two pads, with low fences on the inside that hold the board exactly where the body will hold it. Lay the board in it face down with its USB end against the two short stops, and push it flat with a finger on each bare end of the board. Keep fingers off the ribbon fold on the RST-side long edge and off the coil. Three checks:
   - The board lies FLAT on the two long ribs and does not rock. That proves the screen and the coil antenna fit under the lid.
   - Turn it over with the screen switched on. The WHOLE picture shows inside the window with a dark border all round, about the same left and right.
   - Press the PRG pad and the RST pad from the front. Each clicks its switch.

   If all three pass, the hanger lid and the hanger body are proven against the real board. If one fails, stop before the lid and the body and say which check failed. For the picture, say which edge it touches. Nothing needs measuring: the design is corrected from that answer.
2. **`print/hanger_body_coupon.stl` (black) and one hanger lid (black with white lettering, the Dual job above).** The coupon is the front 14 mm ring of the hanger body: the rim, both latch arms, the hinge ribs and the USB-C opening. It is a throwaway test piece. Print it whole, exactly as exported. Do not trim it or cut it down in the slicer, because its bottom edge carries the two latch arms it is there to test.
   - With the lid and the coupon, check that both lid hooks click into the arm windows, that the hinge tabs seat in the rib pockets, that the lid's lip sits inside the rim, and that the USB-C plug goes in with the lid on.
   - This is also the first two-colour print, so look at the lettering: white, flush with the face, and square in its black surround.
   - The coupon holds only the first 8 mm of the dovetail channel (the slot with sloping sides in the bottom wall of the body that the tongue on top of the hook bar slides into), so the real check of the dovetail fit is on the first full hanger body.
   - The button hole starts 13.1 mm back from the rim, so the coupon carries only a shallow scoop of it (about 0.9 mm) in the bed-side edge of its bottom wall, toward the right. That scoop is meant to be there. The real check of the button hole is on the first full hanger body.
3. **The hook bar (white, Single 1).** Check the pin holes and the sensor tunnel (see After printing).
4. **hanger_body and hanger_backplate (black, Single 2).**
5. **gateway_body (black) and gateway_lid (black with white lettering).**

## After printing

- Bodies and the coupon: push each latch arm tip OUTWARD once with a screwdriver, away from the inside of the box, which is the same way the pull lip under it moves. This breaks the arm's small breakaway tab. The tab is there so the arm prints cleanly. Do this before the first lid goes on.
- Hanger lid, inside: the round relief at the USB end of the display pocket leaves only a 0.6 mm skin at the face, and the bezel round the window is 1.0 mm. Do not scrape or poke either one when cleaning the lid up.
- Hanger body, button hole: take one of the Gebildet buttons with its blue plug-in wire socket unplugged and its nut taken off, and push the bare button up through the 16.4 mm hole from below (from outside the box). The socket will not pass through the hole, so it always goes on from inside afterwards. Its M16 thread should pass freely and its head should sit flat against the underside of the box. The side of the hole nearest the open front was the top of the arch during the print, so that is where it is most likely to have sagged. If the thread will not pass, ease the hole with a round file, a little at a time all the way round, and try the button again. Stop as soon as the thread goes through: the head is 18.8 mm across by Gebildet's drawing, so it only overlaps the wall by about 1.2 mm all round, and an oversize hole leaves it little to sit on. Only 1.4 mm of wall stands between the hole and the slot round the right latch arm, so file gently and never lever against that strip. Then check from inside that the button's nut spins on and turns freely between the side wall, the back wall and the channel strip (the raised strip in the floor of the box that the hook bar slides into).
- Hook bar, pin holes: the two holes in the floor of the seat take the pins that keep the Hall lift sensor in its nest. The Hall lift sensor is the small magnetic sensor that tells the unit the sign has been lifted, and the nest is the pocket at the end of the tunnel that it sits in. The pins are offcuts of 2.85 mm filament, cut 6.0 to 6.5 mm long (never longer, or the sign rests on the pins instead of the seat). White offcuts match the bar. The holes open through the tunnel roof in printed stages, so no drilling is needed. Try both pins in their holes now, BEFORE the sensor ever goes in: each offcut must drop in under its own weight and tip out again when the bar is turned over. If one is tight, ease it with a 3 mm drill, and set the depth before you start, because the bottom of the hole cannot be judged by feel. Each pin hole is 6.6 mm deep, and the ledge under it that the pin stands on is only 1.4 mm thick. A drill that goes through that ledge lets the pin fall straight through, and the only cure is a new bar. So wrap a flag of tape round the drill 6 mm from its tip. Twist the drill by hand only. Never put it in a power drill, because a spinning drill pulls itself down into plastic. Stop when the tape reaches the floor of the seat. Then try the pin again: it must drop in under its own weight and finish below the floor of the seat. Shake the chips out of the tunnel from the back before the sensor goes in, and never put a drill down a pin hole with the sensor in the bar.
- Hook bar, underside: under each pin hole a 2 mm hole comes out through the bottom face of the bar. It lets a stuck pin be pushed out from below with a 1.5 mm rod, and it drains the cavity. Check that both are open once the brim is off. A 2 mm hole printed straight off the bed often closes in the first layer. If one is closed, open it from below with a 2 mm drill twisted by hand, just until it breaks through.
- Hook bar, sensor tunnel: shine a torch into the tunnel from the back of the bar. It should be clean all the way to the nest, with no strings hanging from the roof. That roof is flat from the back of the bar to the front of the nest, and the sensor slides in along it with the bar held upside down. The only break in the roof is a shallow slot, one 0.2 mm layer deep, where the two pin holes open through just short of the nest. It is meant to be there. If support ever got into the tunnel, the nest or the pin holes, reprint the bar with support off.
- Hook bar, sliding fit: slide the tongue on top of the bar (its dovetail plate) into the channel in the bottom wall of the hanger body from the back of the body, and out again, a few times. If it is tight, give the two sloping sides of the tongue a light pass with 400 grit paper. The clearance is 0.45 mm per side.
- Gateway lid only: fit the 36 x 19.5 x 1 mm clear window insert from inside the lid under the two cleats (the two small ledges that hold it in). The pane is not on any order, see `SHOPPING.md`. The hanger lid takes no insert and has no cleats: the display module sits in its pocket with the glass behind the 1.0 mm bezel.
- Wall screws: 4 x No.8 countersunk with wall plugs for the backplate, 2 x No.8 pan head plus 1 for the lower hole for the gateway.

## Where the sizes come from

Every size below was taken from the maker's own document. Owen is not asked to measure or photograph anything. Positions on the board are given from the board's USB end (along it) and from its centreline (across it).

| Part | Maker's document | What it gave |
|---|---|---|
| Heltec WiFi LoRa 32 V3 board | Heltec's own 3D models (STEP files) of the board | the board outline, 51.7 x 25.4 mm, and where the USB-C port, the PRG and RST switches, the antenna socket and the display carrier sit. Display top 5.0 mm above the board |
| Display panel | Heltec's panel specification QG-2864KSWEG01, which matches Univision's drawing of the UG-2864HSWEG01 | the picture (active area) is 21.744 x 10.864 mm and the maker's view area is 23.744 x 12.864 mm. The picture sits 2.1 mm from the PRG-side glass edge and 6.3 mm from the ribbon side. With the glass position from Heltec's 3D model, the centre of the picture is 31.4 mm along the board and 1.8 mm toward PRG. The window is drawn 24.0 x 13.1 because printed holes close up a little. The panel maker's worst-case glass top is 5.25 mm above the board, and the floor of the lid's pocket is 6.4 mm above the board |
| Display ribbon fold | Heltec's 3D model and photos | the ribbon folds over the RST-side board edge between 23.6 and 39.2 mm along the board. The design keeps clear of it with 1 mm added at each end |
| Display carrier screws | Heltec's photo of the underside and the holes in its 3D model | three small screws, heads proud under the board |
| Coil antenna, position | Heltec's detailed 3D model | its leg hole is 13.08 mm along the board and 7.24 mm from the centreline on the PRG side |
| Battery holder, BeiLaMoo BH18650-PC2 | BeiLaMoo's listing for the body, 77.7 x 20.9 x 21.31 mm. It is a copy of the MPD BH-18650-PC, and MPD's drawing gives the rest | pins 3.30 mm long, 2.40 mm in from each end, flat tab 1.52 x 0.38 mm. MPD's tolerance is 0.5 mm, so the pocket keeps 0.5 mm a side. The holder stands 5.0 mm off the back wall, which clears a 4.8 mm allowance for the pin and the wire soldered to it |
| Cell, Murata US18650VTC6 | Murata's datasheet, maximum size | 18.5 mm across, 65.2 mm long |
| Cleaning-mode button, Gebildet 16 mm | Gebildet's own listing drawing, with the APIELE AP16B datasheet for the same family of button | M16 x 1 thread in a 16 mm hole (printed 16.4), head 18.8 mm across, 46 mm overall with the socket on. 46 less the 1.6 mm head is 44.5 mm behind the head, plus 6.0 mm for the wires to turn. The listing also says the LED is a 12 to 24 V type |
| Hall lift sensor, TI DRV5032FA | TI's datasheet SLVSDC7H | the package size and which leg is which |
| Magnet | the packing slip: XMP 6 x 2 mm N52 disc | its size |

The few numbers that no maker publishes, how each was worked out, and the margin added:

- **The height of the coil antenna.** Heltec do not publish it. Heltec's drawing puts the top of the display 5.0 mm above the board and the coil stands about 1 mm above the display, which makes 6.0 mm. The design treats that as 6.0 give or take 0.5. Margin: the lid keeps 0.3 mm of air over a 6.5 mm coil, which is 0.8 mm over a 6.0 mm one, under its 0.6 mm face skin. The coil's body is about 2.9 mm across, scaled from Heltec's photo of the board, and the clear circle round it is 6.5 mm.
- **The hand hole of the sign.** No sign maker publishes the size of the hand hole. The widths were scaled from the makers' own product photos against the overall sizes they do publish. The narrowest common one is the Rubbermaid FG6112xx at about 105 mm, which on the least favourable reading of the photo could be 92. Carlisle is about 111 and the generic UK and Irish 620 x 300 moulding is about 120. The bar is 88 mm wide, so it enters every one of them, with 4 mm in hand even at 92. A wider 108 mm bar for the generic moulding alone is one parameter in the design (BAR_W).
- **How thick a folded sign is, and how far it stands above its hand hole.** Rubbermaid publish a closed depth of 38 mm, the thickest of the common signs, so the seat is 38 plus 4, which is 42 mm. Scaled from the same photos, a sign stands 36 to 42 mm above the top of its hand hole. The bar hangs 46 mm below the body, so the top of a sign that stands the full 42 mm still clears the underside of the box by 5 mm. The 86 mm reach lets a folded sign 38 mm thick hang wholly in front of the hook's brace and of the button under the base.

A few sizes were taken from Owen's own parts in earlier rounds and are kept as they are: the plug of his USB-C lead, which set the 14.0 x 8.0 mm opening, the stub antenna with its jack, and the 25.6 mm blue socket of the button. Nothing more is needed for any of them.

## Button pads

The two pads in each lid (PRG and RST) are flaps with a 0.8 mm hinge. On the hanger lid they run down the left edge, PRG above the USB port and RST below it, 8.0 x 17.5 mm each, and they stop short of the coil antenna. Their names run up the left side of each pad and print in white with the inlay. The pads print flat on the bed, so they are strong in the direction they bend. No brim may be laid inside the 0.8 mm slots around them, which is what Brim Only on Outside in the settings table is for. If the first layer closes a slot anyway, run a blade along it. The hanger lid has no LED light hole. The gateway lid has one (1.8 mm); clear it with a pin if the first layer has closed it.

These two pads are the board's own PRG and RST buttons. They have nothing to do with the cleaning-mode button under the base.

## Seeing the design in AutoCAD and Fusion

The AutoCAD and Fusion views of the assembly refresh with no clicking. Two small start-up files do the work, and the whole refresh is a few lines typed in the `v9` folder. They are in `../autoload/README.md`.

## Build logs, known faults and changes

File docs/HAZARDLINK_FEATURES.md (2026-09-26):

# HazardLink — Complete Feature List

Use this as the source of truth when designing or building any HazardLink site or app. HazardLink is an Irish B2B SaaS platform (company: BOR Systems) that runs three on-site facilities disciplines — **Cleaning, Maintenance and Security** — on one system, over shared sites, assets and people. Managers use a web dashboard; field staff use native iOS/Android apps; contractors respond via white-label email links with no login.

---

## Platform (works across all three disciplines)
- One company, one login, multiple sites, three disciplines under one roof.
- Discipline switcher — pick Cleaning / Maintenance / Security; the sidebar adapts.
- Shared data: the same buildings/sites, assets and contacts power every discipline (nothing entered twice).
- Roles: admin, supervisor, field staff — role-based access throughout.
- Unlimited users on every plan.
- Web dashboard for the office + native iOS and Android apps for everyone on site.
- Command palette (⌘K) for fast navigation on the web.
- Staff onboarding by email invite link (admin adds a person → they get an email → set a password → land logged in).
- Notifications: push (iOS/Android), email and SMS, with automatic escalation.
- 30-day sessions with silent sliding refresh; data hosted in the EU.
- Reports, analytics, audit log and a system status page.

## The cross-discipline "moat" (the differentiator)
- Anyone on site (cleaner, technician or guard) can report a fault from their phone and it becomes a costed maintenance work order automatically.
- Shared sites, assets and contacts mean no double entry across disciplines.
- Managers see all three disciplines on one dashboard.

## Cleaning
- IoT wet-floor-sign sensors ("hangers") detect when a sign is put out or lifted and report it instantly with a timestamp and location.
- Real-time spill alerts to cleaners and supervisors.
- Automatic escalation if a spill isn't resolved / a sign isn't returned in time.
- Anti-theft and tamper detection (sign moved or removed when it shouldn't be).
- Low-battery monitoring for every sensor.
- Live floor-plan view — every sign as a pin on your actual building floor plan; upload floor plans; define zones.
- Cleaner dispatch and shift scheduling.
- Mobile quality inspections — scored checklist with photo proof and an overall score; a failed item can become a maintenance job.
- QR rounds — scan, confirm, photograph.
- Devices view — hangers and gateways organised by building, with detail/edit, registration by ID, and phone-based (BLE) discovery and setup.

## Maintenance (CMMS)
- Asset register with full service history, criticality, meters/readings and warranties.
- Work orders: logged → assigned → in progress → done, with a full activity timeline; priorities (emergency / urgent / routine).
- Planned preventive maintenance (PPMs): schedules, due tracking and automatic reminders.
- Parts and inventory.
- Contractor tendering and quoting by white-label email — contractors get a link, quote in the browser, no login or app.
- AI quote ranking on overall value (not just lowest price) and AI scope-of-works drafting.
- Maintenance dashboard and KPIs: PM compliance, mean-time-to-repair, open backlog.
- AI continuous-improvement suggestions from your live data.
- Staff certifications / competency tracking.
- Tenant/occupant fault reporting (QR → work order).

## Security
- Incident reporting with severity (low / medium / high / critical), status, and photos; AI incident triage suggests a severity and immediate actions.
- Guard tours and patrols; checkpoints via NFC / QR / GPS; checkpoint scans with photo proof.
- Lone-worker safety: check-ins, panic alarm and man-down, with watcher escalation.
- Daily activity reports.

## SDS — Safety Data Sheets
- Per-organisation chemical library, filed by discipline (cleaning / maintenance / security / general).
- Scan a product barcode → it checks your library first, then (optionally) a paid SDS database, then a free product-identity lookup to pre-fill the name/brand.
- For a new product, upload the SDS (PDF or photo) and AI reads it — strictly from the document, never invented; anything it can't find is left blank and flagged.
- Captures: product, manufacturer, signal word, GHS pictograms, hazard (H) and precautionary (P) statements, listed components (name / CAS / %), first aid, storage & handling, PPE, issue/revision/review dates.
- A "verified / needs review" state — AI-read sheets are confirmed by a person before they're trusted.

## AI (Claude), used throughout
- Ask-your-data assistant — plain-English answers from your real records.
- Voice → work order — speak a fault, get a structured job to confirm.
- Contractor scope drafting and quote ranking.
- Incident triage; asset-history summaries; improvement suggestions; SDS extraction.
- Core principle: it never invents facts. Included on every plan.

## Hardware (built in-house)
- Hanger sensor (Heltec WiFi LoRa 32 / ESP32): Hall-effect sign detection, long battery life via deep sleep, on-demand OLED (battery + signal), HMAC-secured LoRa radio.
- Gateway (mains-powered): receives LoRa from many hangers and forwards securely to the cloud over WiFi; self-registers on boot.

## Pricing
- Per site, unlimited users, all three disciplines on every plan.
- Starter €99/month (up to 3 sites) · Growth €299/month (up to 15 sites, recommended) · Enterprise custom.
- Optional spill-detection sensors at cost.

---

## Brand & design direction (so it doesn't look AI-made)
- Colours: trust-blue `#2563EB`; deep ink `#0b1220`; slate neutrals; off-white `#F8FAFC`. Accents: Cleaning `#0891B2`, Maintenance `#D97706`, Security `#4F46E5`.
- Fonts: Space Grotesk (headings) + Inter (body) for marketing; all-Inter for the app.
- Marketing hero: premium dark and lit (subtle glow + faint grid), a realistic product panel floating with depth. App: light theme + dark sidebar, minimalist enterprise SaaS.
- Line SVG icons, never emoji. Visible focus rings. Subtle, tasteful motion.
- Hard rules: human-written copy (no heavy em-dashes, no "not X but Y", no clipped one-word headlines); no fabricated stats, ratings, customer counts, logos, testimonials or "free trial" claims.

## Honesty / build status (don't over-claim on a public site)
- Live today: web app + marketing site, the full CMMS, Cleaning, Security, the cross-discipline fault→job flow, inspections, onboarding, and the SDS library on web.
- In progress (don't present as finished): SDS on mobile, full mobile feature parity, SMS/push notification rollout, precise UWB sign-finding.
- It's fine to market the platform and its capabilities; just don't invent numbers, customers or results.

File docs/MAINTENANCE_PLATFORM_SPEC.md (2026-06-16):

# HazardLink — Maintenance & Tendering Platform

**Product spec — v0.1 (draft for sign-off). No code until this is agreed.**

A blueprint pulled together from the planning conversations. Mark it up freely —
nothing here is built yet.

---

## 1. What it is

A platform that runs building maintenance end-to-end: on-site staff log an issue,
the system writes the scope, tenders it to the *right* contractors, gates them on
safety/compliance, schedules the work, and scores how they did — so the next job
is smarter. It grows out of the existing HazardLink IoT safety product (the wall
sensors become one more source of jobs).

**North star: "log it and walk away."** It must be usable by anyone, first try —
*walk-a-four-year-old-through-it* simple. Most work is done **for** the user; the
user's day is a short list of one-tap decisions. (The whole market fails on exactly
this — see §18.)

**Brand:** stays **HazardLink** across the board; the wet-floor safety product
becomes one module under it.

**Data is sacred (system-wide):** GDPR-by-design and **clear data ownership** across
*both* the HazardLink safety side and maintenance — every party owns, and can
export, their own data; nothing is shared without cause. A first-class principle,
not an afterthought.

## 2. Business model (decided)

- **Subscription**, not a cut of each job.
- **Middleman / organiser only — no liability.** The contractor's own insurance
  carries the risk for the work.
- **No escrow, no holding funds.** Payments happen between the parties. The system
  only **surfaces + records** a contractor's upfront material-deposit request
  (amount + %) for approval. (An in-app payment link is a possible later add.)
- **Flexible "orchestrator" role** — the entity running the tender can be a
  *customer* (a maintenance company) **or** us (the platform itself). Same engine,
  different operator. White-label capable.
- **Go-to-market sequence:** sell first as a **tool for maintenance companies**
  (they bring their own contractors + money flows → fastest revenue, no liquidity
  problem), then **flip to "platform as a generalised maintenance company"** (a
  two-sided marketplace) once a contractor network exists.

## 3. The parties (roles)

| Role | Does |
|---|---|
| **Orchestrator** | Runs tenders, approves scopes/dates, owns the contractor list. A maintenance company today; could be the platform later. |
| **Building owner / landlord** | Owns the building; pays for landlord-side work. |
| **Managing agent** | (Optional) acts for the owner. |
| **Tenant** | Leases a space; may report issues and be recharged for work in their area. |
| **Contractor — office** | Submits quotes, uploads RAMS + certs + insurance, sets start dates. |
| **Contractor — operative** | The lads on site: sign RAMS, check in/out, do the work, mark complete. |

Everyone sees only their slice (extends the existing org + role model).

## 4. Core data model (shape, not schema)

- **Sites:** Building → Floor → Zone (already exists) + **Tenant register** — the
  maintenance company adds their own tenants, kept light (who they are + their
  area). Responsibility / bill-to is chosen **per job** (see §8), not modelled as
  full lease terms.
- **Assets:** every maintainable item (HVAC, boiler, lift, fire panel, doors…) with
  location, make/model/serial, install date, **expected life, warranty expiry**,
  docs (manuals/certs), QR/NFC tag, and a **trade** (see §5).
- **Trades taxonomy** (see §5).
- **Contractors:** company profile + **trades they cover** + accreditations +
  insurance (with expiry) + region + **performance score + tier** (see §9).
- **Jobs (work orders):** the spine — reactive or planned (PPM), linked to an
  asset/zone, a trade, a bill-to party, a lifecycle (see §6).
- **Quotes, RAMS/permits, schedule entries, ratings, budgets** all hang off jobs
  and/or assets.

## 5. Trade-based routing (jobs go only to who does that trade)

A job is classified by **trade/discipline**, and the tender invite list is built
**only** from contractors who cover that trade — plus region, availability,
compliance, and tier. An electrician never sees a lift job.

- **Trade taxonomy** — full researched list in
  [TRADES_TAXONOMY.md](TRADES_TAXONOMY.md) (10 groups, ~70 trades, statutory ones
  flagged), with an **"Other — type your own"** catch-all on every list so the
  system never blocks on an unusual need.
- **Trade-specific accreditation** — the compliance gate is per trade (gas → RGI /
  Gas Safe; electrical → registered + EICR; lifts → LOLER competent; fire → alarm/
  extinguisher certs). A contractor missing the trade's cert can't be tendered for
  it.
- **Contractors can hold multiple trades.**
- **Assets carry a trade**, so a job raised against an asset is pre-classified.
- **AI auto-classifies the trade** from the logged issue (human can correct).
- **Multi-trade jobs** (e.g. a refit needing electrical + mechanical) split into
  **packages**, each tendered to its own trade — or routed to a multi-trade
  contractor.

## 6. The job lifecycle (end to end)

```
LOG → AI SCOPE → APPROVE → TENDER (trade-routed) → AI RANK → AWARD
  → RAMS + DATE (propose/counter) → COMPLIANCE GATE → SCHEDULE
  → DO → COMPLETION SIGN-OFF → INVOICE → RATE
```

1. **Log** — staff/tenant log an issue (QR on the asset, photo, two taps), or a
   sensor/PPM raises it automatically.
2. **AI scope** — AI drafts the job scope + classifies the trade + lists the RAMS/
   certs that trade requires.
3. **Approve** — orchestrator taps "happy to proceed?" → it runs itself from here.
4. **Tender** — auto-sent to the matching contractor shortlist (trade + region +
   available + compliant + not blocked), **always including your preferred
   contractor for that trade** (§9a).
5. **AI rank** — AI normalises wildly different quotes into one apples-to-apples
   table, **benchmarks price vs market**, and always surfaces the two numbers that
   matter: **your preferred contractor's price vs the cheapest**, with the gap
   ("preferred is £120 / 8% more"). **AI recommends; a human decides;** the choice
   and its reason are recorded (feeds the budget/audit trail).
6. **Award** → ask the winner for **RAMS + earliest start date**.
7. **Date handshake** — the date goes back to the orchestrator: *approve / counter*
   → repeat until agreed. (Reuse this propose/counter pattern for quotes &
   variations.)
8. **Compliance gate** — RAMS signed by the operatives + insurance/certs valid +
   permits in place. **No sign-off = job shows "DO NOT START"; can't be marked
   started.**
9. **Schedule** — agreed job drops into the **central scheduler** (conflict-aware:
   no double-booking a contractor).
10. **Do** — operatives check in (QR/geofence), photos before/during/after.
11. **Completion sign-off** — site contact confirms it's done to standard → this
    **releases the invoice**.
12. **Invoice** — matched against the awarded quote; over-quote is flagged.
13. **Rate** — performance scored (see §9) → feeds the next tender.

**Auto-chase engine (the magic):** the system nudges whoever's holding things up —
contractor hasn't quoted, manager hasn't approved, RAMS unsigned, cert expiring,
PPM due. Nothing stalls because a human forgot.

**"Needs your attention" inbox:** the orchestrator's whole day is a short list of
one-tap calls — *Approve scope? Approve date? PPM due — tender it?*

## 7. Compliance / RAMS / permit-to-work (premium tier)

1. **Company prequalification** (one-time, expiry-tracked): insurance, trade
   accreditation, H&S policy. Expired = can't be awarded.
2. **Per-job pack** — contractor office uploads the RAMS for *that* job + permits
   (hot works, height, isolation/LOTO).
3. **Operative sign-off** — the lads digitally sign the RAMS; their own competencies
   tracked (Safe Pass, trade card, induction).
4. **The gate** — anything missing/expired/unsigned → "DO NOT START" + site contact
   notified.
5. **Site check-in/out** — who was on site, when.
6. **Audit-ready pack** — one-click export of every cert/RAMS/sign-off for an
   insurer or HSA inspection.

## 8. Billing flexibility

- **Per-job bill-to:** Landlord · specific Tenant · Maintenance-co-absorbs — set by
  *where* it happened + lease responsibility.
- **Recharge with markup** — when the maintenance co rebills a tenant/owner, track
  cost vs recharge so margin per job is visible.
- **Service-charge apportionment** for shared/common-area costs across tenants.
- **Upfront deposit** — record + approval only (not money-movement).

## 9. Contractor performance loop

**Mostly auto-scored (facts, low effort, defensible):** on-time vs approved date ·
responsiveness · final invoice vs quote (overruns) · compliance docs on time ·
callbacks/rework · variation frequency.

**Human adds ~10s after the job:** quality thumbs-up + "any issues?" quick tags
(no-show, mess, damage, near-miss) + optional note.

**What the AI does:** weights the score in tender ranking (**Recommended** /
**Caution** with reasons); auto-tiers **Preferred → Approved → On-notice →
Blocked**; surfaces patterns ("4 of last 6 jobs over schedule").

**Reports:** per-contractor scorecards monthly/quarterly/annual + league table.

**Fairness (keeps us safe as a no-liability middleman):** contractors see their own
scorecard and get a **right-of-reply** on flagged issues.

**Long game:** accumulated track records become a portable reputation asset — the
thing that makes the marketplace flip work later.

## 9a. Preferred contractors

A maintenance company curates a **Preferred list** — their habitual, trusted go-tos
— **per trade** (a preferred electrician *and* a preferred lift firm). It's separate
from the auto-performance tier above: *you* pin who you trust; the system only
**suggests** ("X has been 5★ on the last 6 jobs — make preferred?") and **flags
slippage** ("your preferred Y has had 2 recent overruns").

How they're treated (configurable):
- **Default — always tender, show two prices.** The job still goes to competitive
  tender, but the award screen always presents **the preferred contractor's price
  next to the cheapest**, with the gap shown — the client chooses with both numbers
  in front of them, and going preferred-over-cheapest auto-records its reason
  (feeds the budget/audit trail).
- **First refusal** (optional) — offer the preferred contractor first; open wider
  only if they pass or can't hit the date.
- **Direct award** (optional) — routine/low-value jobs or PPMs skip the tender.
- **Rate cards** (later) — agreed prices with a preferred contractor so routine work
  auto-prices with **no quote at all**. The ultimate "log it and walk away."

## 10. Lifecycle & capital planning (finance hook)

- **Total cost of ownership per asset** → **repair-vs-replace** flag when cumulative
  repairs approach replacement cost.
- **Condition + remaining useful life → rolling 5-year CapEx forecast**: "Under
  budget this year, but 3 AC units hit end-of-life in 2027 (~£18k)…"
- **Warranty tracking** (never pay for covered work).
- **Budgets:** OpEx vs CapEx, actual vs forecast.

## 11. AI's role (summary)

Draft scope · classify trade · normalise quotes · benchmark price · rank +
recommend (never auto-award) · detect performance patterns · triage logged issues.
Always **recommend-not-decide**, always with a recorded rationale.

## 12. IoT synergy (the moat)

The existing sensors feed maintenance: a recurring wet-floor alert in one spot →
likely a leak → **auto-raise a job**. Sensor data + asset history →
**predictive maintenance**. No software-only competitor can copy this — they have
nothing on the wall.

## 13. UX principles (non-negotiable)

- One **timeline per job**; one **message thread per job**; one **"needs your
  attention"** inbox.
- One decision per screen, big buttons, mobile-first for site.
- **Job templates** pre-fill scope + required RAMS/certs (logging = two taps).
- Offline-tolerant on site (queue actions).
- **Deliberately deferred** to protect simplicity: parts/inventory, energy/ESG,
  deep accounting integration.

## 14. Phasing

- **Phase 1 — the loop that sells:** asset register + trades + contractor list →
  log → AI scope → trade-routed tender → AI rank → award with justification →
  date handshake → central scheduler → completion sign-off. PPM auto-chase.
- **Phase 2 — premium compliance:** RAMS / permit-to-work gate, prequalification,
  audit pack + the **contractor performance loop**.
- **Phase 3 — finance + flip:** lifecycle/TCO/CapEx forecast, billing/recharge,
  predictive maintenance, then **platform/marketplace mode**.

## 15. Pricing (to firm up)

Subscription tiers — e.g. Core (tender loop + scheduler) / Compliance (RAMS, certs,
audit) / Insights (lifecycle, CapEx, performance analytics). Per site or per seat.

## 16. Decisions

**Settled:**
1. **Trades** — researched taxonomy in [TRADES_TAXONOMY.md](TRADES_TAXONOMY.md) +
   an **"Other — type your own"** option everywhere. (Refine the list to taste.)
2. **Tenant register** — maintenance company populates their tenants; kept light;
   responsibility/bill-to chosen per job.
3. **Contractor onboarding** — a **portal**, which also shows each contractor their
   **full work history within a building** (a real draw for them to stay on it).
4. **Pricing** — deferred; not a blocker now. Subscription, tiers TBD.

**Still open:**
- Exact subscription tiers + unit (per building / seat / contractor) — later.
- Final trade list sign-off (add/remove from the taxonomy doc).

## 17. Confirmed additions

- **Comms = email, white-labelled.** Tenders, chases and notifications go out by
  **email sent as the maintenance company** (their name/address), so contractors
  deal with *them*, not a faceless platform; contractors respond via one-tap email
  links — **no login needed**. (Per-customer sending identity with SPF/DKIM.)
- **"Never miss a cert" engine.** Statutory due-date tracker (fire annual, EICR
  5-yr, LOLER 6-mo, legionella, TM44…) that auto-raises + auto-tenders each renewal
  *before* it lapses, reminders escalating. A headline selling point.
- **Spend approval / authority.** Per-role spend limits; awards over a threshold
  need the FM/owner's sign-off.
- **Priority & emergencies.** Emergency / Urgent / Routine with target times;
  **emergencies skip the tender** → straight to the on-call contractor on a
  different clock; SLA breaches escalate.
- **Warranty tracking.** Each job/asset holds its warranty window + the supplier's
  warranty cert — so a failure inside the window is a **free callback** (no
  re-tender, no payment, dings the score) and **nobody chases warranty certs**.
- **Frictionless, flexible onboarding.** Many ways to load assets/contractors/
  tenants: manual, **bulk spreadsheet import**, and AI assist (snap an insurance/
  warranty cert → it reads the expiry). Day-1 setup must be effortless.
- **GDPR + data ownership, system-wide** (see §1).

## 18. Market gap & positioning

The market is **siloed** — each tool does one slice and ignores the rest:
- **CMMS** (UpKeep, MaintainX, Limble, Fiix): great at work orders + assets, but
  assume you already have a contractor — **no competitive tendering, no contractor
  compliance/RAMS gating**, weak on procurement/recharge; IoT is enterprise-only.
- **Contractor field-service** (Joblogic, simPRO, Commusoft): built for the
  *contractor's* business — the wrong side of the table from the building owner.
- **E-procurement / tender** (FM Navigate, SAP Ariba): tendering exists, but as a
  **standalone enterprise module** disconnected from work orders, compliance and
  assets — and pricey ($50–200/user/mo).
- **Contractor compliance** (SafeContractor/CHAS-type): RAMS/insurance vetting is a
  **separate product**, not gated into the actual job flow.

**Nobody joins them up.** An owner/orchestrator today runs ~5 disconnected tools
plus spreadsheets and phone/email for quotes.

**And the incumbents' fatal flaw is adoption:** ~80% of CMMS never reach their
potential and 50–70% are judged failures — overwhelmingly because they're **too
complex**; people simply won't log a job through a clunky, multi-screen form. That
*validates* the simplicity obsession as the real wedge, not a nice-to-have.

**The gap (our wedge):** one **dead-simple** platform for the **maintenance
orchestrator** that runs the whole loop — sensor/issue → AI scope → competitive
AI-evaluated tender to a vetted list → built-in **compliance gate** → schedule →
rate → **lifecycle/CapEx** — that's **email-native (no contractor login)** and
**simple enough to actually get used.**

**Two things no competitor can copy:** (1) the **IoT already on the wall** →
affordable sensor-driven jobs; (2) the **orchestrator/middleman position** with
flexible **landlord/tenant recharge** billing.

**Beachhead:** SMB / mid-market maintenance companies + property managers (UK/IE) —
too small for Planon/Archibus/Ariba, underserved by work-order-only CMMS, and their
business literally revolves around the tendering + compliance + recharge that no
affordable tool integrates.

**Positioning line:** *"The maintenance platform people actually use — log it, and
it handles the quotes, the compliance and the contractors for you."*

*Sources: best-CMMS roundups (UpKeep, Limble, Software Connect); CMMS-failure/
adoption analyses (Tractian, ClickMaint, AnyMaint); FM tender/procurement (FM
Navigate, SAP Ariba). See chat for links.*

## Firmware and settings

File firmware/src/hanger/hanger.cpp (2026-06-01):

#include "hanger.h"
#include "hanger_beacon.h"
#include "../battery.h"
#include "../config/nvs_store.h"
#include "../display.h"
#include "../lora_link.h"
#include "../../include/pinout.h"

#include <Arduino.h>
#include <esp_sleep.h>
#include "driver/rtc_io.h"   // RTC pull config for the deep-sleep wake pin

namespace {

// Forward decl — defined below, but enterDeepSleep()/currentEventType() (which
// appear earlier) need it to read the debounced sign state.
bool signPresentDebounced();

// Heartbeat cadence on battery: once a DAY. The hanger is event-driven — a
// sign lift/return is a hardware (Hall) wake that fires an instant alert and
// goes straight back to sleep. This daily timer is only the "still alive"
// check-in so the dashboard can tell a healthy-but-quiet hanger from a dead /
// removed / flat one. Deep sleep (~tens of µA) dominates the energy budget, so
// daily vs hourly is a negligible battery difference but a far longer life and
// a calmer fleet. The dashboard's "online" window is widened to match (~26 h)
// so a once-a-day hanger never looks falsely offline.
constexpr uint64_t HEARTBEAT_INTERVAL_US = 24ULL * 60ULL * 60ULL * 1000000ULL;

// Heartbeat cadence while AWAKE (USB / commission / button window) — once a
// minute, same as the gateway, so the dashboard updates promptly during
// install + bench testing. On battery the device is asleep between these, so
// this only applies during the brief awake windows.
constexpr uint32_t USB_HEARTBEAT_INTERVAL_MS = 60UL * 1000UL;

// Battery-% streaming cadence while plugged into USB-C charging. 30 s gives a
// live charging readout without flooding the LoRa link. Only active while
// charging; unplugging drops straight back to deep-sleep operation.
constexpr uint32_t CHARGE_STREAM_INTERVAL_MS = 30UL * 1000UL;

// How long the OLED stays lit after a fresh power-on while on battery. Long
// enough for an installer to read the DevEUI off the screen and confirm the
// unit booted + reacts to the sign, then it goes dark to save the cell. On
// USB the screen ignores this and stays on the whole time (bench/commission).
constexpr uint32_t SCREEN_COMMISSION_MS = 60UL * 1000UL;

// How long the OLED stays lit after the PRG button is pressed. The installer
// presses it to read the DevEUI + check the live link strength to the gateway,
// then it goes dark again. "One minute" per the spec.
constexpr uint32_t SCREEN_WAKE_MS = 60UL * 1000UL;

// Set once in setup() from the wake cause: true only on a true power-on (the
// battery was just connected / reset pressed), false on a deep-sleep timer or
// Hall-edge wake. Gates the post-boot screen window so it shows when a unit is
// first powered up, not on every wake.
bool g_freshBoot = true;

// Set in setup() when this wake was an ext1 (Hall) wake whose debounced sign
// state did NOT change vs the level we slept at — i.e. electrical noise on a
// floating pin, not a real lift/return. The loop uses it to go straight back
// to sleep without spending a LoRa packet, while staying armed for the next
// genuine transition.
bool g_noiseWake = false;

// ── Hall-wake handling (state survives deep sleep in RTC memory) ──
//
// The Hall pin is an ext1 deep-sleep wake source so a sign lift/return fires an
// instant alert. Two realities we must handle TOGETHER:
//
//   1. A REAL event changes the debounced sign state (on-hook ↔ lifted) → send
//      the exact Lifted/Returned transition, then re-arm for the opposite edge.
//   2. NOISE on a floating/flaky pin trips ext1 but the debounced state reads
//      the SAME as when we slept. A bare/dangling wire on the high-impedance
//      pull-up behaves like an antenna and does this; a real DRV5032 drives the
//      line hard and won't.
//
// CRITICAL: a no-change (noise) wake must NOT permanently disable the Hall
// wake — doing so was a real bug: after the sign was lifted, floating-pin noise
// disabled the wake, so plugging the sign back ("Returned") never woke the
// device and the alert never closed. Instead, a no-change wake is simply
// CHEAP: we skip the LoRa send and go straight back to sleep (~ms, negligible
// battery), STILL ARMED. So the genuine next transition is always caught.
//
// g_rtcSleepSignLevel = the debounced level we slept at, so a wake can tell a
// real transition (level changed → send) from noise (level same → re-sleep).
RTC_DATA_ATTR int g_rtcSleepSignLevel = -1;   // -1 = unset (first boot)

// Consecutive noise wakes (Hall wake, no state change) — drives an escalating
// backoff so a floating/broken sensor wire can't spin the CPU+radio every ~0.5s
// and drain the battery. Each noise wake re-sleeps for a SHORT timer instead of
// re-arming bare; the backoff grows 2s→4s→…→cap so worst-case floating settles
// to a few wakes/min, not a few/sec. A REAL transition (or a normal timer wake)
// resets it to 0 so instant alerts are never slowed by past noise.
RTC_DATA_ATTR int g_rtcNoiseRun = 0;
constexpr uint32_t NOISE_BACKOFF_BASE_S = 2;     // first noise re-sleep
constexpr uint32_t NOISE_BACKOFF_MAX_S  = 8;     // cap: bounds worst-case real-
                                                 // transition latency on a
                                                 // BROKEN pin to ≤8s (a working
                                                 // sensor never enters backoff),
                                                 // while cutting noise wakes 16×

// Threshold for sending an EVT_LOW_BATTERY (1-shot) ahead of the scheduled
// heartbeat. Kept aggressive — the cloud already has the % from every
// heartbeat, this is a "wake the operator up" signal.
constexpr uint8_t LOW_BATTERY_PCT = 15;

// timerOverrideUs: if non-zero, use this as the timer-wake interval instead of
// the normal daily heartbeat.
// armHall: if false, do NOT arm the Hall ext1 wake — sleep timer-only. Used for
// the noise backoff: a floating pin re-trips ext1 in ~0.5s, far sooner than any
// timer, so a longer timer alone can't slow it. Disarming the Hall wake for the
// backoff window is the only thing that actually caps the noise rate; we
// re-arm on the very next wake, so a real transition during the backoff is
// caught at most `timerOverrideUs` later (≤64s) — still effectively instant for
// a spill, and this path only ever runs on a broken/floating sensor anyway.
void enterDeepSleep(uint64_t timerOverrideUs = 0, bool armHall = true) {
    Serial.flush();

    // Park the LoRa radio so it isn't burning ~10 mA in the SX1262 RX/idle
    // state through the whole sleep — without this, deep sleep saves almost
    // nothing.
    LoraLink::sleep();

    // Cut the Vext rail (OLED + battery divider quiescent draw).
    pinMode(Pinout::VEXT_CTRL, OUTPUT);
    digitalWrite(Pinout::VEXT_CTRL, HIGH);  // HIGH = off on Heltec V3

    // ── Wake sources (ESP32-S3) ──
    //
    // The S3 has NO ext0 (that's ESP32-classic only); the wake-on-GPIO
    // primitive is ext1 — a bitmask of RTC pins with ONE shared trigger
    // polarity (ANY_HIGH or ANY_LOW) for the whole mask.
    //
    // We wake the radio on TWO things:
    //   • the hourly timer        → scheduled "still alive" heartbeat
    //   • the Hall sensor CHANGING → sign lifted or re-hung = instant alert
    //
    // The subtlety that bit the first version: the Hall pin is NOT always
    // idle-HIGH. With the sign on the hook (the normal resting state) the
    // magnet is present and the pin reads LOW. So a fixed "wake on LOW" fires
    // immediately and the device wake-loops forever — draining the battery
    // worse than no sleep at all (observed: woke in <1 s, wake cause = ext1).
    //
    // Correct approach: wake on the level OPPOSITE to the Hall pin's CURRENT
    // level — i.e. wake-on-change. If the sign is on (LOW now) we arm ANY_HIGH
    // so lifting it (→HIGH) wakes us; if it's off (HIGH now) we arm ANY_LOW so
    // re-hanging it (→LOW) wakes us. Either way the very next sign movement is
    // an instant wake + LoRa send.
    //
    // The PRG button is deliberately NOT an ext1 wake source: it idles HIGH
    // (opposite the common sign-on-hook LOW), so it can't share the Hall pin's
    // single polarity, and waking from deep sleep on it isn't needed — the
    // installer interacts during the post-boot/awake window. A press while
    // asleep is simply ignored until the next timer/Hall wake.
    const gpio_num_t hallPin = static_cast<gpio_num_t>(Pinout::HALL_SENSOR_PIN);
    // Use the DEBOUNCED sign level for both the wake polarity and the guard's
    // remembered level, so they can never disagree (a single raw digitalRead
    // could catch a transient and arm the wrong edge).
    const bool signOnHook = signPresentDebounced();   // true == magnet present == LOW
    g_rtcSleepSignLevel = signOnHook ? LOW : HIGH;

    // Normally arm the Hall wake (wake-on-change): sign on (LOW) → wake when it
    // goes HIGH (lifted); sign off (HIGH) → wake when it goes LOW (re-hung).
    // Hold the matching internal pull so the pad rests at its current level and
    // only a real movement crosses the threshold. We do NOT permanently disable
    // it (that broke alert-close) — but during a noise backoff we arm it
    // timer-only (armHall=false) so a floating pin can't re-trip ext1 every
    // ~0.5s; it re-arms on the next wake.
    const uint64_t timerUs = timerOverrideUs ? timerOverrideUs : HEARTBEAT_INTERVAL_US;
    if (armHall) {
        const esp_sleep_ext1_wakeup_mode_t mode =
            signOnHook ? ESP_EXT1_WAKEUP_ANY_HIGH : ESP_EXT1_WAKEUP_ANY_LOW;
        rtc_gpio_pullup_dis(hallPin);
        rtc_gpio_pulldown_dis(hallPin);
        if (signOnHook) rtc_gpio_pulldown_en(hallPin);  // hold LOW until lifted
        else            rtc_gpio_pullup_en(hallPin);    // hold HIGH until re-hung
        esp_sleep_enable_ext1_wakeup(1ULL << hallPin, mode);
        log_i("deep sleep (%llu us timer + Hall wake; sign=%s, mode=%s)",
              timerUs, signOnHook ? "ON-HOOK" : "LIFTED",
              signOnHook ? "ANY_HIGH" : "ANY_LOW");
    } else {
        // Backoff: timer-only, Hall disarmed for this short window.
        esp_sleep_disable_wakeup_source(ESP_SLEEP_WAKEUP_EXT1);
        log_i("deep sleep (%llu us timer ONLY — Hall disarmed for noise backoff)",
              timerUs);
    }
    esp_sleep_enable_timer_wakeup(timerUs);

    esp_deep_sleep_start();   // does not return — boots fresh through setup()
}

uint8_t flagsForUplink() {
    uint8_t f = 0;
    // Use the voltage-trend charge signal (works on bare boards where the VBUS
    // pin floats), so the "charging" flag the dashboard shows matches the
    // charging-stream behaviour in the loop.
    if (Battery::chargingByVoltage()) f |= static_cast<uint8_t>(LoraLink::Flags::IsCharging);
    return f;
}

LoraLink::EventType currentEventType() {
    const uint8_t pct = Battery::readPercent();
    const bool signPresent = signPresentDebounced();

    // SAFETY FIRST: a lifted sign is the whole point of the product, so it
    // ALWAYS wins. If the sign is off the hook we report Lifted regardless of
    // battery — the spill alert must fire. (Battery % rides along in every
    // packet anyway, and the daily heartbeat still surfaces a low cell, so we
    // never lose the low-battery signal by prioritising the spill.)
    if (!signPresent) return LoraLink::EventType::Lifted;

    // Sign is on the hook. Only now is a low-battery heartbeat meaningful.
    // Require a CONFIDENT low reading (1–LOW_BATTERY_PCT): a flat 0 almost
    // always means the measurement failed (no cell / divider), not a truly
    // dead pack, so don't spam low_battery on a glitch. Suppress while charging
    // (voltage-trend signal) — a low-but-rising pack isn't a problem.
    if (pct > 0 && pct <= LOW_BATTERY_PCT && !Battery::chargingByVoltage()) {
        return LoraLink::EventType::LowBattery;
    }
    return LoraLink::EventType::Heartbeat;
}

// Event to send on a Hall-sensor wake (or any time we need the exact sign
// transition rather than a generic state report). On a real wake the sign just
// moved, so report it explicitly: absent → Lifted (open the spill alert),
// present → Returned (close it). currentEventType() can't express Returned —
// it only ever reports the steady state — which is why re-hanging the sign was
// silently sending Heartbeat and never closing the alert.
LoraLink::EventType signTransitionEvent() {
    return signPresentDebounced() ? LoraLink::EventType::Returned
                                  : LoraLink::EventType::Lifted;
}

// Last sign state we REPORTED to the cloud, persisted across deep sleep.
//   1 = on hook (reported Returned/Heartbeat),  0 = lifted (reported Lifted),
//  -1 = unknown (first boot — send the current state to establish a baseline).
// This is the key to never missing a close: on EVERY wake we compare the live
// sign state to what the cloud last heard. If it differs we send the exact
// transition — so even if the Hall wake was disarmed during a noise backoff,
// or the return happened to land on a timer wake, the next wake of ANY kind
// still sends Returned and closes the alert. Without this, a return that
// didn't land on a clean Hall-wake silently became a Heartbeat and the alert
// stayed open forever (the reported bug).
RTC_DATA_ATTR int g_rtcReportedOnHook = -1;
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
void loop() {
    // ── Noise wake: re-sleep immediately, still armed ──
    //
    // setup() flagged this as an ext1 wake whose sign state didn't change =
    // electrical noise on a floating pin, not a real lift/return. Don't spend a
    // packet, don't open the awake window — a brief settle then straight back
    // to sleep (re-arming the Hall wake). Negligible battery; the genuine next
    // transition is still caught. (Skipped in the STAY_AWAKE bench build, which
    // never sleeps.)
#ifndef BOR_HANGER_STAY_AWAKE
    if (g_noiseWake) {
        delay(40);            // let the pin settle so we don't immediately re-trip
        // Escalating backoff: 2s, 4s, 8s … capped, so a floating/broken pin
        // can't spin the radio every ~0.5s and drain the cell. A real
        // transition or a timer wake resets g_rtcNoiseRun to 0 (see setup()),
        // so genuine instant alerts are never slowed by past noise.
        uint32_t backoffS = NOISE_BACKOFF_BASE_S << (uint32_t)(g_rtcNoiseRun - 1);
        if (backoffS > NOISE_BACKOFF_MAX_S || backoffS == 0) backoffS = NOISE_BACKOFF_MAX_S;
        // Sleep timer-only (Hall disarmed) for the backoff window — that's the
        // ONLY thing that actually stops a floating pin re-tripping ext1 in
        // ~0.5s. Re-armed on the next wake, so a real transition is caught
        // within `backoffS` (≤ the cap) — only ever relevant on a broken pin.
        enterDeepSleep((uint64_t)backoffS * 1000000ULL, /*armHall=*/false);
    }
#endif

    // ── When is the OLED lit? ──
    //
    // By default it's OFF — that's what keeps a wall-mounted, battery-powered
    // hanger alive for months. It lights up in exactly two cases:
    //   1. a short window right after power-on (so an installer can read the
    //      DevEUI + confirm it booted and reacts to the sign), and
    //   2. for one minute after the PRG button is pressed.
    // Otherwise it stays dark — on battery AND on USB.
    //
    // We deliberately DON'T try to keep it lit "whenever on USB". The bare
    // Heltec V3 can't reliably tell USB from battery (the VBUS divider isn't
    // populated, and the USB-CDC link state isn't trustworthy on this board),
    // so any USB-vs-battery guess risks leaving the screen on during battery
    // use — defeating the point. The boot window + button are deterministic.

    // ── Persistent loop state ──
    static int      screenState     = 1;   // 0 off, 1 on (setup leaves it on)
    static uint32_t screenWakeUntil = 0;   // millis() deadline for a PRG-wake
    static uint32_t lastSendMs      = millis();
    static uint32_t lastDispMs      = 0;
    static LoraLink::EventType lastEvent = currentEventType();
    static bool     prevSignPresent = signPresentDebounced();
    static bool     prevPrgDown     = false;
    static uint32_t lastPressMs     = 0;

    // ── PRG button (GPIO0): wake the screen for a minute and refresh the live
    // link reading. Falling edge = press, with a 1 s bounce guard so one press
    // is one ping. The installer taps it to read the DevEUI and see how strong
    // the link to the gateway is from this exact spot. ──
    const bool prgDown = digitalRead(Pinout::PRG_BUTTON_PIN) == LOW;
    if (prgDown && !prevPrgDown && (millis() - lastPressMs > 1000)) {
        lastPressMs     = millis();
        screenWakeUntil = millis() + SCREEN_WAKE_MS;
        Display::on();                 // light it immediately (idempotent)
        screenState = 1;
        Display::showStatus("HazardLink Hanger", Config::getDevEui(),
                            "Checking gateway", "link...");
        // One fresh round-trip so the RSSI shown is current as of the press.
        LoraLink::sendEvent(currentEventType(), Battery::readPercent(),
                            flagsForUplink());
        lastSendMs = millis();
        lastDispMs = 0;                // force a status redraw next tick
    }
    prevPrgDown = prgDown;

    // Screen on during the post-wake window (fresh boot OR a Hall/PRG wake from
    // deep sleep) or an in-session PRG press; dark otherwise. Both deep-sleep
    // wake reasons that a human triggers should show the screen so the
    // installer gets feedback for the press they just made.
    const bool inCommissionWindow =
        g_freshBoot && millis() < SCREEN_COMMISSION_MS;
    const bool inButtonWake       = millis() < screenWakeUntil;
    const bool wantScreenOn       = inCommissionWindow || inButtonWake;

    // Keep the OLED rail in sync. Toggle only on a real transition so we don't
    // re-pulse the panel every iteration. off() cuts the Vext rail entirely
    // (true power saving); on() re-inits the controller (see display.cpp) so an
    // in-session PRG press relights it cleanly.
    const int wantScreen = wantScreenOn ? 1 : 0;
    if (wantScreen != screenState) {
        if (wantScreen) Display::on(); else Display::off();
        screenState = wantScreen;
    }

    // ── BLE discovery beacon ──
    //
    // Broadcast the DevEUI over BLE for the SAME window the screen is lit: the
    // post-boot window and after a PRG-button press. That's exactly when an
    // installer is standing at the unit with the app open trying to add it, so
    // it shows up as "hanger nearby" — no typing the code. Outside the window
    // the beacon is off and the device is LoRa-only, as designed.
    static int beaconState = 0;            // 0 off, 1 on
    const int wantBeacon = wantScreenOn ? 1 : 0;
    if (wantBeacon != beaconState) {
        if (wantBeacon) HangerBeacon::start(Config::getDevEui());
        else            HangerBeacon::stop();
        beaconState = wantBeacon;
    }

    // ── Charging mode: stream battery % while plugged into USB-C ──
    //
    // When charging we're not battery-constrained, so stay awake and report the
    // battery percentage to the cloud on a fast cadence — a live "charging,
    // NN%" readout. The moment USB is unplugged we fall straight through to the
    // deep-sleep path below and resume the years-long battery operation.
    //
    // Detection: the bare Heltec V3's VBUS-sense pin (GPIO4) isn't populated
    // (measured raw≈107 while plugged in), so isCharging() can't see USB. We
    // instead infer charging from the battery-VOLTAGE TREND — rising, or pinned
    // near full — via chargingByVoltage(), which works on any board and has its
    // own noise hysteresis. Safety: the charging branch never sleeps, but the
    // moment the trend says "not charging" we fall straight through to deep
    // sleep, so a discharging pack can never be stranded awake.
    static uint32_t lastChargeSendMs = 0;
    static bool chargeStreamLogged = false;
    const bool charging = Battery::chargingByVoltage();

    if (charging) {
        if (!chargeStreamLogged) {
            log_i("USB charging detected (VBUS) — streaming battery %% every %lus",
                  (unsigned long)(CHARGE_STREAM_INTERVAL_MS / 1000));
            chargeStreamLogged = true;
        }
        // Stream the battery percentage on a fast cadence while plugged in.
        if (lastChargeSendMs == 0 ||
            millis() - lastChargeSendMs >= CHARGE_STREAM_INTERVAL_MS) {
            const uint8_t pct = Battery::readPercent();
            // currentEventType() still lets a lifted sign win (safety), and the
            // IsCharging flag rides along so the dashboard shows "charging".
            LoraLink::sendEvent(currentEventType(), pct, flagsForUplink());
            lastChargeSendMs = millis();
            lastSendMs       = millis();
            log_i("charging — battery %d%%", pct);
        }
        // Keep the screen showing live status while plugged in.
        if (millis() - lastDispMs > 1000) {
            lastDispMs = millis();
            Display::on();
            showHangerStatus();
        }
        delay(20);
        return;   // never sleep while charging
    } else {
        chargeStreamLogged = false;   // re-arm the log for the next plug-in
    }
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

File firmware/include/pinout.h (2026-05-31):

// Heltec WiFi LoRa 32 V3 pinout — ESP32-S3 + SX1262
//
// Reference: https://heltec.org/project/wifi-lora-32-v3/
// Reference: https://wiki.heltec.org/docs/devices/open-source-hardware/esp32-series/lora-32/wifi-lora-32-v3/
//
// All GPIO numbers here are ESP32-S3 GPIOs (the silkscreen on the board
// labels them with the IO number, e.g. "IO8" → GPIO8).
#pragma once

#include <cstdint>

namespace Pinout {

// ─── SX1262 LoRa transceiver (SPI bus) ──────────────────────────────────────
constexpr int LORA_NSS    = 8;   // SPI chip-select
constexpr int LORA_SCK    = 9;
constexpr int LORA_MOSI   = 10;
constexpr int LORA_MISO   = 11;
constexpr int LORA_RST    = 12;
constexpr int LORA_BUSY   = 13;
constexpr int LORA_DIO1   = 14;  // IRQ — wake source on RX done

// ─── On-board 0.96" SSD1306 OLED (I²C bus) ──────────────────────────────────
constexpr int OLED_SDA    = 17;
constexpr int OLED_SCL    = 18;
constexpr int OLED_RST    = 21;

// ─── Power rails ────────────────────────────────────────────────────────────
// Vext = external power rail (powers OLED + battery divider). Drive LOW to
// enable, HIGH to cut. Keep it OFF during deep sleep to save battery.
constexpr int VEXT_CTRL   = 36;

// Battery voltage measurement: 390k/100k divider on Vbat. Driven by VBAT_CTRL
// to save power — only enable for a few ms during a reading.
constexpr int VBAT_PIN    = 1;   // ADC1_CH0
constexpr int VBAT_CTRL   = 37;  // drive LOW to enable divider

// ─── On-board PRG / USER button ──────────────────────────────────────────────
// The button silk-screened "PRG" next to RST on the Heltec V3 is wired to
// GPIO0 (the boot-strapping pin). Held during reset it enters the ROM
// bootloader (how we flash); pressed during normal run it just reads LOW and
// we use it as a user button — e.g. "wake the OLED for a minute to show the
// DevEUI + link strength" while installing. It has an external pull-up, and we
// also enable the internal one. RTC-capable (GPIO0 ≤ 21) so it can wake from
// deep sleep later if needed.
constexpr int PRG_BUTTON_PIN = 0;

// ─── User LED ───────────────────────────────────────────────────────────────
constexpr int LED_PIN     = 35;  // single user-visible LED on the board

// ─── BOR-specific GPIOs (wired by the hanger PCB) ───────────────────────────
//
// We pick GPIOs that:
//  - are RTC-capable (so they can wake from deep sleep)
//  - don't conflict with the SPI/I²C buses above
//  - aren't strapping pins
//
// On the ESP32-S3, RTC GPIOs are 0–21. Available after carving out the
// LoRa/OLED/battery pins: 0, 2, 3, 4, 5, 6, 7, 15, 16, 19, 20.
constexpr int HALL_SENSOR_PIN  = 6;   // DRV5032FA OUT — sign-presence sensor.
                                       //   LOW  = magnet present (sign on hook)
                                       //   HIGH = magnet absent  (sign lifted)
                                       // Wakes ESP32 from deep sleep on edge.
                                       //
                                       // NB: GPIO7 is NOT broken out to a header
                                       // pad on the Heltec V3 (it's used
                                       // internally) — the original choice was
                                       // unsolderable. GPIO6 IS exposed (bottom
                                       // row, near the OLED end), RTC-capable,
                                       // and not a strapping pin. Hall OUT
                                       // solders here.

constexpr int TEST_BUTTON_PIN  = 3;   // momentary button — used for the
                                       // cleaning-mode start trigger and
                                       // factory-reset (long press → re-arm
                                       // BLE setup mode). Moved off GPIO6 to
                                       // free that pad for the Hall sensor;
                                       // GPIO3 is also exposed + RTC-capable.

constexpr int VBUS_SENSE_PIN   = 4;   // USB VBUS sense (via resistor divider).
                                       // HIGH = plugged into USB → charging.
                                       // Used to set the is_charging flag in
                                       // outbound heartbeat packets.

// Optional buzzer for sites that want audible alerts. Not soldered on the
// default hanger BOM; only present on premium variant.
constexpr int BUZZER_PIN       = 5;

}  // namespace Pinout

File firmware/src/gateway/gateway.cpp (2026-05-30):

#include "gateway.h"
#include "../button_handler.h"
#include "../config/nvs_store.h"
#include "../display.h"
#include "../lora_link.h"
#include "../ota.h"
#include "../setup_mode/setup_mode.h"
#include "../../include/pinout.h"

#include <Arduino.h>
#include <ArduinoJson.h>
#include <HTTPClient.h>
#include <WiFi.h>
#include <WiFiClientSecure.h>
#include <set>
#include <string>

namespace {

constexpr uint32_t WIFI_TIMEOUT_MS = 30000;

// Map our internal EventType to the string the backend webhook expects.
const char* eventName(LoraLink::EventType t) {
    switch (t) {
        case LoraLink::EventType::Lifted:          return "lifted";
        case LoraLink::EventType::Returned:        return "returned";
        case LoraLink::EventType::Heartbeat:       return "heartbeat";
        case LoraLink::EventType::LowBattery:      return "low_battery";
        case LoraLink::EventType::CleaningStarted: return "cleaning_started";
    }
    return "unknown";
}

bool connectWifi() {
    const String ssid = Config::getWifiSsid();
    const String pass = Config::getWifiPassword();
    if (ssid.isEmpty()) return false;

    log_i("connecting to Wi-Fi %s", ssid.c_str());
    WiFi.mode(WIFI_STA);
    WiFi.begin(ssid.c_str(), pass.c_str());

    const uint32_t start = millis();
    while (WiFi.status() != WL_CONNECTED) {
        if (millis() - start > WIFI_TIMEOUT_MS) {
            log_e("Wi-Fi connect timeout");
            return false;
        }
        delay(250);
    }
    log_i("connected — IP %s, RSSI %d dBm",
          WiFi.localIP().toString().c_str(), WiFi.RSSI());
    return true;
}

// Base64-encode 4 raw bytes (no padding edge cases — 4 bytes → 8 chars incl
// one '=' pad). Tiny standalone encoder so we don't pull in a library.
static String base64_4(const uint8_t in[4]) {
    static const char* T =
        "ABCDEFGHIJKLMNOPQRSTUVWXYZabcdefghijklmnopqrstuvwxyz0123456789+/";
    char out[9];
    out[0] = T[(in[0] >> 2) & 0x3F];
    out[1] = T[((in[0] & 0x03) << 4) | ((in[1] >> 4) & 0x0F)];
    out[2] = T[((in[1] & 0x0F) << 2) | ((in[2] >> 6) & 0x03)];
    out[3] = T[in[2] & 0x3F];
    out[4] = T[(in[3] >> 2) & 0x3F];
    out[5] = T[(in[3] & 0x03) << 4];
    out[6] = '=';
    out[7] = '=';
    out[8] = '\0';
    return String(out);
}

void forwardToCloud(const LoraLink::ReceivedPacket& p) {
    // The backend webhook (/webhook/tts) decodes the TTN/LoRaWAN uplink
    // shape: end_device_ids.dev_eui + a base64 frm_payload it then decodes
    // as our 4-byte event packet (event, battery, fw, flags). We MUST send
    // exactly that shape — an earlier flat {dev_eui, event, …} body was
    // rejected with 400 "missing dev_eui or frm_payload" and silently lost
    // every real hanger event.
    //
    // Re-encode the 4 payload bytes from the fields we decoded off LoRa:
    //   byte0 = event type code (1=lifted … 5=cleaning_started)
    //   byte1 = battery %
    //   byte2 = fw version (already packed major<<4|minor)
    //   byte3 = flags
    uint8_t raw[4];
    switch (p.type) {
        case LoraLink::EventType::Lifted:          raw[0] = 1; break;
        case LoraLink::EventType::Returned:        raw[0] = 2; break;
        case LoraLink::EventType::Heartbeat:       raw[0] = 3; break;
        case LoraLink::EventType::LowBattery:      raw[0] = 4; break;
        case LoraLink::EventType::CleaningStarted: raw[0] = 5; break;
        default:                                   raw[0] = 3; break;
    }
    raw[1] = p.batteryPct;
    raw[2] = p.fwVersion;
    raw[3] = p.flags;

    JsonDocument doc;
    doc["end_device_ids"]["dev_eui"] = p.devEui;
    doc["uplink_message"]["f_port"]  = 1;
    doc["uplink_message"]["frm_payload"] = base64_4(raw);
    // Pass LoRa link quality through as extra fields — the webhook ignores
    // unknown keys, but they're handy if we later log signal strength.
    doc["uplink_message"]["rx_metadata"][0]["rssi"] = (int)p.rssi;
    doc["uplink_message"]["rx_metadata"][0]["snr"]  = p.snr;

    String body;
    serializeJson(doc, body);

    // TODO(tls): once the backend has a real cert we should pin it. For now
    // we accept anything to keep the prototype simple. Render's CA chain
    // is fine for production.
    WiFiClientSecure client;
    client.setInsecure();
    // ── Three separate timeouts, three separate failure modes ──
    //   setHandshakeTimeout: TLS handshake (default 120s!) — the actual
    //     killer; sockets that get stuck mid-TLS hang the whole loop here
    //     for two minutes per failed attempt without this set.
    //   setTimeout: socket read after connection — established phase.
    //   HTTPClient.setConnectTimeout: TCP connect (set below).
    client.setHandshakeTimeout(5);  // seconds
    client.setTimeout(4);            // seconds

    HTTPClient http;
    // Total time we're willing to block on a single POST. Covers TCP connect
    // + TLS handshake + send + response. 5 s is generous for a 200-byte
    // payload to Render Frankfurt over a typical WiFi link.
    http.setConnectTimeout(5000);
    http.setTimeout(5000);
    http.setReuse(false);

    if (!http.begin(client, Config::getWebhookUrl())) {
        log_w("http.begin() failed — skipping forward");
        return;
    }
    http.addHeader("Content-Type", "application/json");
    const String secret = Config::getWebhookSecret();
    if (!secret.isEmpty()) {
        http.addHeader("X-BOR-Secret", secret);
    }

    const int code = http.POST(body);
    if (code <= 0) {
        // Negative codes from HTTPClient mean transport-level failure
        // (timeout, connection refused, TLS error). Don't try to read the
        // body — it just produces another timeout.
        log_w("webhook POST transport error: %d", code);
    } else if (code != 200 && code != 204 && code != 202) {
        log_w("webhook POST failed: %d body=%s",
              code, http.getString().c_str());
    } else {
        log_i("webhook ok — %s evt=%s batt=%d%%",
              p.devEui, eventName(p.type), p.batteryPct);
    }
    http.end();
}

}  // namespace

namespace {

uint32_t g_packetsForwarded = 0;
uint32_t g_lastOtaCheckMs   = 0;
uint32_t g_lastHeartbeatMs  = 0;
uint32_t g_bootMs           = 0;
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

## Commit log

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2026-05-13 Add WiFi-mode hanger: Pi-in-the-hanger that talks straight to cloud
    Two Pi roles now supported by the same codebase:
    - gateway (existing): receives LoRa packets via concentrator hat, runs
    status server. Talks to cloud via The Things Stack.
    - hanger (NEW): Pi mounted in the hanger itself, microswitch on GPIO,
    HTTPS straight to /webhook/tts. No LoRa hardware, no gateway.
    New files:
    - pi/wifi_hanger.py — daemon: reads microswitch (GPIO 17), drives red/
    green LEDs (GPIO 22/27), test button (GPIO 23), optional buzzer
    (GPIO 24). Sends LoRaWAN-shaped 4-byte payloads to the cloud webhook
    on state changes, plus a 24h heartbeat. Uses gpiozero + lgpio
    (Pi 5 compatible).
    - pi/services/bor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
    [install.py, wifi_hanger.py]
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2026-05-14 Pi: suppress red LED + buzzer when sign is lifted during cleaning mode
    [wifi_hanger.py]
2026-05-17 Pi: reconcile microswitch state on every heartbeat — fixes stuck-alert after idle hours
    [wifi_hanger.py]
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2026-05-19 Firmware: scaffold Heltec V3 (ESP32-S3) C++ port — hanger + gateway + wifi-direct
    Replaces the old RAK3172 / STM32 sketch with a full PlatformIO project for
    the Heltec WiFi LoRa 32 V3. One source tree, three build envs:
    pio run -e hanger # battery hanger, deep sleep + LoRa
    pio run -e gateway # mains gateway, LoRa rx → HTTPS forward
    pio run -e hanger_wifi # mains hanger, WiFi direct to cloud
    Fully implemented modules:
    - config/nvs_store: persistent settings in ESP32 NVS, DevEUI auto-derive
    - battery: voltage divider read, LiPo curve, USB VBUS sense
    - lora_link: RadioLib SX1262 wrapper, 12-byte event packets
    - setup_mode: NimBLE GATT server — byte-identical UUIDs t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
    [battery.cpp, gateway.cpp, hanger.cpp]
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2026-05-19 Firmware Batch 2: OTA + HMAC LoRa + ACK/retry + OLED + long-press reset
    Production-grade hardening for the Heltec V3 firmware.
    OTA updates (src/ota.{h,cpp}):
    - HTTPS manifest fetch from cloud (model + channel + current-version)
    - esp_https_ota streams + flashes + reboots
    - markRunningImageGood() called only after Wi-Fi + LoRa init succeed,
    so a firmware that crashes on boot automatically rolls back to the
    previous slot via the ESP32 bootloader
    - Gateways check every 6 hours; battery hangers will check weekly
    LoRa link hardening (src/lora_link.{h,cpp}):
    - 20-byte payload now includes 2-byte seq + 6-byte truncated HMAC-SHA256
    - Per-device 32-byte HMAC key generated once on first boot, pe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
    [display.cpp, gateway.cpp]
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2026-05-22 Rebrand: BOR Systems → ZeroSlip (display strings only)
    Bulk-renamed every user-visible "BOR Systems" string to "ZeroSlip"
    across iOS, Android, web, backend, firmware, Pi, and documentation.
    52 files changed.
    This commit ONLY touches display strings. Bundle IDs, package paths,
    and infrastructure URLs land in the next commit so we can revert
    either layer independently if anything looks off.
    [hanger_sim.py, install.py, main.cpp]
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2026-05-22 Rebrand: ZeroSlip → Zero Slip Systems (full company name)
    56 files changed:
    - All display strings "ZeroSlip" → "Zero Slip Systems"
    - Bundle IDs com.zeroslip.app → com.zeroslipsystems.app (iOS phone +
    watch, Android applicationId, backend default APNS_TOPIC)
    - SharedPreferences zeroslip_auth → zeroslipsystems_auth (phone + wear)
    - iOS Keychain service id com.zeroslip.app → com.zeroslipsystems.app
    Note on the long name: "Zero Slip Systems" exceeds the ~12-char limit
    iOS/Android use for home-screen icon labels — both OSes will truncate
    gracefully ("Zero Slip Sy…"). If the icon-label truncation looks bad
    after building, swap CFBundleDisplayName + android:label to a short
    form li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
    [hanger_sim.py, install.py, main.cpp]
2026-05-22 Rebrand: Zero Slip Systems → HazardLink (final name)
    - All display strings "Zero Slip Systems" → "HazardLink"
    - Bundle IDs com.zeroslipsystems.app → com.hazardlink.app (iOS phone +
    - SharedPreferences zeroslipsystems_auth → hazardlink_auth (phone + wear)
    - iOS Keychain service id → com.hazardlink.app
    Why this name (over Zero Slip, Alert Floor):
    - No direct competitor in cleaning/safety/IoT space (verified WebSearch)
    - No registered trademark in UK/IE/EU
    - hazardlink.com appears available (verify before committing $)
    - Distinctive 2-word combo → stronger trademark protection
    - "Link" implies IoT/sensor/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
    [hanger_sim.py, install.py, main.cpp]
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2026-05-29 Fix tsc errors blocking Render deploys + rebrand OLED to HazardLink
    Backend (the actual blocker)
    - public.ts: align audit-log insert with current schema — was using
    pre-rename column names (userId/entityType/entityId/detail) that no
    longer exist; switched to actorUserId/targetType/targetId/metadata
    - status.ts: events table has receivedAt, not createdAt — fix both refs
    - notifications.ts: drop the dead `kind === "dispatch"` branch (nothing
    in the codebase emits that kind; was a never-reachable code path that
    tripped a strict comparison error)
    - i18n.ts: noUncheckedIndexedAccess wants split()[0] coerced — `?? ""`
    - compliance-pdf.ts: same coercion for tuple destructuring
    These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
    [gateway.cpp]
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2026-05-29 Gateway: cap HTTPS timeouts so the loop stays responsive
    forwardToCloud and sendHeartbeat were both using HTTPClient + WiFiClientSecure
    with no explicit timeouts. ESP-IDF's defaults can hang for 30+ seconds during
    TLS handshake, and with the hanger spamming packets over LoRa the gateway
    loop was getting wedged in the first POST forever — no second heartbeat,
    no OLED refresh past the boot state, dashboard goes "Offline" while the
    device is provably still running.
    Fix: every HTTPS path now sets:
    - WiFiClientSecure.setTimeout(4) seconds — socket-level
    - HTTPClient.setConnectTimeout(5000) ms — TCP connect + TLS handshake
    - HTTPClient.setTimeout(5000) ms — full response window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
    [gateway.cpp]
2026-05-29 Gateway: set WiFiClientSecure handshake timeout
    Critical missing piece from the previous timeout fix. WiFiClientSecure's
    TLS handshake timeout defaults to 120 SECONDS, and setTimeout()/HTTPClient's
    setConnectTimeout() don't cover it. So a stuck handshake hangs the gateway
    loop for 2 minutes per attempt — exactly what we just observed: boot
    heartbeat goes through, then every subsequent heartbeat / forward hangs,
    OLED freezes, dashboard goes Offline.
    Set client.setHandshakeTimeout(5) on both forwardToCloud and sendHeartbeat
    so handshakes fail fast and the loop stays responsive even when Render
    or the WiFi link is having a moment.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
    [gateway.cpp]
2026-05-29 Hanger: stay awake with OLED on while USB-powered
    Previous behavior — boot, send one LoRa packet, immediately enter
    deep sleep with Vext cut — is correct for a deployed battery hanger
    (it's how we hit ~24 months on a 21700) but useless during install
    + bench testing. The installer can't tell the device is working;
    the dashboard's Online badge flips to Offline minutes after each
    power-on; reacting to a magnet edge requires an hour of waiting.
    Use Battery::isCharging() (which reads the VBUS sense pin) to fork
    the behavior:
    - USB powered (charging == true)
    Stay awake. Refresh OLED once a second showing the device
    suffix, USB/BATT label, battery %, sign present/lifted state,
    an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
    [hanger.cpp]
2026-05-29 Hanger: default to always-awake — gate deep-sleep behind BOR_HANGER_DEEP_SLEEP
    Bare Heltec V3 boards without our custom PCB don't have the VBUS sense
    divider wired to GPIO 4. `Battery::isCharging()` reads unreliably on
    those boards, the hanger thinks it's on battery, hits the deep-sleep
    path, cuts Vext, OLED goes dark. From the bench it looks broken.
    Until we have hangers actually deployed on batteries, default to the
    USB / stay-awake / OLED-on behavior. Gate the deep-sleep code behind
    a `BOR_HANGER_DEEP_SLEEP` build flag so we can flip it back on when
    the production PCB lands without rewriting the loop.
    [hanger.cpp]
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2026-05-30 Hanger: fix V3.2 battery read + debounce sign sensor
    Battery read (battery.cpp)
    - Heltec flipped the ADC-enable polarity between board revisions:
    V3.0/V3.1 enable the divider with ADC_Ctrl LOW, V3.2 with HIGH. Our
    firmware hardcoded LOW, so on the V3.2 boards TinyTronics now ships
    it disabled the divider and read 0% with a battery connected.
    Fix: sample with BOTH polarities, keep the larger (the disabled
    polarity reads ~0 mV, the enabled one reads the real divided voltage)
    — revision-agnostic, same binary works on every V3.
    - Switch raw analogRead × 3.3/4095 to analogReadMilliVolts() for the
    chip's factory ADC calibration (raw is badly nonlinear near the low
    end where the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
    [battery.cpp, hanger.cpp]
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2026-05-30 Gateway: fix the actual end-to-end forward (3 bugs)
    Serial logging finally exposed why real hanger packets never reached
    the cloud even though the LoRa link was healthy (hanger TX + gateway
    ACK both worked):
    1. JSON SHAPE MISMATCH (the show-stopper)
    forwardToCloud sent a flat {dev_eui, event, battery_pct, …} body,
    but /webhook/tts decodes the TTN/LoRaWAN uplink shape:
    end_device_ids.dev_eui + a base64 frm_payload (our 4-byte packet).
    The backend rejected every forward with 400 'missing dev_eui or
    frm_payload'. Synthetic curl tests used the right shape, which is
    why they passed while the real gateway silently failed the whole
    time. Now re-encode the decoded fields back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
    [gateway.cpp]
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2026-06-01 Fix fast hanger battery drain: real deep sleep + BLE discovery + wider online window
    THE BATTERY BUG: the hanger never slept. Deep sleep was behind a
    BOR_HANGER_DEEP_SLEEP #ifdef that was never set, AND the code used
    esp_sleep_enable_ext0_wakeup — ext0 doesn't exist on the ESP32-S3, so it
    could never have compiled in. Result: CPU + LoRa radio ran 24/7 and
    transmitted every 60s, flattening a cell in ~2-3 days (the "~24 month"
    comment was aspirational).
    Firmware fix:
    - Rewrote enterDeepSleep() for the S3: ext1 ANY_LOW on the Hall + PRG pins
    (via rtc_gpio pull config) for instant wake, plus the hourly timer, plus
    LoraLink::sleep() so the SX1262 isn't burning ~10mA through the sleep.
    - Ma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
    [hanger.cpp]
2026-06-01 Fix hanger deep-sleep wake-loop: wake-on-change + self-healing Hall guard
    The first deep-sleep pass (be24110) had a wake-loop bug that drained the
    battery FASTER than no sleep: ext1 ANY_LOW on the Hall + PRG pins fired
    instantly because the Hall pin rests LOW with the sign on the hook (the
    normal state), and the PRG pin can't share a single ext1 polarity. Worse,
    on a board whose Hall sensor is absent/unpowered/flaky, GPIO6 floats across
    the wake threshold and triggers a spurious ext1 wake roughly every ~1.8s —
    a continuous reboot loop.
    Fixes:
    - Wake-on-CHANGE: read the Hall level at sleep time and arm ext1 for the
    OPPOSITE level (sign on→wake on lift; sign off→wake on re-hang), hold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
    [hanger.cpp]
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2026-06-01 Fix instant sign-lifted alerts: 3 firmware bugs that suppressed spill events
    Reported: sign-lifted alerts not sending instantly. Three real bugs (all
    introduced by the deep-sleep work) found + fixed:
    1. Noise guard silently disabled instant alerts during NORMAL use. It
    dropped the Hall wake after N ext1 wakes between timer wakes — fine when
    the timer was hourly, but after moving to a DAILY check-in, the 5th real
    sign-lift of the day would disable instant alerts until the next day.
    Rewritten to count only NO-CHANGE wakes: compare the debounced sign level
    to the level we slept at. A real lift/return flips it → counter resets →
    instant alerts stay armed no matter how bu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
    [hanger.cpp]
2026-06-01 Hanger: stream battery % while USB-charging, sleep when unplugged
    Per request: while charging over USB-C, stay awake and report the battery
    percentage to the cloud every 30s (live "charging, NN%"); when unplugged,
    fall straight back to the deep-sleep operation (daily check-in + instant
    Hall wake).
    Charge detection: the bare Heltec V3's VBUS-sense pin (GPIO4) isn't
    populated — measured raw≈107/4095 while plugged in, so isCharging() can't
    see USB on this hardware. Added Battery::chargingByVoltage(): infers
    charging from the battery-VOLTAGE TREND (rising over a ~30s window, or
    pinned ≥4.15V), with a ring buffer + hysteresis to ride out ADC noise.
    Works on any board, no extra wiring. The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
    [battery.cpp, hanger.cpp]
2026-06-01 Hanger: fix alert-not-closing + cap floating-pin noise wakes
    Two related fixes from a real end-to-end bench test (battery + GPIO6↔GND
    jumper):
    1. ALERT WOULDN'T CLOSE. The old "self-heal" guard, on seeing floating-pin
    noise after a lift, PERMANENTLY disabled the Hall wake. So when the sign
    went back on the hook ("Returned"), the device never woke → the event
    never sent → the alert stayed open forever. Fix: never disable the wake.
    A no-change (noise) wake is now handled as a cheap re-sleep that stays
    armed, so the genuine return is always caught and the alert closes.
    2. FLOATING PIN DRAINED THE BATTERY. With a bare/dangling wire (no driven
    sensor), GPIO6 floats and t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
    [hanger.cpp]
2026-06-01 Hanger: make floating-pin noise backoff actually work (disarm Hall during backoff)
    The previous backoff only lengthened the TIMER wake, but a floating pin
    re-trips the ext1 (Hall) interrupt in ~0.5s — far sooner than any timer —
    so the noise wakes kept firing twice a second (verified: noise #69 in 95s).
    A longer timer is a ceiling, not a floor.
    Fix: enterDeepSleep() gains an armHall flag. During a noise backoff we sleep
    TIMER-ONLY with the Hall wake disarmed, which is the only thing that can
    actually stop the floating pin re-triggering. It re-arms on the very next
    wake. Backoff caps at 8s (down from 64s) so worst-case real-transition
    latency on a genuinely broken/floating pin is ≤8s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
    [hanger.cpp]
2026-06-01 Hanger: guarantee alert-close — reconcile sign state vs cloud on every wake
    Reported: breaking then remaking the switch (sign returned) didn't clear the
    active alert on the website. Root cause: the firmware only sent a Returned
    event on a clean Hall-wake-with-change. If the return instead landed during a
    noise backoff (Hall disarmed) or on a timer wake, the code sent a generic
    Heartbeat — which the webhook does NOT treat as a close — so the alert stayed
    open forever.
    Fix: track the last sign state the cloud actually heard (g_rtcReportedOnHook,
    in RTC memory) and, on EVERY wake, reconcile it against the live debounced
    state. If they differ, send the exact Lifted/Returned transition —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
    [hanger.cpp]
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2026-06-17 Mobile parity for staff invites (iOS + Android)
    iOS: the "New user" sheet becomes "Invite staff" — drops the password field,
    posts sendInvite:true, and shows a confirmation ("Invite emailed to …", or a
    copyable link if SMTP can't send). Roster shows "invited — pending" and a
    swipe-to-Resend action for admins. APIClient.inviteUser/resendInvite replace
    createUser.
    Android: roster (already read-only, defers adding to web) now shows the
    "Invited — pending" badge. UserSummary gains invitedAt/inviteAcceptedAt.
    Both build clean (iOS BUILD SUCCEEDED, Android BUILD SUCCESSFUL). Backend is
    back-compat, so older app builds keep working via the password path.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
    [Models.kt]
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2026-06-21 android: real security data in Needs-attention + SecurityKpiHeader (incidents, missed patrols, lone-worker)
    [Models.kt]
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2026-08-21 Android: estate structure + native Incidents and Visitors
    Same spec as web / Mac / iPhone: Sites now shows the estate (live totals
    + per-site cards from /sites/overview) and each site's page breaks down
    into Cleaning, Maintenance and Security with that site's live numbers.
    New IncidentsScreen (report from the spot with severity/site chips,
    staff resolve) and VisitorsScreen (On site / Expected / History tabs,
    walk-in and expected booking, sign in/out) wired into More and nav.
    [Models.kt]
2026-08-22 Android: fix estate/incidents build on existing models
    Reuse the existing SecurityIncident model and securityIncidents() call
    instead of duplicating them, compare roles via the UserRole enum, and
    use the clickable Card overload.
    [Models.kt]
2026-08-22 Android: Timesheets, Leave, Forms, Permits, Compliance
    The five business sections the phone was missing vs web/Mac/iPhone,
    on the same endpoints: clock in/out + weekly entries + staff approve;
    book leave + approve/decline; fill active forms (mixed-type answers as
    the web builder expects); request permits + the approve/activate/close
    lifecycle; the statutory compliance register grouped by category with
    mark-done-today. All wired into nav and More.
    [Models.kt]
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2026-09-03 hardware: v8 printable enclosures for the hanger and gateway
    CadQuery source (hardware/enclosures/v8/final/hazardlink_enclosures.py) built
    from the bought parts: Heltec WiFi LoRa 32 V3, Samsung 21700 in its holder,
    DRV5032 Hall sensor, magnets; gateway with SMA pigtail and USB-C PSU.
    Hanger = plain slab face (OLED window, PRG, RST, LED) with the sign hanging
    from a bar under the bottom edge and the lift sensor under the saddle.
    Gateway = screwed lid, OLED window, SMA on top, vents, cable saddle.
    Design rules (magnet gap, reach, skins, keep-outs) are checked in code;
    --check prints an interference report. STEP, drawing DXF and PNG previews
    committed; STL, ACIS .sat and 3DSOLID DXF are regener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
    [HTIT-WB32LAF_V3.7_detailed_pcb_no_oled_no_headers.step, V3_simplified_envelope_with_oled.step, WiFi_LoRa32_V3_mechanical.dwg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]
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2026-09-04 hardware: v9 enclosures with no screws in the assembly
    Snap-fit lids (hinge tabs into rib pockets at the top, 55-degree spring
    latches with paperclip release holes at the bottom), a 45-degree dovetail
    on the hook bar that slides in from the wall side and is covered by the
    backplate, and a spring catch with a push pad on the backplate in place of
    the security screw. Review fixes folded in: the wall keyholes were built
    upside down in v8 (the security screw had been carrying the unit) and are
    now head-circle-below, slot-up on both units; nothing of the bar sits
    behind the body so it lifts clear of the backplate; the catch cavity is
    open to the back face for support; peg heads get a 45-degree co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
    [gateway_assembly.step, gateway_body.step, gateway_body_drawing.dxf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]
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2026-09-18 hardware: v9.2 hanger after the first real print: springs in the body wall, display flush with the face
    Owen's PLA lid showed three faults. The latch fingers stood on the lid, so
    they bent across the layer lines and snapped: the spring is now an arm cut
    into the body's bottom wall (prints along its length, 0.68 percent strain)
    and the lid carries only a rigid hook. The display sat 5.5 mm down a well on
    tall ribs: the board now sits right behind the lid, glass 1.2 mm below the
    face behind a 1 mm bezel (OLED_H_MAX to be measured), with reliefs for the
    USB shell and U.FL plug, and the lid lip closing the USB notch (port is used
    with the lid off). The label recess printed over nothing on the bed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
    [gateway_assembly.step, gateway_body.step, gateway_body_drawing.dxf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]
2026-09-18 hardware: every component positively held, plus a staged assembly view for AutoCAD
    audit_retention.py moves each bought part (and each printed part) in all six
    directions and reports the free travel before something stops it. It found
    the battery holder free to move 8 mm toward the lid, the antenna rod free to
    slide out of its clips, and the Hall carrier free to slide back out of the
    bar. Fixed with two lid posts on the holder's end blocks and two ribs in
    front of the cell, a slotted shelf under the antenna rod and a stop above it,
    and a drop-in filament pin behind the Hall carrier under the sign handle.
    Bar fore-aft play cut to 0.5 mm. All parts now within 0.5 mm (cell 1.3 mm
    along its axis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
    [S0_bar.step, S0_magnet.step, S0_sensor.step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]
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2026-09-18 hardware: v9.3 hanger and gateway: big button pads, logo on the face, centred display, wide hook bar, shorter lead route
    Buttons: two 24 x 15 mm pads in each lid, each a flap with a 0.8 mm hinge
    (prints flat, bends along the layers, 0.43 percent strain) and a pin over the
    board's PRG / RST switch; LED light hole in the RST pad. The hanger board
    moves right so the display is centred and the pads fit beside it.
    Face marks: tilted badge with exclamation mark, HazardLink wordmark and the
    button names sunk 0.4 mm as narrow strokes; matching *_inlay.stl exported in
    register with the lid for a flush second-colour print on the other hotend.
    Hook bar: T-shaped, BAR_W 95 mm (provisional until the sign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
    [S0_bar.step, S0_magnet.step, S0_sensor.step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]
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2026-09-18 hardware: v9.5 board and battery holder stay clipped in with the lid off
    audit_retention.py gained a lid-off mode (AUDIT_ARGS=--lid-off). It showed
    the board and the battery holder were only stopped from coming forward by
    the lid. Added a 45-degree catch on each board pocket wall over the PCB's
    long edges (both units; lid ribs gapped to clear them) and a snap arm at each
    end of the battery holder. These flex across the print layers, so they are
    held to 0.15 and 0.40 percent strain against a 0.7 percent limit. Lid off:
    board, holder, cell and antenna all within 0.9 mm in every direction.
    [gateway_assembly.step, gateway_body.step, gateway_body_drawing.dxf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]
2026-09-18 hardware: v9.6 sized for the parts actually delivered
    From the TinyTronics packing slip and Owen's photos: Murata US18650VTC6
    cells in BeiLaMoo 18650-PC2 holders (77.7 x 20.9 x 21.3, solder pins), not
    the 21700 parts the shopping list named; 6x2 N52 magnets; SMA bulkhead
    pigtail with a 9.5 x 47 mm stubby antenna. Holder now stands on 4 mm ribs
    for its pins and wires, bay/arms/lid posts resized, 4 mm lead passage under
    it and the bulkhead slot moved forward. Antenna mounted inside: jack in a
    slotted shelf clamped by its own nut, body in a clip; top knock-out remains
    for an outside antenna. Checks, interference, cable route and both retention
    audits pass. SHOPPING.md annotated with what was de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
    [gateway_assembly.step, gateway_body.step, gateway_body_drawing.dxf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]
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2026-09-18 Enclosures v9.8: fixes from the independent review of v9.7
    - Hook bar: 45 deg gusset carries the front of the dovetail plate, so the bar prints
    with no support (bed supports could not reach it; support everywhere would have
    filled the sensor tunnel)
    - Sensor cavity: every level on a 0.2 mm layer, 0.35 mm over and under the package,
    pin holes open through the bridged roof in stages (slot, square, round), 2 mm
    push-out and drain hole under each pin, ramp at the end of the wire trench and a
    funnel into the nest so the package cannot catch on a step or shoulder
    - Battery holder snap arms slotted free of the end ribs: real free length 24 mm,
    strain 0.41 to 0.66 percent (the old check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
    [S0_bar.step, S0_magnet.step, S0_sensor.step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]
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
